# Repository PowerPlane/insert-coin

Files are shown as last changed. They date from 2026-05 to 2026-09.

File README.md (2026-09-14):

# Insert Coin

> A series of interactive business cards that come to life when you insert a CR2032 coin cell.
> Inspired by the Target gift cards of the early 2000s.

The "Insert Coin" cards are PCB-as-business-card builds where the coin cell is the *user interaction*: slide it into the holder and the card boots, blinks, listens, taps NFC, then sleeps. Different variants explore different form factors, sensor sets, and animations under the same playful idea.

## Variants

| Slug | Form factor | MCU | Status | Notes |
|---|---|---|---|---|
| [`business-card-v1`](variants/business-card-v1/) | Business card (85 × 54 mm) | ATtiny1616 | Hardware done, firmware pending | 24-LED matrix, MEMS mic, ST25DV04K NFC tag |

## Repo layout

```
insert-coin/
├── docs/                       # cross-variant notes, photos, renders
├── shared/                     # things reused across variants
│   ├── kicad/                  # symbols, footprints, 3D models
│   ├── firmware/               # shared HAL/drivers (LED matrix, NFC, mic)
│   └── tools/                  # build-hex.sh, gerber gen helpers
└── variants/<slug>/
    ├── hardware/               # KiCad project + fab outputs
    ├── firmware/               # PlatformIO project (bringup + production envs)
    └── enclosure/              # 3D-printed sleeves / holders (CAD)
```

## Adding a new variant

Use the slug pattern `<form-factor>-v<n>`:
- `business-card-v2` — next rev of the business-card form factor
- `keychain-v1`, `coaster-v1`, `badge-v1` — new form factors

Copy the structure of `variants/business-card-v1/` (without the KiCad files) as a starting point.

## Firmware toolchain

[PlatformIO](https://platformio.org/) + [megaTinyCore](https://github.com/SpenceKonde/megaTinyCore) targeting the ATtiny1616 over **UPDI**. Default programmer: SerialUPDI through an FTDI USB-serial adapter (one 4.7 kΩ resistor between TX and RX). Per-variant `firmware/README.md` has the wiring diagram and build commands.

No PlatformIO on the machine? [`docs/flasher/`](docs/flasher/README.md) is a browser page at `ducky.davidyang.work/flash` that flashes a card through an Adafruit UPDI Friend. David builds the `.hex` with `shared/tools/build-hex.sh` and sends it; the page does the rest.

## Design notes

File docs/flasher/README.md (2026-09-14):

# The web flasher

Put firmware on an Insert Coin card from a browser. Nothing to install.

**https://ducky.davidyang.work/flash** · Chrome or Edge, on a laptop.

Made so a friend with an [Adafruit UPDI Friend](https://www.adafruit.com/product/5879)
can flash cards without PlatformIO. The page talks UPDI to the ATtiny1616
through the browser's Web Serial API, the same way `pio run -t upload`
does through avrdude. The firmware file never touches a server.

---

## 1 · Flashing a card (for whoever holds the UPDI Friend)

You need: a UPDI Friend, its cable, a card with a **fresh** CR2032 in it,
the `.hex` file David sent, and a laptop running Chrome or Edge.

1. **Set the UPDI Friend's switch to 3V.** The card runs at coin-cell
   voltage. 5V on the UPDI pin is out of spec for the chip.
2. **Wire two pins.** UPDI Friend `UPDI` to the card's `UPDI` pad, `GND`
   to `GND`. **Leave `VCC` unconnected.** The card is powered by its own
   coin cell while flashing.
3. **Open the page** and drop the `.hex` on it. It shows the file's size
   and the first eight characters of its SHA-256. Read those to David if
   you want to be sure it is the right file.
4. **Press Flash.** The first time, the browser asks which USB port; pick
   the UPDI Friend (it shows as a CH340 or "USB Serial"). Five rows tick
   off in about ten seconds: Connect, Check the chip, Write, Verify, Fuses.
5. **Done says the card's serial.** Pull the coin cell out, put it back,
   and the card should light up. The file stays loaded: swap the card and
   press Flash again.

If a row turns red, the page says what happened, whether the card is fine,
and what to check. **Show details** has the log if David asks for it.

| It says | It means | Do |
| --- | --- | --- |
| Open this in Chrome or Edge | This browser has no Web Serial. | Copy the link into Chrome or Edge on a laptop. Phones cannot do this. |
| The USB port is busy | Something else has the port open. | Close the Arduino IDE or any serial monitor, unplug and replug, press Flash. |
| The card did not answer | No reply on the UPDI wire. Nothing was written. | Coin cell in and fresh? UPDI on UPDI, GND on GND? Switch at 3V? Replug. |
| That is not an Insert Coin card | The chip is not an ATtiny1616. Nothing was written. | Check what the cable is clipped to. |
| Writing stopped part way | The card is half-written. | Fresh coin cell, then Flash again. Nothing is lost. |
| Read back differently | One byte did not stick. | Almost always the battery. Fresh cell, Flash again. Slow mode in Details if it repeats. |
| A setting did not take | Code is on; a fuse read back wrong. | Flash again. Twice in a row, send the card back with the details. |
| This chip is locked | Lock bits are set. This page does not erase locked chips. | Send the card back to David. |

---

## 2 · Making the file (for David)

```bash
shared/tools/build-hex.sh                 # production-pond → ~/Desktop
shared/tools/build-hex.sh bringup ~/tmp   # any env, any folder
```

It runs `pio run -e <env>`, copies the result out of `.pio/build/` with
the commit hash in the name, and prints the SHA-256. Send that file
however you like: AirDrop, email, a chat. Then read the first eight
characters of the hash to each other.

**The file is not hosted anywhere, and must not be.** The pond firmware
carries `FIRMWARE_SECRET`, the key every card signs its claims with. The
repository is public, so a committed or served `.hex` would publish the
key. The script refuses to build `production-pond` with the all-zero
placeholder key, because a card built with it never registers in the
pond and the only symptom is silence.

---

## 3 · How it works

```
 browser tab ── Web Serial ── USB ── UPDI Friend (CH340E + 1 kΩ) ── UPDI pin ── ATtiny1616
   flash.js                                                           ↑ card powers itself
```

The page bundles a TypeScript port of Microchip's SerialUPDI stack
([WebUPDI](https://github.com/manuelkasper/webupdi), MIT), so the
protocol on the wire is the one pymcuprog and avrdude speak. On top of it
sits a short, tested sequence:

1. **Connect** at 230400 baud; if the chip is silent, close the port and
   try 115200.
2. **Check the chip.** Read the device id. Anything but `0x1E9421` stops
   here, before a single write. Read the factory serial number and derive
   the card serial the same way the firmware and the server do.
3. **Write** all 256 flash pages: erase-and-write for pages with content,
   plain erase for blank ones.
4. **Verify** by reading the whole 16 kB back and comparing.
5. **Fuses.** Write the eight fuse bytes `platformio.ini` describes, read
   them back, compare.
6. **Leave programming mode.** The chip resets and boots the new code.

One order, no branches: the flasher does exactly this or stops with a
named reason.

---

## 4 · What it writes, and what it never touches

**Flash**: every page, from the `.hex`. Pages the file does not mention
are erased (0xFF), so nothing from an older firmware survives.

**Fuses**, byte for byte what `pio run -t fuses` would write from
`platformio.ini`. A test recomputes this table from the ini file with
PlatformIO's own rules, so the two cannot drift.

| Fuse | Value | Why |
| --- | --- | --- |
| WDTCFG | 0x00 | watchdog off |
| BODCFG | 0x00 | brown-out detector off, so the coin cell fades instead of reset-looping |
| OSCCFG | 0x02 | 20 MHz oscillator, divided to 10 MHz in code |
| TCD0CFG | 0x00 | defaults; the LED PWM sets TCD0 up itself |
| SYSCFG0 | 0xC5 | EEPROM kept across reflash, UPDI pin stays UPDI |
| SYSCFG1 | 0x06 | 32 ms start-up |
| APPEND | 0x00 | no application data section |
| BOOTEND | 0x00 | no bootloader |

Note that PlatformIO only writes fuses on `pio run -t fuses`, not on
`upload`. The web flasher writes them every time, so a card flashed here
has the fuses the ini asks for whether or not the bench ever ran that
target.

**Never touched:**

- **EEPROM.** The claim counter lives there (`provision.h`). The flasher
  uses page operations only and never issues a chip erase, so EEPROM is
  preserved even on a card whose EESAVE fuse was never set.
- **Lock bits.** Not written; a locked chip is refused rather than erased.
- **The user row.** Nothing on the card uses it.
- **The firmware sources.** This feature adds a page, a script and docs.
  No file under `variants/*/firmware/` changed.

---

## 5 · Where things live

```
pond/
  api/flash.ts                 the route (a function, like every HTML route)
  src/worker/flash-shell.ts    the page's HTML
  src/flasher/
    main.ts                    the page's behaviour: states, copy, port picking
    flasher.ts                 the sequence in § 3, over an interface a test can fake
    hex.ts                     Intel HEX → flash image, strict about what it accepts
    plan.ts                    image → page operations
    target.ts                  ATtiny1616 addresses and the fuse table
    explain.ts                 what the page says when it fails
    digest.ts                  SHA-256 of the dropped file
    serialupdi/                vendored WebUPDI, MIT; VENDORED.md lists every edit
  public/flash.js, flash.css   the committed bundle and stylesheet
  test/flasher-*.test.ts       hex, plan, fuse table vs platformio.ini, the flow
                               against a fake chip, the page against its script
shared/tools/build-hex.sh      David's side: build, name, hash, hand over
```

Design canvas (the screens, in the pond's language):
https://claude.ai/code/artifact/b278c922-17a4-4562-9c67-462ab4460528

---

## 6 · Decision log

| Decision | Chosen | Instead of | Why |
| --- | --- | --- | --- |
| Where the page lives | `/flash` on the pond, a Vercel function | GitHub Pages, a separate site | Deploys with the pond, inherits its security headers, and the pond already has the rule that every HTML route is a function. |
| Where the firmware comes from | Dropped on the page by the friend | Served from the page, fetched from a release | The pond `.hex` contains the signing key and the repo is public. Hosting it anywhere publishes the key. |
| Protocol stack | Vendored WebUPDI `serialupdi/` | Writing UPDI from scratch, `@types` + npm | It is a straight port of pymcuprog, MIT, and not on npm. Vendoring with a change list keeps updates a diff. |
| Only one chip | Refuse anything but `0x1E9421` | A device picker | A friend should not be choosing chips. A v2 board adds a second target, not a dropdown. |
| No chip erase | Page erase and erase-and-write on all 256 pages | Chip erase then write used pages | Chip erase wipes EEPROM unless EESAVE is already set, and PlatformIO's `upload` never sets fuses. Page ops leave EEPROM alone whatever the fuses say. |
| Fuses written every time | The eight bytes from `platformio.ini`, verified | Leave fuses as found | The ini is the spec; a card should not depend on whether the bench remembered `-t fuses`. Lock bits and reserved bytes are excluded. |
| Fuses after flash | Verify flash, then fuses | Fuses first | A failure part way leaves old fuses and new code, which still runs. |
| Baud | 230400 then 115200 | One baud, or a picker | megaTinyCore's tuned default first; the fallback covers a slow adapter. "Slow mode" in Details pins 115200 for the stubborn case. |
| Port picker filter | WCH and FTDI vendor ids | Every serial port | On a Mac the list otherwise includes every paired Bluetooth device; `platformio.ini` tells the story of the Bose speaker. Details has "show every port". |
| Verification | Whole flash read back, and fuses read back masked for reserved bits | Trust the write | A weak coin cell is the realistic failure and a silent one. |
| File identity | SHA-256 shown on both ends | Version strings in the file | Two humans reading eight characters to each other needs no format and survives renaming. |
| Errors | Named codes, plain copy, `touched` flag | The stack's messages | The person reading has a card in their hand. The copy says whether it is fine before it says what to try. |
| Copy language | English only | The pond's bilingual strings | Two readers, both known. |
| Reviews | `/code-review` after each phase | `codex:rescue` | That skill is not available in this session; noted, not substituted silently. |

---

## 7 · Change log

| Date | Change | Why |
| --- | --- | --- |
| 2026-09-14 | Web flasher added at `/flash` | Flash cards from a browser with a UPDI Friend, no PlatformIO. |
| 2026-09-14 | `shared/tools/build-hex.sh` | One command to build, name and hash the file to send. Refuses the placeholder key. |
| 2026-09-14 | Vendored WebUPDI with fixes | Double break was not awaited (one break, not two); read timeouts were never cleared; `device` typed instead of `any`. |
| 2026-09-14 | Baud fallback releases the port between attempts | A leaked port made the second attempt report "port busy" for a loose wire. Found in review. |
| 2026-09-14 | Extended addresses multiplied, not shifted | `0x8000 << 16` is negative in JavaScript, and the data silently vanished. Found in review. |
| 2026-09-14 | `[hidden]` rule in flash.css | Flex containers outranked the browser's `hidden`; every state showed at once. Found in review. |
| 2026-09-14 | Deploy-shape test checks every bundle | It compared `main.js` only, so a stale `flash.js` would have shipped. |
| 2026-09-14 | Link errors named by the phase they interrupt | A wire slipping during verify was reported as a half-written card. Found in review. |
| 2026-09-14 | A newer AVR family is "wrong chip", not "no answer" | An AVR Dx answers the SIB and was retried at every baud, then blamed on wiring. Found in review. |
| 2026-09-14 | `vercel.json` no-cache rule covers the bundles that exist | The rule named `app.js`, which is not a file; `main.js` and `admin.js` were never covered. The flash rule had copied the mistake. |

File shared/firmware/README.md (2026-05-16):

# shared/firmware

Reusable firmware modules that span multiple variants.

Empty for now — populate as patterns emerge while writing `business-card-v1`'s bring-up and production firmware. Likely first extractions:

- **LED matrix driver** — charlieplexing / row-column scanning helpers, ISR-driven from TCD0.
- **ST25DV04K NFC tag driver** — I²C wrapper for reading/writing the user EEPROM (NDEF URL records).
- **Mic envelope tracker** — ADC sampling + low-pass envelope, threshold-based wake.
- **Coin-cell power management** — sleep helpers tuned for the CR2032 budget (deep sleep with RTC wake, peripheral power-gating).

When extracted, each module should be drop-in includable from a variant's `firmware/<env>/src/` via PlatformIO's `lib_extra_dirs` or a `lib_deps` `file://` reference.

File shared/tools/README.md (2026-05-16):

# shared/tools

Helper scripts that aren't variant-specific.

Empty for now. Expected occupants:

- `flash.sh` — convenience wrapper around `pio run -e <env> -t upload` that picks up the FTDI port automatically.
- `gen-gerbers.sh` — KiCad CLI command for regenerating fab outputs without opening the GUI.
- `bom-merge.py` — merge a variant's `bom.csv` with shared part-numbers from a master spreadsheet, if we ever centralize sourcing.

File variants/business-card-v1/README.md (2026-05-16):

# business-card-v1

The first Insert Coin variant: a 2-layer PCB cut to standard business-card size with a CR2032 holder on the front, a 24-LED matrix, a MEMS microphone, and an NFC tag.

## Highlights

| | |
|---|---|
| **Form factor** | Business card — roughly 85 × 54 mm |
| **MCU** | ATtiny1616-M (Microchip, AVR tinyAVR 1-series, 16 kB flash, 2 kB SRAM, VQFN-20) |
| **Power** | CR2032 coin cell (the "coin" you insert to activate the card) |
| **Display** | 24 × red LEDs driven through 9 MOSFETs (multiplexed matrix) |
| **Audio in** | 1 × MEMS microphone (ZTS6156) — sound-reactive interaction |
| **NFC** | ST25DV04K-IER8C3 (I²C dynamic NFC tag, 4 Kb EEPROM, tap-to-launch URL) |
| **Programming** | UPDI (single-wire) via SerialUPDI |

## Status

- ✅ **Hardware**: Schematic + layout complete (KiCad), fab package generated.
- ⏳ **Firmware**: Bring-up and production firmware planned — see [`firmware/`](firmware/).
- ⏳ **Enclosure**: 3D-printed sleeve / mailer holder — see [`enclosure/`](enclosure/).

## Known caveats

- The fab zip inside [`hardware/production/`](hardware/production/) is named `Ducky-Business-Card_0-1.zip` — a leftover from a forked fabrication-toolkit config. The board *itself* is the Insert Coin design; only the zip filename is wrong. Will be corrected on the next fab run.

## Hardware files

- `hardware/Insert-Coin-Business-Card.kicad_pro` — open this in KiCad to view the schematic and PCB.
- `hardware/production/` — BOM (`bom.csv`), pick-and-place positions (`positions.csv`), designator map, IPC netlist, and the (mis-named) fab zip.

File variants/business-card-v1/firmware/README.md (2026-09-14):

# business-card-v1 firmware

Two PlatformIO environments in one project share the same `platformio.ini`:

| Env | Purpose |
|---|---|
| **`bringup`** | Smoke tests for each subsystem — exercise every LED, read the mic, scan I²C for the NFC tag, verify sleep/wake. The first thing you flash on a freshly-soldered card. |
| **`production`** | The real interactive firmware: boot animation, idle low-power, mic-reactive pattern, NFC-tap drops a URL. The firmware that ships on cards you hand out. |

The actual source code is **not yet written** — that's the next session. The `src/` folders are empty placeholders.

## Toolchain

- **[PlatformIO Core](https://platformio.org/install/cli)** (`pip install platformio` or via Homebrew).
- **[megaTinyCore](https://github.com/SpenceKonde/megaTinyCore)** — pulled in automatically by `platformio.ini`. This is the Arduino-style core for the tinyAVR 0/1/2-series and exposes the ATtiny1616's modern peripherals (Event System, Configurable Custom Logic, TCD high-res timer) as easy-to-use APIs.

## Programmer wiring

> **No PlatformIO handy?** `docs/flasher/README.md` describes a browser page that flashes a built `.hex` through an Adafruit UPDI Friend. Same fuses, same result. Build the file here with `shared/tools/build-hex.sh`.

The ATtiny1616 uses **UPDI**, Microchip's 1-wire programming protocol. No bootloader is required (and no bootloader is on the board) — UPDI talks directly to the chip's NVM controller.

### Primary path: SerialUPDI via FTDI (recommended)

```
   FTDI TX ──[ 4.7 kΩ ]──┬── UPDI pin on card
                          │
   FTDI RX ───────────────┘
   FTDI GND ─────────────────── GND on card
```

- The single resistor between TX and RX merges them into the half-duplex UPDI line.
- Power the card from the CR2032 during flashing — **do not back-feed Vcc from the FTDI**, the LDO and chip share a node sized for the coin cell.
- Upload speed: 230400 baud (megaTinyCore's tuned default).

`platformio.ini` is preconfigured for this path. Set `upload_port` to your FTDI:

```bash
ls /dev/cu.usbserial-* /dev/cu.usbmodem*    # find your adapter on macOS
pio run -e bringup -t upload --upload-port /dev/cu.usbserial-XXXX
```

### Fallback path: jtag2updi on an Arduino Nano

If the FTDI is unavailable, flash the [`jtag2updi`](https://github.com/ElTangas/jtag2updi) sketch onto an Arduino Nano once (it becomes a permanent UPDI programmer), then:

```
   Nano D6 ──[ 4.7 kΩ ]── UPDI pin on card
   Nano GND ────────────── GND on card
```

Switch the env's `upload_protocol` to `jtag2updi`:

```ini
upload_protocol = jtag2updi
upload_speed    = 19200
```

Slower than SerialUPDI but works fine for low-iteration use.

## Fuse / clock settings

Configured in `platformio.ini` so they're consistent across builds:

- `F_CPU = 10000000` — 10 MHz internal oscillator. The 20 MHz option is more headroom but eats more current; 10 MHz is the megaTinyCore default and friendlier to the CR2032 budget.
- **BOD off** — Brown-Out Detector disabled. BOD continuously sips ~20 µA which dominates the sleep current; the card is supposed to *gracefully* die when the coin cell sags, not reset-loop.
- Millis timer: **TCB0** (so TCD0 stays free for high-resolution LED PWM later).

## Build & flash

```bash
cd insert-coin/variants/business-card-v1/firmware

pio run -e bringup              # compile bring-up
pio run -e bringup -t upload    # flash bring-up
pio device monitor -b 115200    # open serial (if UART debug is wired)

pio run -e production -t upload # flash production firmware
```

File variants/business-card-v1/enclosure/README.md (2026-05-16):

# business-card-v1 enclosure

Placeholder for the 3D-printable sleeve / display holder. Drop CAD files here as they're designed:

- `*.f3d` — Fusion 360 source files
- `*.step` — neutral CAD interchange (preferred for sharing)
- `*.stl` — slicer-ready meshes
- `*.3mf` — preferred print-job format (slicer settings travel with the geometry)

Likely first artifact: a thin cardboard-sleeve-style mailer holder that exposes the LED window and the coin-cell slot, so the card can be handed out without the cell pre-inserted.

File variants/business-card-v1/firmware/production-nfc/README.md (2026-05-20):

# production-nfc firmware

(Same overall behavior as `production/`, plus a post-reveal I2C patch
of the ST25DV04K NDEF EEPROM so a phone tap surfaces the fortune
result. See `docs/nfc-ducky/` for the on-tag URL contract and the
Cargo.site snippet.)

Interactive firmware for business-card-v1. One coin insertion = one fortune.

## What it does

Coin makes contact → MCU boots → runs a single forward pass:

1. **Boot capture** — bank 0 (ducky frame 1) eases up to full, dips, recovers, holds.
2. **Ducky walk** — banks 0→1→2→3 hard-cut stop-motion with eased dwell pacing.
3. **Lottery** — slot-machine spin across banks 4 / 5 / 6 / 7+8, then a hardware-seeded random pick from { great, little, uncertain, bad }.
4. **Reveal** — per-fortune scene (see below).
5. **Sleep forever** — `SLEEP_MODE_PWR_DOWN` with no wake source. Pull the coin to reset.

## Reveal scenes

| Fortune | Bank(s) | Animation |
|---|---|---|
| Great luck | 4 | 3× blink, 15 s static hold (sleeps through the hold) |
| Little luck  | 5 | 2× blink, 15 s static hold (sleeps through the hold) |
| Uncertain | 6 | Eased ramp, then eased breathing for ~15 s, soft fade-off |
| Bad luck | 7+8 | Two-stream candle flicker until mic detects a sustained blow (≥100 ms above threshold), then a flare-up + fast fade. 60 s timeout. |

The NFC tag (ST25DV04K) is RF-powered and ignored by the MCU — tap-to-URL works independently of the coin.

## Power

- BOD off, `millis()` on TCB0, ADC0 disabled at boot, ADC1 disabled after the lottery on non-fire reveals.
- 15 s holds use the RTC PIT at 1 Hz to drop into deep sleep with the GPIO output latched high — chip current goes from ~5 mA active to <10 µA while the bank stays lit.
- After the show: `sleep_forever()` disables both ADCs, kills every input buffer except UPDI, and parks in `PWR_DOWN` until cold boot.
- Target: < 1 µA quiescent after shutdown, comfortable headroom on a CR2032 for hundreds of activations.

## Source layout

```
src/
  main.cpp            entry point; runs the show then sleeps
  anim.{h,cpp}        scripted scenes (boot capture, walk, lottery, reveals)
  flame.{h,cpp}       two-stream candle flicker for banks 7+8
  pwm.{h,cpp}         9-bank software PWM with eased fade/hold helpers
  mic.{h,cpp}         ADC1 envelope + raw-threshold blow detector
  rng.{h,cpp}         xorshift32 seeded from ADC LSB noise on the mic pin
  sleepy.{h,cpp}      RTC-PIT timed sleep + terminal deep sleep
  leds.{h,cpp}        bank MOSFET driver (verbatim from bringup)
  pins.h              pin map + bank/fortune semantic indices
  unused_pins.h       input-buffer-disable for everything PCB-unused
  config.h            all timings, thresholds, RNG sample counts
```

## Build & flash

```
cd insert-coin/variants/business-card-v1/firmware
pio run -e production-nfc
pio run -e production-nfc -t upload --upload-port /dev/cu.usbserial-XXXX
```

`FORCE_FORTUNE` (set in `config.h` or via `-DFORCE_FORTUNE=3` build flag) skips the lottery for blow-out tuning. Defaults to `-1` (real RNG).

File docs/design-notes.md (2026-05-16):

# Insert Coin — design notes

Concept and constraints that apply across variants. Variant-specific notes belong in `variants/<slug>/README.md`.

## The concept

The card does nothing until you slide a CR2032 into the holder. That gesture *is* the interaction — the "insert coin" of an arcade cabinet, the "scratch here" of a Target gift card from 2002. The card lights up briefly, listens, responds, then quiets down.

Each variant should preserve that core feel: **no buttons, no switches, no USB.** Inserting the coin is the only thing you do.

## Shared constraints

| | |
|---|---|
| **Power budget** | 1 × CR2032 = 220 mAh nominal at ~3.0 V. Drops to ~2.5 V when loaded; firmware must work down to ~2.2 V before the chip's POR catches it. Aim for a card to last *weeks* of casual use. |
| **Average current target** | < 300 µA averaged over a use session (~30 s active, then sleep). Active LED bursts can briefly exceed 10 mA — but only briefly. |
| **Sleep-current target** | < 1 µA when idle. BOD off; peripherals power-gated. |
| **Dimensions** | Roughly business-card: 85 × 54 mm. Some variants may push past this (keychain, badge), but stay pocketable. |
| **Toolchain** | KiCad 8+ for hardware, PlatformIO + megaTinyCore for firmware. UPDI for flashing. |
| **Cost target** | Sub-$5 BOM at low-quantity JLCPCB pricing — the card has to feel "spendable" when handed out. |

## Aesthetic direction

- **Target gift-card-of-2002 nostalgia** — soft red LEDs, mild glow, suggestion of arcade neon without going full RGB.
- **Silkscreen as decoration** — treat the silk layer like print design, not just labels. White-on-black or black-on-white, generous negative space.
- **No exposed ICs on the show side** — the MCU, NFC tag, mic, MOSFETs all live on the back. The front is "the artwork".

## Open ideas (not committed)

- A variant where the "coin" is actually a small magnet that triggers a Hall-effect sensor instead of being a literal CR2032 (then the *real* battery is a sewn-in lithium primary). Preserves the gesture, removes the power constraint.
- A variant where the LED matrix is replaced with a small e-paper segment showing a portfolio QR — better battery life, less "alive" feeling.
- A variant designed to be mailed: the cardboard holder *is* the enclosure, and the recipient inserts the coin from the holder.

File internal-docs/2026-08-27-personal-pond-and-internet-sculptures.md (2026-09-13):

# Personal Pond and Internet Sculptures

Date: 2026-08-27

## Decision

Insert Coin is a personal fortune journal expressed as a pond. A physical card creates a fortune. The phone that taps it owns a private pond, and every completed tap adds another decorated fortune to that pond.

An entry represents a moment, not a person. Its durable content is:

- the fortune selected by the card
- an optional intention for the day
- the tint, stickers, and paint used to decorate it
- its creation date and physical-card provenance

The visitor flow does not expose names, contact sharing, bumping, reporting, speech, keeper offers, or public entry links. Historical public entries and their administration remain in the database until a separate removal decision is made.

## Identity and persistence

The first implementation uses the existing opaque `pond_v` browser cookie as the pond identity. The server hashes its high-entropy random value before storing it on an entry. It deliberately does not derive this identity from `SESSION_SECRET`, because rotating an operational signing secret must not orphan durable ponds. The cookie is not the fortune store: Turso stores the entries, while the cookie only tells the server which rows to return.

This gives one stable pond per browser profile:

- A repeat tap during an unfinished fortune resumes the pending session.
- A repeat tap after a completed fortune creates another session and entry.
- A different browser or phone gets a different pond.
- A guessed personal slug returns 404.

This is a useful first boundary, but it is not account recovery. Clearing site data or changing phones loses the pointer to the pond even though the database rows remain. Local storage is used only for an unfinished decoration draft and the most recent edit credential.

## Recovery design

The next persistence slice should add one recovery credential per pond, not one link per fortune. Generate a high-entropy recovery token, store only its hash, and expose a route such as `/p/<token>` that restores the signed pond cookie after an explicit confirmation.

The recovery credential can be presented as a link and QR code. It should support:

- restoring a pond after browser data is cleared
- moving the pond to a new phone
- optionally adding a second device without merging anonymous browser identities

Do not use email as the primary identity unless the product deliberately becomes an account system. Do not put the raw recovery token into analytics, logs, or the entry table. A pond-level credential avoids making people save a separate secret for every fortune.

The physical device should eventually provide a unique play identifier in each signed NFC URL. Without it, the server can distinguish an unfinished session from a completed session, but it cannot distinguish a legitimate later insertion from a replay of the same still-live five-minute URL. A signed monotonic play counter or random nonce written for each insertion closes that gap and gives the entry a natural idempotency key.

## Keeper claim

The firmware listens for four distinct rises in the blow sensor while the result animation is active. One continuous breath counts once. On four blows, it skips the ordinary fortune URL, increments the card's persistent claim counter, signs the card serial and counter, and writes the claim URL to NFC.

The server verifies the signature and requires the counter to exceed the stored high-water mark before it opens, resumes, or transfers a keeper epoch. The gesture is therefore physical proof that someone is holding the card, while the counter prevents replay.

The personal pond does not need keeper identity in its visitor experience. Keeper claim remains useful only if physical card custody, owner configuration, or handoff becomes part of the sculpture. It should not be used as a user account or a way to join ponds.

## URL-to-session exchange

The NFC URL's fortune digit is valid for five minutes, but decorating may take longer. The first page request verifies the signed card data and exchanges the digit for a thirty-minute server session. The session id is stored in a signed, HTTP-only cookie. Release endpoints read the session, not the original URL.

An unspent session wins over a repeat tap so work is not orphaned. A spent session may be replaced, allowing the same phone to accrue another fortune.

## Reports

The historical report endpoint writes a row to the Turso `reports` table with the entry id, hashed visitor, reason, optional note, and creation time. Unresolved counts appear in the password-protected `/pondkeeper` admin interface, where they can be marked resolved. Reports do not currently send email, webhooks, or external notifications.

Personal entries do not expose a report action because the pond contains only that visitor's entries. The endpoint remains for historical public entries.

## Internet Sculptures integration

The Webstones repositories currently separate three responsibilities:

- `webstones` is the shop and object catalog.
- `shrine.computer` hosts the web experiences, including the current Fortune Webstone.
- Touchstone and QiQi register known objects and static NFC destinations for companion-device use.

Insert Coin should join this suite as a first-class Internet Sculpture, not as a configuration mode of the existing Fortune Webstone. The existing Fortune Webstone is a passive tag whose per-tag configuration lives in Cloudflare KV. Insert Coin has an active microcontroller, generates a fresh fortune event, and needs private append-only history. Treating them as the same object would erase the most important difference in how they behave.

Recommended integration:

1. Add Insert Coin to the Webstones object catalog with a product story and non-interactive preview.
2. Give the experience a stable suite URL such as `https://shrine.computer/pond`, while keeping firmware and Pond implementation ownership in this repository.
3. Back the personal pond with a relational store such as Cloudflare D1 or the existing Turso database. Do not put fortune history or recovery tokens in the current `fortuneConfigurations` KV namespace.
4. Add Touchstone support only when there is meaningful owner configuration, such as intention prompts, language, privacy, or recovery. A launcher tile alone does not justify companion registration.
5. Require signed play ids and a pond-level recovery credential before calling cross-device persistence complete.

The suite story is: Webstones catalogs the sculpture, `shrine.computer` gives it a stable public home, the physical Insert Coin object creates each event, and the private pond lets the event accumulate into a personal ritual over time.

## Hosting and database decision

Keep Vercel and Turso for the personal-pond release. The expected load is far below the free allowances of either platform, so a migration would not solve a capacity problem. The current choice also preserves `ducky.davidyang.work` as a single CNAME while the `davidyang.work` zone remains outside Cloudflare.

Turso is the authoritative fortune store, not a backup for browser storage. The browser contains only the anonymous pond cookie, an unfinished one-hour draft, a cooldown display deadline, and the latest per-entry edit credential. Removing Turso without replacing it with another server database would remove the durable pond.

Cloudflare D1 is a reasonable later destination because the application already speaks through a D1-shaped database interface and the Internet Sculptures server already runs on Cloudflare Workers. Move when the experience moves under a Cloudflare-controlled suite hostname and one operational owner is worth more than preserving the existing deployment. Do not move for anticipated load alone.

Before any database migration:

1. Add pond-level recovery so a user can prove that the rows survived the move from a second browser.
2. Export and checksum a SQLite-compatible backup.
3. Rehearse every migration and the database verification script against D1.
4. Run Turso and D1 in a short, explicit cutover window; do not introduce indefinite dual writes.
5. Verify the NFC URL, session exchange, release, recovery, and personal pond through the production hostname before retiring Turso.

Keep an independent periodic export even though Turso provides point-in-time restore. Provider restore protects against recent mistakes; an export protects against account, retention-window, or provider-level loss.

## Companion PWA boundary

The companion PWA should recognize Insert Coin only after it has an owner operation worth exposing. A catalog tile or launcher is not enough. The first useful surface is pond recovery and transfer:

- show a recovery QR or link
- attach this browser to an existing pond after confirmation
- rotate the recovery credential
- export or delete the pond
- show the card identity and last successful connection as diagnostics

Language or a small set of curated intention prompts can follow if testing shows that owners need them. Do not expose arbitrary fortune editing by default; surprise is part of this sculpture's ritual, and the existing Fortune Webstone configuration model describes a different object.

The current companion architecture needs two changes before it can safely own this configuration:

- Registration currently prevents more than one instance of an object type, but people may own or administer multiple Insert Coin cards. Registration must be unique by physical card, not only by catalog object id.
- The existing Fortune Webstone endpoint accepts configuration writes keyed by a tag id without authenticating ownership. Insert Coin recovery, deletion, and owner settings must require proof of physical custody, such as the signed four-blow keeper claim, followed by a revocable owner session. A scanned or typed tag id is not authority.

Do not use Web NFC to rewrite the Insert Coin tag from the PWA. The microcontroller owns its changing signed URL, Web NFC is not available on iOS, and a browser-written static URL would bypass the physical fortune event. The PWA may consume a signed claim URL to establish ownership, but firmware remains responsible for NFC contents.

## Explicit non-goals for this slice

- No accounts or email login.
- No cross-device recovery yet.
- No merging ponds created by different browser identities.
- No social graph, public feed, messaging, bumping, or contact exchange.
- No deletion of historical social tables or keeper firmware.
- No migration of an old public duck into a visitor's private pond.

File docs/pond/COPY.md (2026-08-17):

# The pond — copy deck

Every word the product says, in both languages.

**Generated, not hand-written.** Change a string in
`pond/src/client/strings.ts`, run `python3 pond/tools/extract-copy.py`,
and it shows up here. Editing this file by hand only makes it wrong.

172 strings.

---

## 01 · Arrival — the fortune you were dealt

| Key | English | 繁體中文 | Kind |
| --- | --- | --- | --- |
| `arrival.01` | Your fortune | 你的運勢 | Body |
| `arrival.02` | 大吉 · Great luck | 大吉 | Heading |
| `arrival.03` | No one else got this duck today. Decorate it or release it as is. | 今天沒有人抽到這隻鴨子。裝飾一下，或直接放進池塘。 | Body |
| `arrival.04` | Decorate it | 裝飾它 | Button |
| `arrival.05` | Just look around | 先看看就好 | Button |

## 02 · Studio — decorating the duck

| Key | English | 繁體中文 | Kind |
| --- | --- | --- | --- |
| `studio.01` | Back | 返回 | Button |
| `studio.02` | Make it yours | 做成你的鴨子 | Body |
| `studio.03` | Skip | 略過 | Button |
| `studio.04` | Your duck. Tap to place or drag a sticker. | 你的鴨子。點一下放置，或拖曳貼紙。 | Screen reader |
| `studio.05` | Undo | 復原 | Screen reader |
| `studio.06` | Clear everything | 全部清除 | Screen reader |
| `studio.07` | Surprise me | 隨機來一個 | Screen reader |
| `studio.08` | Colour | 顏色 | Button |
| `studio.09` | Stickers | 貼紙 | Button |
| `studio.10` | Draw | 塗鴉 | Button |
| `studio.11` | Body | 身體 | Body |
| `studio.12` | Brush | 筆刷 | Body |
| `studio.13` | 1× | 1× | Button |
| `studio.14` | 2× | 2× | Button |
| `studio.15` | Erase | 擦掉 | Button |
| `studio.16` | Colour | 顏色 | Body |
| `studio.17` | Next | 下一步 | Button |
| `studio.18` | Drag stickers to move them. Nothing is required. | 拖曳貼紙可以移動。不加也可以。 | Body |
| `studio.19` | Nothing here is required. | 這裡什麼都不用改也可以。 | Body, on the other tabs |

## 03 · Sign — a name and a message

| Key | English | 繁體中文 | Kind |
| --- | --- | --- | --- |
| `sign.01` | Sign it | 簽名 | Body |
| `sign.02` | Name your duck | 幫鴨子取個名字 | Heading |
| `sign.03` | Name | 名字 | Field label |
| `sign.04` | Sam | Sam | Placeholder |
| `sign.05` | 0 | 0 | Body |
| `sign.06` | Message | 留言 | Field label |
| `sign.07` | Say something | 說點什麼 | Placeholder |
| `sign.08` | Everyone who taps a card can see your name and message. | 每個感應卡片的人都看得到你的名字和留言。 | Privacy note |
| `sign.09` | Next | 下一步 | Button |

## 04 · Contact — leaving a way to be reached

| Key | English | 繁體中文 | Kind |
| --- | --- | --- | --- |
| `contact.01` | Optional | 可以不填 | Body |
| `contact.02` | Leave a way to reach you | 留下聯絡方式 | Heading |
| `contact.03` | Your duck goes in either way. | 不留也沒關係，鴨子一樣會下水。 | Body |
| `contact.04` | Email, phone, handle or address | Email、電話、帳號或地址 | Field label |
| `contact.05` | you@example.com | you@example.com | Placeholder |
| `contact.06` | Only David sees this. It never appears in the pond, and it goes when your duck does. | 只有 David 看得到。不會出現在池塘裡，鴨子帶走時也會一起刪掉。 | Privacy note |
| `contact.07` | Release my duck | 放我的鴨子下水 | Button |
| `contact.08` | Skip contact | 略過聯絡方式 | Button — no longer rendered |
| `contact.09` | Leave a postal address and David might send a postcard. | 留下地址的話，David 可能會寄張明信片給你。 | Body |

## 04 · Contact — who may see it

| Key | English | 繁體中文 | Kind |
| --- | --- | --- | --- |
| `scope.01` | Who can see this | 誰可以看到 | — |
| `scope.02` | Only David | 只有 David | — |
| `scope.03` | Only {keeper} | 只有 {keeper} | — |
| `scope.04` | {keeper} and David | {keeper} 和 David | — |
| `scope.05` | David runs the pond and answers the post. | David 經營這個池塘，也會回信。 | — |

## 06 · The pond

| Key | English | 繁體中文 | Kind |
| --- | --- | --- | --- |
| `pond.01` | 14 ducks | 14 隻鴨子 | Button |
| `pond.02` | David's Pond — who made this. Opens davidyang.work in a new tab. | David's Pond — 這是誰做的。會在新分頁打開 davidyang.work。 | Screen reader |
| `pond.03` | Show everyone again | 重新顯示全部 | Screen reader |
| `pond.04` | Whistle for | 吹哨找 | Body |
| `pond.05` | Back to the whole pond | 回到整個池塘 | Screen reader |
| `pond.06` | Zoom in | 放大 | Screen reader |
| `pond.07` | + | + | Button |
| `pond.08` | Zoom out | 縮小 | Screen reader |
| `pond.09` | − | − | Button |
| `pond.10` | Say something | 說點什麼 | Screen reader |
| `pond.11` | Find my duck | 找我的鴨子 | Button |
| `pond.12` | Your duck settings | 你的鴨子設定 | Screen reader |
| `pond.13` | Ducks in the pond | 池塘裡的鴨子 | Screen reader |
| `pond.14` | Your duck is in | 你的鴨子下水了 | Body |
| `pond.15` | Keep this link | 留著這個連結 | Heading |
| `pond.16` | No accounts. Use this to edit, redecorate, or take your duck out. | 沒有帳號。用這個連結修改、重新裝飾，或把鴨子帶走。 | Body |
| `pond.17` | Your private link | 你的私人連結 | Field label |
| `pond.18` | ducky.davidyang.work/e/9fQ2xK7pLm | ducky.davidyang.work/e/9fQ2xK7pLm | Example value |
| `pond.19` | Copy | 複製 | Button |
| `pond.20` | Text | 簡訊 | Button |
| `pond.21` | Email | 電子郵件 | Button |
| `pond.22` | Done | 完成 | Button |
| `pond.23` | Close | 關閉 | Screen reader |
| `pond.24` | 小吉·Little luck | 小吉 | Body |
| `pond.25` | Mika | Mika | Body |
| `pond.26` | via Sam · 4 Aug | 來自 Sam · 8 月 4 日 | Body |
| `pond.27` | found this card at the bar | 在酒吧撿到這張卡片 | Body |
| `pond.28` | Most bumps from | 碰最多次的是 | Body |
| `pond.29` | What's wrong with it? | 哪裡有問題？ | Body |
| `pond.30` | Rude or abusive | 不友善或辱罵 | Button |
| `pond.31` | Private details | 個人資料 | Button |
| `pond.32` | Spam | 垃圾訊息 | Button |
| `pond.33` | Something else | 其他 | Button |
| `pond.34` | Anything to add | 想補充什麼 | Field label |
| `pond.35` | Anything to add — optional | 想補充什麼 — 可以不填 | Placeholder |
| `pond.36` | Send report | 送出檢舉 | Button |
| `pond.37` | Cancel | 取消 | Button |
| `pond.38` | Bump · 6 | 碰一下 · 6 | Button |
| `pond.39` | Report | 檢舉 | Button |
| `pond.40` | Copied | 已複製 | Button, once the link is on the clipboard |
| `pond.41` | David's Pond | David's Pond | The mark on the water |
| `pond.42` | Your duck at David's Pond.\n\n{url}\n\nThere are no accounts, so this link is the only way back to it. Keep it. | 你在 David's Pond 的鴨子。\n\n{url}\n\n這裡沒有帳號，這個連結是唯一找回牠的方法，記得留著。 | SMS body |
| `pond.43` | Your duck at David's Pond | 你在 David's Pond 的鴨子 | Email subject |
| `pond.44` | This is the link to your duck in the pond:\n\n{url}\n\nThere are no accounts here, so this link is the only way back to it. Use it to change your duck, redecorate it, or take it out of the pond.\n\nKeep it somewhere you will find it again. | 這是你在池塘裡那隻鴨子的連結：\n\n{url}\n\n這裡沒有帳號，所以這個連結是唯一找回牠的方法。你可以用它修改鴨子、重新裝飾，或把牠帶走。\n\n記得存在之後找得到的地方。 | Email body |

## 07 · Your duck's own screen

| Key | English | 繁體中文 | Kind |
| --- | --- | --- | --- |
| `manage.01` | Your duck | 你的鴨子 | Body |
| `manage.02` | Message & settings | 留言與設定 | Heading |
| `manage.03` | Your message | 你的留言 | Field label |
| `manage.04` | Email, phone, @handle, or address | Email、電話、@帳號或地址 | Field label |
| `manage.05` | Your private link | 你的私人連結 | Field label |
| `manage.06` | ducky.davidyang.work/e/9fQ2xK7pLm | ducky.davidyang.work/e/9fQ2xK7pLm | Example value |
| `manage.07` | Taking your duck out deletes its message and contact at the same time. Nothing is kept. | 把鴨子帶走時，留言和聯絡方式會一起刪掉。什麼都不會留下。 | Privacy note |
| `manage.08` | Save changes | 儲存變更 | Button |
| `manage.09` | Take my duck out | 把我的鴨子帶走 | Button |
| `manage.10` | Its address in the pond | 池塘裡的地址 | Field label |
| `manage.11` | Letters, numbers and dashes | 英文字母、數字或 - | Placeholder |
| `manage.12` | Free | 可以用 | Hint, the address is available |
| `manage.13` | Taken | 有人用了 | Hint, somebody has it |
| `manage.14` | Three letters or more | 至少 3 個字元 | Hint, not a usable address |
| `manage.15` | Take back my contact | 刪掉聯絡方式 | Button |
| `manage.16` | If you left a way to reply, this deletes it. Your duck stays in the pond. | 如果你留了聯絡方式，這會把它刪掉。鴨子會留在池塘裡。 | Privacy note |
| `manage.17` | Done. Nobody can reply to you now. | 已完成。現在沒有人能回覆你了。 | Result |
| `manage.19` | Type here to set or replace how David can reply. Blank changes nothing. | 在這裡填，就能設定或更換 David 回覆你的方式；留白不會改動原本資料。 | Hint |
| `manage.20` | Save | 儲存 | Button, in the header row where there is no room for a sentence |
| `manage.21` | Copy | 複製 | Button, the private link |
| `manage.22` | Copied | 已複製 | Button, after copying |
| `manage.23` | Take it back | 刪掉 | Button, beside the hint that names what "it" is |

## 08 · Keeping a card

| Key | English | 繁體中文 | Kind |
| --- | --- | --- | --- |
| `keeper.01` | Card setup | 卡片設定 | Body |
| `keeper.02` | Set up this card | 設定這張卡片 | Heading |
| `keeper.03` | To change it, hold the card and blow again. | 想改的話，拿著卡片再吹一次。 | Body |
| `keeper.04` | Card name | 卡片名稱 | Field label |
| `keeper.05` | Sam | Sam | Example value |
| `keeper.06` | Ducks from this card say via Sam. | 這張卡片放出的鴨子會顯示「來自 Sam」。 | Hint |
| `keeper.07` | Link your duck | 連結你的鴨子 | Field label |
| `keeper.08` | Remove link | 移除連結 | Button |
| `keeper.09` | Make a duck | 做一隻鴨子 | Button |
| `keeper.10` | Paste duck link | 貼上鴨子連結 | Button |
| `keeper.11` | People can bump you back. | 別人就可以碰回來。 | Hint |
| `keeper.12` | Default language | 預設語言 | Field label |
| `keeper.13` | English | English | Button |
| `keeper.14` | 繁體中文 | 繁體中文 | Button |
| `keeper.15` | A visitor's phone can still choose another language. | 訪客還是可以在手機上選別的語言。 | Hint |
| `keeper.16` | Add the 12 earlier ducks to this card | 把先前的 12 隻鴨子加進這張卡片 | Field label |
| `keeper.17` | Save setup | 儲存設定 | Button |
| `keeper.18` | Not now | 現在不要 | Button |
| `keeper.19` | Keep this card yours | 把這張卡片留給自己 | Button — the offer in the pond bar |
| `keeper.20` | No thanks | 不用了，謝謝 | Button — declines the offer for this card |
| `keeper.21` | Keep it | 留下來 | Button — the sheet's primary |
| `keeper.22` | This card is yours | 這張卡片是你的 | Field label on your duck's settings |
| `keeper.23` | Card settings | 卡片設定 | Button |
| `keeper.24` | Take my name off | 把我的名字拿掉 | Button |
| `keeper.25` | Someone else keeps it now | 換別人保管 | Button |
| `keeper.26` | Your ducks stay in the pond and keep saying via you. The card goes back to being anybody's. | 你的鴨子會留在池塘裡，也還是會顯示來自你。卡片則會變回誰都可以拿。 | Body |
| `keeper.27` | Hand it on | 交出去 | Button — confirms |
| `keeper.28` | Keep it | 還是我保管 | Button — cancels handing on |
| `keeper.29` | Your name | 你的名字 | Field label |
| `keeper.31` | This card is already set up | 這張卡片已經設定過了 | Heading, keeper unnamed |
| `keeper.32` | Taking it over makes it yours: new ducks say your name instead, and nothing of theirs comes with it. Their ducks stay in the pond. | 接手之後就是你的了：之後放出的鴨子會顯示你的名字，也不會拿到對方的任何東西。他們的鴨子會留在池塘裡。 | Body |
| `keeper.33` | Take it over | 我要接手 | Button |
| `keeper.34` | Leave it as it is | 維持原樣 | Button |

## Set from code — button states and empty screens

| Key | English | 繁體中文 | Kind |
| --- | --- | --- | --- |
| `code.01` | Drag a sticker to move it · nothing is required | 拖曳貼紙可以移動 · 不加也可以 | Set from code |
| `code.02` | Finish my duck | 完成我的鴨子 | Set from code |
| `code.03` | Make a duck to bump | 先做一隻鴨子才能碰別人 | Set from code |
| `code.04` | Reported | 已檢舉 | Set from code |
| `code.05` | Reported ✓ | 已檢舉 ✓ | Set from code |
| `code.06` | Slide a coin in to get one | 投幣就能拿到一隻 | Set from code |
| `code.07` | This one is yours | 這隻是你的 | Set from code |

## Review scaffolding — not part of the product

| Key | English | 繁體中文 | Kind |
| --- | --- | --- | --- |
| `shared.01` | Tap ducks in the pond. Drag stickers in the studio. | 點池塘裡的鴨子。在工作室裡拖曳貼紙。 | Body |
| `shared.02` | Add 100 ducks | 加入 100 隻鴨子 | Button |
| `shared.03` | Reset | 重設 | Button |

## Everything else

| Key | English | 繁體中文 | Kind |
| --- | --- | --- | --- |
| `mine.01` | Welcome back | 歡迎回來 | Body |
| `mine.02` | Your duck | 你的鴨子 | Heading |
| `mine.03` | In the pond for six days. Four people bumped your duck. | 在池塘裡六天了。有四個人碰過你的鴨子。 | Body |
| `mine.04` | {names} bumped your duck. | {names} 碰過你的鴨子。 | Body, under the orbit |
| `mine.05` | Back to the pond | 回到池塘 | Button |
| `mine.06` | Redecorate | 重新裝飾 | Button |
| `mine.07` | Settings | 設定 | Button |
| `say.01` | Say something | 說點什麼 | Button, screen reader |
| `say.02` | Say something | 說點什麼 | Heading |
| `say.03` | Your duck says this for 45 seconds. | 你的鴨子會說 45 秒。 | Body |
| `say.04` | What's on your mind? | 想說什麼？ | Placeholder |
| `say.05` | Say it | 說出來 | Button |
| `say.06` | Not now | 先不要 | Button |
| `say.07` | One at a time — try again in {minutes} min. | 一次一句 — {minutes} 分鐘後再試。 | Error, cooldown |
| `say.08` | The pond isn't answering. Try again. | 池塘沒有回應，請再試一次。 | Error |
| `say.09` | Your duck settings | 你的鴨子設定 | Button, screen reader |

---

## Translation

Every string has both languages.

A handful are identical in both on purpose — names, an email example,
the language buttons. `test/strings.test.ts` keeps that list explicit, so
"identical" and "nobody has translated this yet" stay distinguishable.

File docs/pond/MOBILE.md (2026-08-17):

# The pond — mobile constraints

Everyone arrives by tapping a card with a phone. Almost all of them will be
in **iOS Safari** or **Android Chrome**, often inside an in-app browser
(Instagram, WhatsApp) that behaves like neither.

This is the checklist the client has to meet. Each item is something that
looks fine on a desktop and breaks on a phone.

---

## 1 · The viewport is a lie

`100vh` on iOS Safari is the height **with the address bar hidden**, which
is not the height you get on load. Use `100vh` as a fallback and let `100dvh`
win where supported:

```css
.app { height: 100vh; height: 100dvh; }
```

Otherwise the bottom of every screen — which is where every button lives —
sits under the address bar until the user scrolls.

## 2 · Safe areas

The home indicator and the notch overlap content unless you ask them not to:

```html
<meta name="viewport" content="width=device-width, initial-scale=1, viewport-fit=cover">
```

```css
padding-bottom: calc(16px + env(safe-area-inset-bottom, 0px));
padding-top:    calc(16px + env(safe-area-inset-top, 0px));
```

`viewport-fit=cover` is required or `env()` returns zero. Applied to the
arrival sheet, the duck card, and the pond's bottom bar.

## 3 · Inputs must be ≥16px

**iOS Safari zooms the entire page when you focus an input smaller than
16px, and does not zoom back out.** The user is then stuck at 1.4× on a
canvas app.

This is the single most common mobile-web bug and it is completely invisible
on a desktop. The name and message fields are `font-size: 16px` for exactly
this reason — not because 16px is the right visual size, but because
anything less is a trap.

## 4 · Tap targets

44 × 44 px minimum (Apple HIG, and WCAG 2.5.8 asks for 24 with spacing).
Everything interactive has `min-height: 44px`.

The one real tension is the **studio's paint grid at 24×24**, which puts
cells at about 12 px. Mitigated three ways rather than by growing the grid:
drag-painting instead of tapping, a 2× brush, and stickers that need no
precision at all. David tested this on his own phone and confirmed it works.

## 5 · Don't let the page move under a tap

- `touch-action: manipulation` on everything interactive kills the 300 ms
  double-tap-zoom delay.
- `touch-action: none` on the pond canvas so dragging a sticker doesn't
  scroll the page.
- `overscroll-behavior: contain` so pulling at the top of the pond doesn't
  bounce the whole document.
- **`focus({ preventScroll: true })`** when opening the duck card. A plain
  `.focus()` scrolls the focused element into view, which drags the page
  and makes the pond appear to jump. This was a real reported bug.

## 6 · Performance: the pond is the whole app

The pond is a full-screen canvas repainting continuously, on a phone, on
battery.

- **Water is drawn into a 1px-per-cell `ImageData` buffer** and scaled up
  with smoothing off. The obvious per-cell `fillRect` loop is 63,640 calls
  per frame — 17.8 ms measured on a *desktop*, most of the frame budget gone
  before a duck is drawn. The buffer is **0.7 ms**. Same pixels, 25× cheaper.
- **The stop-motion tick is a performance feature as well as a design one.**
  Eight to twelve repaints a second instead of sixty is most of the battery
  cost of this page gone, which matters for something people leave open on a
  table.
- Pause the render loop on `visibilitychange`. A backgrounded tab painting a
  canvas is pure waste.

## 7 · The tab will be killed

iOS reclaims backgrounded Safari tabs under memory pressure, silently. If
someone is picking a hat and switches apps to answer a message, they can
come back to a fresh page load.

- Every studio change writes a draft to `localStorage` (`api.ts`).
- The draft is restored for an hour.
- Nothing is cleared until the server confirms the release.

## 8 · Storage can throw

Private mode, quota limits, and locked-down in-app browsers all make
`localStorage` throw on write. Every access is wrapped — losing a draft is
bad, taking the whole flow down for it is worse.

## 9 · In-app browsers

Instagram and WhatsApp open links in a webview with quirks: sometimes no
`localStorage`, sometimes a broken back gesture, sometimes a different UA.

Detect and offer "open in browser" **before** the studio, not after — losing
work at the submit button is unforgivable.

## 10 · Accessibility, which is not separate from this

- **You cannot tab to a duck on a canvas.** The pond keeps a visually-hidden
  list of real `<button>`s in sync, so keyboard and screen-reader users can
  move duck to duck, hear "Mika's duck, little luck, 4 August", and press
  Enter for the same card.
- The duck card is a real `dialog`; Escape closes it; focus returns to where
  it came from.
- **Contrast is measured, not eyeballed:** panel name 11.1:1, message 6.6:1,
  both well past AA. This matters most outdoors, which is exactly where
  someone taps a card.
- **Dither is texture. Text always sits on a solid fill.** No exceptions.
- `prefers-reduced-motion` holds a single frame rather than removing
  feedback — the arrival still happens, it just doesn't animate.
- Flames flicker by **shape, never brightness**, over a tiny area. 70 ms is
  ~14 Hz, inside the band WCAG 2.3.1 restricts, and it is only safe because
  the luminance never swings.

## 11 · Colour is never the only carrier

Fortunes read by silhouette; the fortune is also written on the duck card.
This matters twice over: for colour-blind visitors, and because people
recolour their ducks, which would destroy the meaning if colour carried it.

---

## Checklist before shipping

- [ ] Real iPhone, Safari, outdoors, one-handed
- [ ] Real Android, Chrome
- [ ] Opened from inside Instagram's browser
- [ ] Rotate to landscape mid-decoration
- [ ] Background the tab for 10 minutes, come back
- [ ] Airplane mode at the release button
- [ ] VoiceOver: reach a duck, open its card, close it
- [ ] Reduced motion on
- [ ] Direct sunlight — is the water still readable behind the ducks?

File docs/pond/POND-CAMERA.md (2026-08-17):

# The pond — the camera

How the pond grows past the edge of the screen: zoom, pan, and the whistle
that finds your own duck.

What was built and why each part is the way it is. The shipped
implementation is `pond/src/client/pond-view.ts` and `camera.ts`; the
prototype is where it was worked out. Where this page and the code
disagree, the code wins.

---

## Zoom is `CELL`, and only integers

`CELL` is "device pixels per sprite pixel" — every draw is
`fillRect(x * CELL, y * CELL, CELL, CELL)`. Zoom is that constant:

```
2 · 3 · 4 · 6 · 8          4 is home
```

**Integers only, and this is the rule that protects the look.** At 4.7 px per
sprite pixel some pixels land on 4 and their neighbours on 5, so outlines
crawl. Every level is an exact multiple, so a duck is the same drawing,
larger.

Smooth motion between two integers is done by rendering at the **nearest**
integer and applying the leftover fraction as a CSS scale about the centre.
The remainder is at most ±25%, the canvas overscan covers it, and the render
is always on an integer grid. Crisp render, continuous motion.

## One motion, not two

Position and zoom interpolate **together**, every frame, in world space —
`easeInOutCubic`, one easing. An earlier version split them into "travel,
then zoom" to work around a bug, and it felt worse; the bug was the real
problem and splitting them was not the fix.

Two speeds:

| | | |
| --- | --- | --- |
| `CAM_UI` | 480 ms | anything answering a control — zoom buttons, home, whistle, opening a duck card |
| `CAM_MOMENT` | 1100 ms | the one thing watched rather than operated: a duck being released |

## The world wraps

**There are no edges.** Pan far enough in any direction and you come back
round to the same water.

This is not only a nicer feel. Clamping caused most of the camera trouble in
this project — a tween jumping when it hit a boundary, ducks jammed into a
corner by the whistle, "why can't I drag" at zoom levels where the world
happened to equal the frame. A boundary that does not exist cannot be hit
wrong.

Two things follow, and both must hold or the seam shows:

- **Distance** measures the short way round — separation, personal space, the
  whistle, the bump dart. Two ducks either side of the seam are neighbours.
- **Drawing** happens once per tile the viewport touches. The world floor is
  2.4× the frame, so it can straddle at most one seam per axis: four draws
  worst case, one almost always, with off-screen ducks culled in each.

Wrapping is a property of the **space**, not the engine. The pond wraps; the
arrival screen does not — it is a single-duck stage that has edges, and
wrapping sent its camera to the far side of the world.

## The world grows with the population

```
side = max(frame × 2.4, ceil(sqrt(ducks) × 34))
```

More cards means a bigger pond, never a more crowded one. The 2.4× floor
exists so there is somewhere to drag to even when the pond is nearly empty —
without it the world equalled the frame at default zoom and panning did
nothing, which reads as broken rather than as "you have seen it all".

## The canvas is overscanned

Drawn at 150% of its frame and clipped. A camera transform can translate as
well as scale, and a translate slides an edge into view no matter how large
the scale is; the margin means there is always real, rendered water outside
the visible edge to move into.

**Consequence worth remembering:** the camera addresses the *canvas*, but only
the middle two-thirds is ever seen. Centring is unaffected — the overscan is
symmetric — but any *fractional* framing must be measured against the visible
frame. `frameX/frameY/fw/fh/atFrame` exist for exactly this. Measuring "a
third of the way down" against the canvas put a duck 5% down the screen,
behind the notch.

## Two clocks, one render

The world ticks at ~12 fps because stop-motion is the look. The camera is
direct manipulation and must track a finger at display rate. So the camera
redraws on `requestAnimationFrame` while it is moving and not otherwise — an
idle pond still costs one draw per stop-motion frame.

And the world **holds still** for the length of a camera move. Otherwise the
ducks lurch two or three times underneath a smoothly gliding view, which
reads as the zoom stuttering even though the zoom is fine.

## Sprites quantise to canvas pixels

One rule, always. Snapping them to the world grid (`round(x) * CELL`) looks
marginally tidier at rest, because it locks ducks to the water's dither — but
it means a duck can only sit on multiples of `CELL`, so it jumps in
`CELL`-sized steps whenever the view moves. Worse, having *two* rules meant
every camera move ended with every duck snapping up to half a cell as the
rule changed. A rule that changes is worse than either rule.

## The whistle

In the Wii Mii Plaza you blow a whistle and every Mii runs over. The card is
already a thing you blow into, so the pond borrows the gesture. **The duck
count is the whistle** — tap "113 ducks", pick a keeper, and it reads "30 of
113" while active. No extra chrome over the water.

Called ducks each aim at their own spot on a loose ring and arc in, because a
crowd converging on one point packs into a hexagonal lattice and reads as a
crystal rather than a flock. Everyone else is **pushed clear of the frame**,
not dimmed — a faded duck still reads as being in the way — and fans around
the rim rather than jamming into a corner. Clearing the whistle pulls the
shoved ducks back, so the pond refills.

## Ducks keep their distance

Two zones, because not-overlapping and not-clumping are different problems:

- **contact** at `N × 0.86` — a hard push, so two ducks are never in the same
  place
- **elbow room** at `N × 1.75` — much weaker, and it is what actually keeps
  the water evenly occupied

Both run on a uniform grid bucketed to the larger radius, so it stays O(n).
New ducks are placed by best-candidate sampling: even coverage without a
grid's regularity, because plain random clumps.

Headings **wander** rather than holding a fixed drift. A fixed heading is a
straight line and a straight line ends at a wall, which is why ducks used to
collect along the edges before the pond wrapped.

## What is deliberately not built

- **Momentum after a flick.** It needs velocity tracking, friction and its own
  interaction with wrapping, and it is where this kind of code starts to rot.
- **Double-tap to zoom.** It would force every water tap to wait ~300 ms to
  find out whether a second one was coming, and the ripple's snappiness is the
  first thing anyone notices. The zoom buttons cover it, and they also work
  one-handed, which pinch does not.
- **Scenery.** No beach, no reeds, no houses. Later, maybe.

## The one thing this does not fix

Rendering scales; **the payload does not**. Every duck carries a 384-character
paint layer, so a thousand ducks is ~400 KB of JSON before anything is drawn.

The fix is the same idea applied to the API — fetch by region and recency, not
all of them. Not needed at 100 cards, real work at 1,000, so it is written
down rather than built.

---

## Inertia and pinch

**The first camera behaviour with no prototype behind it**, so this section
is the only place the reasoning lives. Added on request: dragging should
follow the force of the finger rather than stopping dead.

### A flick coasts, and slows down

Exponential decay, which is what every platform converged on:

```
v *= exp(-dt / 325ms)
```

UIScrollView expresses the same curve as a per-millisecond
`decelerationRate`; 0.998 is a time constant of ~325 ms, which reads as
normal rather than icy or sticky. The travel is integrated in CLOSED FORM
(`tau * (1 - decay)`) rather than accumulated per frame, so a phone dropping
frames does not also lose distance.

| | |
| --- | --- |
| `FLING_TAU` | 325 ms |
| `FLING_REST` | 0.004 sprite px/ms — below this it has stopped |
| `FLING_MAX` | 4 screen px/ms, so a wild flick cannot teleport across a small world |

**Velocity is measured across a ~120 ms buffer, not from the last event.**
A single delta is mostly sensor noise — and, more importantly, a finger
that slides across and then *pauses* before lifting would otherwise fling
with the velocity of the slide. Over a buffer a deliberate stop yields
almost nothing, so it does not fling, with no special case for it.
Confirmed on the deployed site: a pause-then-lift coasts 0 pixels.

**There is no rubber-banding, and there never will be.** The world wraps,
so there are no edges to bounce off — which deletes the hardest part of
scroll physics. Do not add it back.

**Reduced motion turns inertia off.** UI.md § 5 says reduced motion never
removes *information*; a coast carries none.

### Two fingers pan and zoom at once

The centroid's movement pans, the distance between the fingers zooms, and
the zoom is anchored on the centroid so the water between them stays
between them. Treating those as separate modes makes a pinch feel like
operating two controls badly rather than holding one thing.

**The anchor is in DEVICE pixels.** `CELL` is defined as *device* pixels per
sprite pixel, so passing CSS pixels under-corrects by exactly the
device-pixel ratio. On a 2× screen that is half, and it presents as the
water sliding under the fingers rather than as an obvious bug — measured at
24.75 world pixels of drift for a 200-pixel anchor zooming 4→6, which is
`200 × (2−1) × (1/8)` to the decimal. Now 0.04. There is a test pinned to
that arithmetic.

A pinch is CONTINUOUS while the fingers are down — which is a legal render
state, because the remainder is a CSS scale — and eases onto the nearest
rung when they lift (`SETTLE_TAU` 90 ms). At rest the zoom is always
integral, which is what stops outlines crawling.

### A finger on the glass counts as camera movement

`moving` includes dragging, flinging and settling, not just gliding. It
drives both the display-rate redraw and the world freeze.

Before it did, a drag fell through to the 83 ms stop-motion path and
tracked a thumb at twelve frames a second — the exact thing the two-clocks
rule exists to prevent, and invisible in a screenshot.

### Screen to world uses the continuous cell

Every screen→world conversion — taps, drags, anchors — uses `cam.cell`, not
`renderCell`. They are equal at rest and differ by up to 25% mid-pinch, so
using the render cell would put taps on the wrong duck and make drags
outrun the finger for the length of every zoom.

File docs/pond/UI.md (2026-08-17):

# The pond — UI reference

The rules every screen in `ducky.davidyang.work` follows, and a log of what
changed. If a new screen disagrees with something here, one of the two is
wrong — fix it before shipping, don't add a special case.

Canonical implementation: `pond/src/client/` and `pond/public/app.css`. `pond/tools/prototype-flow.html` is the signed-off reference the rules came from, kept for comparison
and `pond/src/client/` (the real thing). Both must agree.

---

## 1. The standing constraint

**Mobile first, always.** Every decision optimises for a phone held one-handed
by someone who just tapped a card in a bar. Desktop is the courtesy case.

Practical consequences that are not negotiable:

- **44px minimum tap target.** Anything pressable. No exceptions for "small"
  controls — a 20px-tall text button is the single most common bug here and
  it has already been fixed twice.
- **16px minimum font-size on inputs.** iOS Safari zooms the page when you
  focus an input smaller than 16px and never zooms back out.
- **Nothing load-bearing in the bottom 90px.** Safari's URL bar sits there.
  Use `env(safe-area-inset-bottom)`.
- **No hover-only affordances.** There is no hover.

---

## 2. Colour

Pond surface tokens (light UI on water):

| Token | Value | Use |
| --- | --- | --- |
| `--p-ink` | `#0b3d52` | All small text, labels, button text. 11.1:1 on surface. |
| `--p-soft` | `#2d6076` | Body text only. 6.6:1. |
| `--p-faint` | `#5b8699` | Decoration and disabled only. **Never** small text — 3.5:1 fails. |
| `--p-surface` | `#f2fbfe` | Sheets, cards, panels. |
| `--field-500` | `#3fb5d8` | The pond blue. Focus rings, accents. |
| `--field-900` | `#16718f` | Deep water. |
| `--duck` | `#ffca00` | The primary action, and the duck. |
| `--duck-shadow` | `#c08508` | The 3D shadow under `--duck`. |

Sprite colours are fixed and are **not** theme tokens — a duck is the same
duck everywhere:

- beak `#EF9F4E` · eye `#2B2B24` · burning body `#FF8953`
- flame `#FF4B4B` (core) and `#FF8953` (tips)

**Rule:** labels and small text take `--p-ink`. Reaching for `--p-soft` or
`--p-faint` on a label is how the studio nav ended up unreadable.

---

## 3. Corners — one language

Every pressable rectangle is cut with the same **two-step 3px staircase**,
exposed as `--px-corner` and applied with `clip-path`.

```css
clip-path: var(--px-corner);
```

**Why:** a 99px pill next to a 24×24 sprite is the only shape in the product
that could not have been drawn on the grid. Pixel-cutting some elements and
rounding others reads as a mistake, so it is all or nothing.

Applies to: `.btn`, `.p-btn`, `.icon-btn`, `.say-btn`, `.s-nav button`,
`.s-tabs button`, `.swatches button`, `.field input`, `.field textarea`,
`.hud span`, `.p-bumper`, `.priv`, `.s-strip`.

Two consequences of `clip-path` that bite every time:

1. **It clips `box-shadow`.** The 3D buttons draw their face on `::before`
   and their shadow on `::after`, offset 4px, both clipped. Never put a
   `box-shadow` on a clipped element expecting it to show outside.
2. **It clips the focus ring.** Clipped controls use
   `box-shadow: inset 0 0 0 3px var(--field-500)` instead of `outline`.
   An `outline` on a clipped element is invisible.

---

## 4. Type

| Role | Face | Notes |
| --- | --- | --- |
| Display | Young Serif → Georgia | Headings only. |
| Body | InterVar → system-ui | Running text. |
| Utility | IBM Plex Mono | Labels, chrome, data, counters. |
| Japanese display | Dela Gothic One | 大吉 etc. at heading size **only**. |
| Japanese small | Zen Kaku Gothic New | Dela fills in and becomes a blob below ~14px. |

Both Japanese faces are subset to nine glyphs (`大吉小末凶おみくじ`). They
cannot render Chinese — see §8.

**Label style:** mono, uppercase, `letter-spacing:.1em`, `--p-ink`.
Minimum `.64rem`. The screen title in a nav row must outrank its buttons —
title bold at `.8rem`, buttons `.68rem`.

---

## 5. Motion

Everything is stop-motion. Nothing eases smoothly except position lerps.

| Thing | Duration | Curve |
| --- | --- | --- |
| Stop-motion tick | `DWELL = [180, 380, 280, 180]` ms | the card's own uneven walk |
| Ripple | 480 ms | ease-out, discrete rings — **not** a wave sim |
| Bump dart | 420 ms | ease-out cubic, fixed regardless of distance |
| Sheet / panel | 220–280 ms | `steps(4)` / `steps(5)` |
| Sparkle | `on = d·36ms`, hold 170 ms, `off = d·42ms` | `steps(1)` |
| Fire flicker | ~14 Hz | drops **pixels**, never brightness |

**Rules:**

- A wave *simulation* always lingers, because dissipating energy takes time.
  Ripples are discrete events with a hard end. This was reverted once already.
- The fire flicker is inside the 3–60 Hz band WCAG 2.3.1 restricts. It is only
  acceptable because the area is one duck and **the luminance never swings**.
  Never flicker brightness, never flicker the background.
- `prefers-reduced-motion` never removes information. A reduced-motion bump
  still bumps, it just doesn't travel; a reduced-motion fire is steady, not
  absent.

---

## 6. Dither

**Texture for surfaces and edges. Text always on a solid fill.** Measured:
11.1:1 on solid, and dithered text falls below AA immediately.

Water is Bayer-dithered brand blues, never a gradient.

---

## 7. Components

| Component | Rules |
| --- | --- |
| `.btn` | Primary. Full width, `--duck`, 44px min, 4px pixel shadow, `translateY(3px)` on press. `.btn.g` is the quiet variant. |
| `.icon-btn` | 44×44, icon only, sits beside what it acts on — never in a row of equal-weight buttons competing with the primary action. |
| `.s-nav` | Back / **title** / forward. Title is the largest, darkest thing in the row. Buttons are chips, 44px tall. |
| `.hud span` | Floating labels over water. Pixel-cut, solid white fill, `--p-ink`. |
| `.p-bumper` | 40×40 tile, duck sprite at 32px, count in the corner. Ranked, max 5. |
| Glyphs | `iconCanvas(name, sizeInCssPx)`. The size argument is the **displayed** size, never a pixel scale, so changing a glyph's grid cannot change how big it lands. Canvas is `margin:0 auto` — `text-align:center` does not centre a block. |

---

## 8. Language

- Default comes from the **card keeper's** setting; the **visitor's browser
  wins** if it asks for a language we have. A keeper sets a default, not a lock.
- `lang` must be set correctly on the document. Several characters are drawn
  differently in Japanese and Traditional Chinese; with a Japanese face in the
  stack and no `lang`, a Chinese reader gets Japanese letterforms.
- CJK uses **system faces** (PingFang TC, Noto Sans CJK TC, Microsoft JhengHei).
  A full Traditional Chinese webfont is megabytes and this is a phone that just
  tapped a card.
- The label style does not survive translation: Chinese has no uppercase, and
  `letter-spacing` on CJK pulls characters apart. Chinese labels get the same
  size and colour with **no tracking and no transform**.
- 大吉 · 小吉 · 末吉 · 凶 read correctly in Traditional Chinese unchanged. In
  English they sit next to a gloss; in Chinese the gloss is redundant and drops.
- User-written content is **never** translated.

---

## 9. Privacy surfaces

- A duck's card never shows the card serial. It shows `via <keeper>`, or
  nothing. Publishing the serial hands out half of what a card claim is keyed on.
- Contact scope is stated in **names**, on every row, everywhere it appears —
  "shared with Sam and you", not "scope: 2".
- "Take my duck out" deletes the duck and its contact in one transaction.
  Nothing is retained, and no other person's duck is ever cascaded away.

---

## 10. Changelog

| Date | Change | Why |
| --- | --- | --- |
| 2026-08-12 | Canvas fits its frame | Backing was 688x1480 (0.465) in a 326x740 box (0.441), so it rendered 39px short — that white band was always there. Fitted on view entry, since a hidden view measures 0. |
| 2026-08-12 | Water canvas is overscanned | Drawn 136% of the frame and clipped, so a camera transform always has real rendered water to move into. |
| 2026-08-12 | Travel and zoom are separate motions | A CSS transform can only borrow rendered water, so a journey across the pond slid an edge into view. Long moves glide (re-rendered, safe at any distance); the zoom then happens about the centre where its translate is ~0. |
| 2026-08-12 | Pans ease in and out | `cam += (target-cam)*k` only eases out — it starts at full speed. Now a timed easeInOutCubic. |
| 2026-08-12 | Tapping a duck travels to it | Both the canvas tap and the screen-reader list, so the two routes agree. |
| 2026-08-12 | Smooth zoom without fractional cells | Render stays on the OLD integer framing and the canvas scales UP to the new one, committing at the end. Scaling *down* to fake the old framing exposed the surface behind the pond. |
| 2026-08-12 | Zoom home button | Returns to CELL 4 anchored on what you are looking at — home is the zoom, not the place. Hidden when already there. |
| 2026-08-12 | Zoom level 8 added | For the arrival and release moments, where the duck should be close enough to look at rather than locate. |
| 2026-08-12 | Ducks keep personal space | Two zones: contact (never overlap) and elbow room at ~2x, which is what stops loose huddles forming. Measured: min gap 36→53px, edge-hugging 21→6. |
| 2026-08-12 | Wander, not fixed drift | A constant heading is a straight line and a straight line ends at a wall, which is why ducks accumulated on edges. Headings meander; walls repel before contact. |
| 2026-08-12 | Gather point is the world centre | It was the viewport centre, so it moved when you panned and shoved ducks into whatever corner you faced. |
| 2026-08-12 | Arrival zooms to your duck | In a pond bigger than the screen, landing at arm's length is the difference between "there it is" and "somewhere out there". |
| 2026-08-12 | BY-002 is a link | The only outbound link in the pond, hardcoded and mine — so it carries none of the risk that removed the keeper's custom link. New tab. |
| 2026-08-12 | The count is the whistle | Tapping "113 ducks" opens the gather list; it reads "30 of 113" while filtered. Gathering costs no chrome over the water. |
| 2026-08-12 | "Find my duck" removed | It asked the same question as the whistle's "your circle". Once your duck is in the pond there is no action you still owe it, so the CTA hides entirely. |
| 2026-08-12 | Pond camera | Zoom is `CELL` restricted to {2,3,4,6}; world grows as `sqrt(ducks)`; camera is a translate. Verified: 13 ducks = world 172×370 (the screen), 113 = 362×779. |
| 2026-08-12 | Camera renders off-tick | The world ticks at ~12fps for stop-motion, but a drag must track a finger at display rate, so the camera redraws on rAF while it is moving. Two clocks, one render. |
| 2026-08-12 | Ducks never overlap | Separation on a uniform grid, O(n). Placement uses best-candidate sampling so the scatter is even without being a grid. |
| 2026-08-12 | Keeper's custom link removed | A keeper who wants their card to point elsewhere can rewrite the tag. Deletes an open-redirect risk, an interstitial and a moderation surface. |
| 2026-08-12 | Codex copy review applied | ~30% shorter across every screen; glossary reworked (keeper → card keeper, dropped the "only key that exists" metaphor, banned first person). |
| 2026-08-12 | Copy extractor rewritten | It read only `.view`, so it missed the duck card, the sheets, every aria-label and every string the JS writes. 141 strings now, not 96. |
| 2026-08-12 | Copy deck added ([COPY.md](COPY.md)) | Every string in one reviewable place. Its first run caught "waved" surviving the bump rename, and the keep sheet handing out /d/<slug> as the private link. |
| 2026-08-12 | Card setup trimmed 169 → 124 words | It was nearly double the next longest screen. |
| 2026-08-12 | Keeper links their own duck | Claiming a card and having a duck are different things; either can come first, so neither is a precondition. Optional, and the link is how two cards say they belong to one person. |
| 2026-08-12 | 44px audit across all nine screens | Writing this file down found six violations, three pre-existing: text inputs and studio tabs at 40px, the duck card's close at 28px, Bump/Report at 34px. |
| 2026-08-12 | Card setup + Admin screens added | The keeper flow and moderation now exist as screens, not just a proposal. |
| 2026-08-12 | Bump replaces wave | A wave was a number; a bump is an event you watch. Reuses the splash impulse. |
| 2026-08-12 | Bump capped at 10 unreturned | The poke dynamic — it forces reciprocity instead of one-way spam. |
| 2026-08-12 | One corner language | Pixel-cut two chips and rounding the rest read as a mistake. |
| 2026-08-12 | `iconCanvas` takes a display size | Growing the art from 9 to 27 grew the glyph past its button and clipped it. |
| 2026-08-12 | Glyphs centred with `margin:0 auto` | `display:block` in a `text-align:center` button pinned every glyph left. |
| 2026-08-12 | Gear + chat use the reference art | The redraws read as a mandala and a sun. |
| 2026-08-12 | Studio nav rebuilt | 10px labels, 20px hit area, no surface — unreadable and unhittable. |
| 2026-08-12 | Flames actually render | The `burning` flag existed with no renderer; ducks caught fire invisibly. |
| 2026-08-12 | Duck card drops the card serial | It published half of a card-claim credential. |
| 2026-08-12 | Slug ≠ name ≠ edit key | A readable URL must not be the edit credential. |
| 2026-08-12 | Fortune gloss drops in Chinese | The kanji already say it. |

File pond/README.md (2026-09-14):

# The Pond

`ducky.davidyang.work` — the web half of the BY-002 Insert Coin card.

Tap the card after a coin insert and you land here holding the duck the
machine dealt you. Decorate it, sign it, leave it in the water with everyone
else's. Ducks live forever.

**Mobile-first is not a preference.** Every visitor arrives by tapping a card
with a phone. Desktop is a courtesy.

---

## Layout

```
pond/
  schema/0001_init.sql     THE FROZEN CONTRACT. Read the comments first.
  api/                     Vercel entry points. Three lines each, on purpose.
    router.ts              everything under /api, via a rewrite
    sweep.ts               the daily cron, behind CRON_SECRET
    shell.ts               /            duck-page.ts  /d/<slug>
    duck-edit.ts           /e/<key>
  src/db/                  the D1-shaped adapter. The whole port lives here.
  src/worker/              the API, knowing nothing about Vercel
    index.ts               handle(req, env) — routes and security headers
    session.ts             tap → ticket. The single most important file.
    ducks.ts               public reads. Must never name `contacts`.
    release.ts             the one write that may. Duck + contact, one batch.
    social.ts              bumps, fires, speech, reports. Atomic SQL only.
    limits.ts              rate limits, because SECURITY.md promised them
    shell.ts / pages.ts    the server-rendered HTML
    flash-shell.ts         /flash, the one page that needs no database
    util.ts                text cleaning, ids, constant-time compare
  src/client/              the pond itself (canvas)
  src/flasher/             /flash — flashes a card over Web Serial. docs/flasher/
  test/                    contact isolation is enforced here, not promised
  tools/                   db-apply, db-verify, sprites, the prototypes
  public/                  served verbatim by the CDN. NOT generated, not ignored.
```

## Running it

```bash
npm install
export TURSO_URL=file:local.db    # a real Turso URL works the same way
export SESSION_SECRET=dev-secret
export ADMIN_PASSWORD=dev-admin
npm run db:apply                  # apply the schema
npm run dev                       # vercel dev
```

Then open `http://localhost:3000/?d=1&c=TESTCARD`.

`npm run db:verify` proves, against whatever `TURSO_URL` points at, that
deleting a duck really does take its contact with it. Run it once after the
first deploy: it is the one thing about a hosted database that cannot be
checked from here.

## Tests

```bash
npm test
```

`test/contacts-isolation.test.ts` is the one that matters. It fails the build
if the public read path ever learns the `contacts` table exists. If it starts
failing, the fix is almost never to loosen the test.

## The three decisions worth knowing

**Freshness is checked once.** The card's `?d=` digit is only live for 300
seconds, but decorating takes minutes. `session.ts` exchanges the digit for a
30-minute session on the *first* request and never looks at it again. Check
late and every duck dies on the submit button.

**`?d=` is forgeable.** Anyone can type `/?d=1`. It proves a fortune was
requested, not that a coin was inserted. What actually holds the line is in
`docs/pond/SECURITY.md`, which is written to be honest rather than
reassuring.

**The deletion promise is a trigger, not a cascade.** The contact screen
promises, in writing, that taking your duck out deletes the contact.
`ON DELETE CASCADE` would do that — if foreign keys were being enforced, and
the pragma is per-connection and off by default. So `ducks_before_delete` in
the schema does the deleting instead, and the tests run every deletion twice:
once with foreign keys on, once with them off.

## Related

- `docs/pond/README.md` — **start here.** What the words mean, and which
  document answers which question.
- `docs/pond/CARD-STATES.md` — how a card decides who owns it
- `docs/pond/PROVISIONING.md` — making the cards
- `docs/pond/HOSTING.md` — Vercel, Turso, and the CNAME at Cargo
- `docs/pond/SECURITY.md` — threat model
- `variants/business-card-v1/firmware/production-pond/` — the firmware that
  points a card here

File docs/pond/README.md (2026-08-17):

# The pond

The web half of BY-002 "Insert Coin", a business card with an NFC chip in it.

Tap the card with a phone. It deals you a fortune, you decorate the duck you
were dealt, sign it, and leave it floating in a pond with everyone else's.

**Live at [ducky.davidyang.work](https://ducky.davidyang.work).**

---

## The words

These come up everywhere. Worth reading once.

| Word | What it means |
|---|---|
| **card** | The physical business card. It has a tiny computer, a coin battery, LEDs, a microphone and an NFC tag. |
| **serial** | Eight characters that identify one card, like `5BKZH69H`. The chip derives it from its own factory ID, so no two cards share one and it can never be changed. |
| **tag** | The NFC part. It holds a web address that the phone opens. The card rewrites parts of that address as things happen. |
| **fortune** | One of four luck levels: 大吉 great, 小吉 little, 末吉 uncertain, 凶 bad. A 凶 duck arrives on fire and anyone can put it out. |
| **duck** | What a visitor makes and leaves behind. |
| **keeper** | Whoever owns a card. Their name shows on every duck from it, as "via Sam". |
| **claim** | Becoming a card's keeper. You blow on the card four times while it is booting. |
| **claim counter** | A number the card stores and raises each time you blow four times. The server accepts a claim only if the number is *higher* than the last one it saw, so an old address cannot be reused. |
| **epoch** | One keeper's turn with a card. Cards can change hands; each turn is separate, so contacts given to one keeper are never inherited by the next. |
| **private link** | The secret address for one duck, like `/e/abc123…`. Whoever has it can rename, redraw or remove that duck. There are no accounts, so this link is the only key. |

---

## Which document answers what

**Start here if you want to know…**

| …what a visitor actually sees | [SCREENS.md](SCREENS.md) — every screen from the tap onward, and the edge cases each has to survive. |
|---|---|
| **…how a card decides who owns it** | [CARD-STATES.md](CARD-STATES.md) — the card and keeper state machine, written because it was wrong five times in one week. |
| **…how to make the cards** | [PROVISIONING.md](PROVISIONING.md) — flash, battery, tap. Every card is identical; it gives itself an identity. |
| **…where it runs** | [HOSTING.md](HOSTING.md) — Vercel, the DNS at Cargo, and the secrets. |
| **…what is and is not safe** | [SECURITY.md](SECURITY.md) — honest rather than reassuring, including what is deliberately undefended. |

**Design records — why something works the way it does:**

| [UI.md](UI.md) | The rules every screen follows: spacing, colour, motion, corners. If a screen disagrees with this, one of the two is wrong. |
|---|---|
| [COPY.md](COPY.md) | Every word the product says. Generated — run `python3 pond/tools/extract-copy.py`, never edit by hand. |
| [KEEPER.md](KEEPER.md) | Claiming a card, handing it on, and the private link as a credential. |
| [ADMIN.md](ADMIN.md) | The `/pondkeeper` screen David runs the pond from. |
| [POND-CAMERA.md](POND-CAMERA.md) | How the pond grows past the edge of the screen: zoom, pan, the whistle. |
| [MOBILE.md](MOBILE.md) | iOS Safari and Android Chrome specifics, including in-app browsers. |
| [SOUND.md](SOUND.md) | A proposal. **Not built.** |

[history/](history/) holds the original build plans and the progress tracker.
They record how the pond got made, not how it works, and are kept because the
reasoning in them is sometimes still the answer to "why is it like this".

---

## Running it

```bash
cd pond
npm install
npm run verify      # types, then the bundle, then the whole test suite
```

There is no dev server. Two ways to see the interface:

- **The pond itself** — `https://ducky.davidyang.work/?d=1` deals a fortune
  without a card. `d=1` to `d=4` picks which one.
- **The admin bench** — serve the folder and open the harness. It fills the
  screen with generated cards and ducks, so layouts can be judged at real
  batch size without a password or a database:
  ```bash
  cd pond && python3 -m http.server 8899
  # http://localhost:8899/tools/admin-harness.html
  ```

Deploy with `npm run ship` (verify, then Vercel).

---

## Where the code is

```
pond/
  schema/       The database, as SQL. The comments are the design reasoning,
                not decoration — read them before changing a table.
  src/worker/   The server. Every page is a function; there is deliberately
                no public/index.html (HOSTING.md explains why).
  src/client/   The pond, the studio, the admin. Canvas sprites and rendering.
  public/       Served straight to the world by the CDN. Anything dropped in
                here is published, so bench pages live in tools/ instead.
  test/         The suite. The contact-isolation ones are load-bearing.
  tools/        The prototype, the admin bench, the copy extractor and the
                sprite generators.
```

The firmware is a separate PlatformIO environment at
`variants/business-card-v1/firmware/production-pond/`. The older `production`
and `production-nfc` environments are never touched.

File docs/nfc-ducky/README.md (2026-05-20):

# NFC ducky -- post-reveal URL personalization

The `production-nfc` firmware variant writes the fortune result to the
ST25DV04K NFC tag over I2C so that a phone scan after the show lands
on a fortune-coded URL. `davidyang.work` runs a small inline script
(`cargo-snippet.html`) that reads `?d=N` and prepends the matching
duck illustration to the `DAVID YANG` header.

After 60 seconds the MCU wakes once more, resets the URL digit to `0`
(no ducky), and goes back to terminal deep sleep.

## Architecture at a glance

```
+-----------------------------+        I2C            +-----------------------+
|  ATtiny1616 (post-reveal)   |  -- 4 byte write -->  |  ST25DV04K NDEF EEPROM |
|  ndef_patch_fortune(N)      |                       |  ?d=N is now live      |
+-----------------------------+                       +-----------+-----------+
                                                                  |
                                                            NFC (RF-powered)
                                                                  |
                                                                  v
                                                       +-----------------------+
                                                       |  Visitor's phone      |
                                                       |  opens davidyang.work |
                                                       |  /?d=N                |
                                                       +-----------+-----------+
                                                                  |
                                                                  v
                                                       +-----------------------+
                                                       |  Cargo.site custom JS |
                                                       |  prepends ducky[N] to |
                                                       |  the DAVID YANG row   |
                                                       +-----------------------+
```

## One-time setup

These steps only need to be done once per physical card and once per
Cargo.site instance.

### 1. Pre-program the tag from a phone

The MCU only patches a single byte; the full NDEF framing must be in
place first. Easiest path:

1. Install **NFC TagWriter by NXP** (Android) or **NFC Tools** (iOS/Android).
2. Choose "Write URL".
3. Enter `https://davidyang.work/?d=0` exactly (with the trailing `0`).
4. Hold the phone to the unpowered card, around the etched antenna on
   the back.
5. Confirm with the app's "Read tag" function that you see the same
   URL back.

The placeholder `0` is what the firmware will overwrite at runtime. If
you write a *different* URL (say, with `?d=1` or no query string at all)
the byte offset assumption in `config.h` (`NDEF_DIGIT_OFFSET = 0x001D`)
will be wrong and you'll either patch the wrong byte or corrupt the
NDEF framing. Stick to `https://davidyang.work/?d=0`.

### 2. Upload the four ducks to Cargo Media Manager

The SVGs live next to this README in `assets/`:

| File | Maps to | Fortune |
| --- | --- | --- |
| `ducky-great.svg` | `d=1` | great luck (banks 4) |
| `ducky-little.svg` | `d=2` | little luck (bank 5) |
| `ducky-uncertain.svg` | `d=3` | uncertain (bank 6) |
| `ducky-bad.svg` | `d=4` | bad luck / fire (7+8) |

Upload all four to Cargo's Media Manager. For each, copy the public
URL Cargo gives you (something like
`https://freight.cargo.site/.../ducky-great.svg`).

### 3. Paste the snippet into Cargo Site Options

1. Open `cargo-snippet.html` from this directory.
2. Replace the four `ASSET_URL_*` placeholders with the Cargo URLs
   from step 2.
3. In Cargo: **Site Options -> Custom Code -> Body End** (the section
   that injects at the close of `</body>`).
4. Save and reload `davidyang.work`. Visiting plain `davidyang.work`
   should show no ducky; `davidyang.work/?d=1` should show the
   great-luck duck floating before `DAVID YANG`.

### 4. Verify the byte offset (one-time)

After step 1, before flashing `production-nfc`, manually test the
patch offset:

1. Pre-program tag with `https://davidyang.work/?d=0` (step 1).
2. With the card unpowered, scan with the phone. URL ends `...?d=0`.
3. Flash a tiny ad-hoc sketch that calls `ndef_init();
   ndef_patch_fortune(0);` (writes `'1'`) once, then halts.
4. Re-scan. URL should now end `...?d=1`.

If the URL is unchanged or corrupted, the offset is wrong. Sniff the
first 32 bytes of user memory with a Wire-based read loop, identify
where the digit landed, and update `NDEF_DIGIT_OFFSET` in
`production-nfc/src/config.h`.

## Flash and run

```bash
cd variants/business-card-v1/firmware
pio run -e production-nfc -t upload
```

The two variants compile as separate environments:

- `pio run -e production` -- original behavior, no NFC writes
- `pio run -e production-nfc` -- the new behavior described here

## Fortune to duck mapping

| `fortune` index | ASCII byte written | URL on phone | Ducky shown |
| --- | --- | --- | --- |
| `FORTUNE_GREAT` (0) | `'1'` (0x31)  | `.../?d=1` | great-luck duck (gold)  |
| `FORTUNE_LITTLE` (1) | `'2'` (0x32)  | `.../?d=2` | little-luck duck (gold) |
| `FORTUNE_UNCERTAIN` (2) | `'3'` (0x33)  | `.../?d=3` | uncertain duck (small)  |
| `FORTUNE_BAD` (3) | `'4'` (0x34)  | `.../?d=4` | bad-luck duck (flame) |
| (expired, 60 s post-reveal) | `'0'` (0x30) | `.../?d=0` | no ducky |

## Edge cases worth knowing

| Scenario | Behavior |
| --- | --- |
| Visitor scans card *before* coin insert | Sees `?d=0` -> default page, no ducky |
| Visitor scans within 60 s of reveal | Sees current fortune's ducky |
| Visitor scans 60+ s after reveal | Sees `?d=0` -> default page (URL was reset) |
| MCU's I2C write fails (NACK, RF busy) | Previous byte stays -> shows previous fortune or default |
| Battery dies mid-show before reset | URL stays at the just-set fortune (next visitor sees that ducky) |
| User manually visits `davidyang.work/?d=99` | Falls through `DUCKIES[d]` lookup -> no ducky |
| Visitor scans with battery dead | Tag is RF-powered; whatever URL was last written serves |
| Re-insert coin during 60 s window | Cold reset -> new fortune overrides the digit; 60 s timer restarts |

## Hardware note: no external I2C pull-ups

The card has no 4.7 kOhm pull-ups on SDA/SCL. `ndef_init()` enables
the ATtiny1616's internal pull-ups (`PORT_PULLUPEN_bm`) on PB0/PB1 and
clocks SCL at 25 kHz to keep the rise-time margin generous on the
~25 pF bus. This is intentionally out of formal I2C spec but works
reliably for 1-2 cm of trace. If you ever see persistent NACKs, the
escape hatch is a dead-bug 4.7 kOhm from each line to VCC.

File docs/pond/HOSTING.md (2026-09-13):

# The pond — hosting

`ducky.davidyang.work` runs on Vercel. `davidyang.work` stays exactly where it
is, on Cargo — nothing about the apex changes, and no nameservers move.

That last point is why this is Vercel and not Cloudflare Workers: a Workers
custom domain needs the whole zone on Cloudflare, which would have meant
moving the apex off Cargo. Vercel takes a plain CNAME from a DNS host it does
not control, so the subdomain is the only thing that moves.

---

## 1. DNS at Cargo

One record. The same shape as `invoice.davidyang.work`.

| Type | Host | Value |
| --- | --- | --- |
| CNAME | `ducky` | `cname.vercel-dns.com` |

Add the domain in Vercel first (Project → Settings → Domains →
`ducky.davidyang.work`), then add the record at Cargo. Vercel issues the
certificate automatically once it resolves; propagation is usually minutes.

**Do not** add an A record, and do not touch the apex or `www`.

---

## 2. Plan: Hobby, and why it is legitimate

The card is David's personal project, not something sold, so Vercel's
[fair-use rule](https://vercel.com/docs/limits/fair-use-guidelines#commercial-usage)
restricting Hobby to non-commercial use is satisfied. **If BY-002 ever
becomes a product people buy, this needs to move to Pro ($20/mo)** — the
companion site for a sold product is commercial use.

Included on Hobby, against what this actually needs:

| | Hobby gives | The pond needs |
| --- | --- | --- |
| Edge requests | 1,000,000 / mo | hundreds |
| Function invocations | 1,000,000 / mo | hundreds |
| Domains per project | 50 | 1 |
| Function duration | 300 s | milliseconds |

### The one real constraint: crons

Hobby cron jobs **run once per day**, and a more frequent expression
**fails at deploy time** — it is not a silent degradation. So the pond has no
minute-scale scheduled work:

- **Fire ignition happens on read.** `GET /api/pond` runs the ignition as one
  atomic `INSERT … SELECT` in the same request. Nobody sees a fire that starts
  while nobody is looking, so a timer was never doing real work.
- **Fires go out by arithmetic.** `burning` is `now - lit_at < 90s`, computed,
  not stored — so nothing has to run to extinguish one.
- **The daily cron** (`0 4 * * *`) only sweeps expired sessions, nonces and
  spent rate-limit windows, which genuinely does not care about latency. It
  sits behind a `CRON_SECRET` bearer check: without one it is a public
  endpoint that deletes rows, and its path is in `vercel.json` for anyone to
  read.

---

## 3. Database

Vercel Hobby includes Blob storage only, so the database is external.

**Turso** (libSQL), because it is SQLite: the schema in `pond/schema/` and
every query in `pond/src/worker/` port across unchanged, including the atomic
`INSERT … SELECT` patterns that depend on SQLite's single writer. A Postgres
host would mean rewriting those, and they are the load-bearing part of the
concurrency design.

Confirm Turso's current free-tier limits when wiring it up rather than
trusting a number written here.

**Apply the schema with `npm run db:apply`, not a shell pipeline.** The
schema contains a trigger, and a trigger body is `BEGIN … ; … ; END` — a
`split on semicolon` cuts the deletion promise into fragments that fail to
parse, and the failure mode is a database that looks fine until someone asks
to be removed. `src/db/schema.ts` splits it properly and has a test.

**Then run `npm run db:verify` once.** It writes a duck with a contact and a
live session, deletes the duck, and checks the contact is gone — against the
real database, which is the only place that question can be answered. Phase
1a ended with exactly this unresolved; the script is how it gets resolved.

---

## 4. Secrets

Set in Vercel → Settings → Environment Variables, Production scope:

| Name | What it is |
| --- | --- |
| `SESSION_SECRET` | HMAC key for short-lived session cookies and card claims. 32 random bytes. |
| `ADMIN_PASSWORD` | The actual auth on `/pondkeeper`. The path is obscurity, this is the lock. |
| `TURSO_URL` | libSQL connection URL. |
| `TURSO_TOKEN` | libSQL auth token. |
| `CRON_SECRET` | Vercel sends this as a bearer token on cron invocations; reject anything else. |

None of these belong in the repo, and none are needed to run the prototype.

---

## 5. What the firmware writes

The NDEF record is unchanged by any of this:

```
https://ducky.davidyang.work/?d=0&c=XXXXXX
                              ^
                              0x0023, the one patched byte
```

`&c=` is appended after the digit precisely so the patch offset never moves.
See `docs/pond/PROVISIONING.md`.

---

## 6. Deploy

```bash
cd pond
npx vercel link          # once — this creates the project on the account
npx vercel --prod
```

Cron jobs only become active on a production deployment.

**There is no build step and no `public/index.html`.** `public/` is served
verbatim by the CDN, and the HTML for `/`, `/d/<slug>` and `/e/<key>` is
rendered by functions. That is not a stylistic choice: the CDN answers a
static file before any function runs, so an index.html would mean `/` could
never exchange a tap for a session — and that exchange gets exactly one
chance. `public/` is therefore committed, not generated, and not gitignored.

### app.js and app.css are `no-cache`, and that is deliberate

They are the application. They change on every deploy and their names never
do, so a long `max-age` means a deploy is invisible for that long — to a
returning visitor, and to whoever is trying to check the deploy worked.

This was found the hard way: `max-age=3600` was set on `.js`, a fix was
deployed and verified with `curl`, and the browser kept running the old
bundle for another fifty minutes. Two subsequent "fixes" were written for
symptoms that had already been fixed.

`no-cache` does not mean "do not cache" — it means revalidate first. An
unchanged file costs a 304, not a download.

**Note for the next time this bites:** a response already stored under the
OLD policy stays fresh until it expires, whatever the new header says. To
check a deploy immediately, use a private window or a fresh browser profile.

### Checking it worked

```bash
curl https://ducky.davidyang.work/api/pond     # → {"ducks":[],"now":…}
npm run db:verify                              # → the promise holds
```

Then open **`/?d=1`** in a browser. It must say *"you have a fortune
waiting"*. That sentence is the only proof that the rewrite `/` →
`/api/shell` preserved the query string and let the `Set-Cookie` through —
which no test can check from outside a deployment, and which is the one
failure that would kill every duck at the submit button.

A plain `/` showing a duck count proves the rest: the database is reachable
and the API is answering.

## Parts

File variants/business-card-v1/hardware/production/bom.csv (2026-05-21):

Designator | Footprint | Quantity | Value | LCSC Part #
BT1 | BAT-SMD_MY-2032-08 | 1 | Battery-Holder_Coin-Cell_CR2032_Linx_BAT-HLD-001 | C964832
C1, C2 | C_0805 | 2 | 100nF | C28233
LED1, LED10, LED11, LED12, LED13, LED14, LED15, LED16, LED17, LED18, LED19, LED2, LED20, LED3, LED4, LED5, LED6, LED7, LED8, LED9 | LED-SMD_L1.7-W1.1-RD_RED-SIDE | 20 | XL-1606UYC | C965862
LED21, LED22 | LED-SMD_L1.7-W1.1-RD_RED-SIDE | 2 | XL-1606UOC | C965861
LED23, LED24 | LED-SMD_L1.7-W1.1-RD_RED-SIDE | 2 | XL-1606SURC | C965860
Q1, Q10, Q2, Q3, Q4, Q5, Q7, Q8, Q9 | SOT23-3 | 9 | CJ3400 | C19019
U1 | VQFN-20-1EP_3x3mm_P0.4mm_EP1.7x1.7mm | 1 | ATtiny1616-M | C507118
U2 | DFN-8-1EP_3x2mm_P0.5mm_EP1.36x1.46mm | 1 | ST25DV04K-IER8C3 | C5221756
U3 | MIC-SMD_4P-L2.8-W1.9_LMA2718B381-OA7 | 1 | LMA2718B381-OA7 | C5373222

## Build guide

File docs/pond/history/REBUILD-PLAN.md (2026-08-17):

# Rebuild — bringing the pond back to the prototype

Agreed 2026-08-13. Reference: `pond/tools/prototype-flow.html` (rev F), which
is byte-identical to the signed-off artifact apart from 15 trailing bytes.

## Context

The live client drifted from the prototype in four ways, one of them a real
bug that only appears on a phone. Reviewing both side by side at 390×844:

1. **The pond is visually broken on iOS Safari.** Ducks and water dither are
   stretched vertically into smears.
2. The camera sits far too close, and the water's 8-shade depth ramp is
   spread across a world so large it reads as horizontal banding.
3. The pond's chrome lost the pixel-staircase treatment, and three elements
   are missing outright.
4. Six screens that are full views in the prototype became sheets over the
   pond.

Decisions taken: full screens per the prototype; keep inertia but rebuild it
mobile-first with tunable constants; land everything in one pass and ship
once.

---

## A. The stretch — why it only happens on a phone

`PondView.resize()` (`src/client/pond-view.ts:371`) sizes the backing store
from `getBoundingClientRect() × dpr`. That is correct when it runs. It is
wired to exactly one trigger, `src/client/main.ts:151`:

```ts
window.addEventListener("resize", fit);
```

`.p-canvas` is `height: 150%` of a viewport-sized stage (`app.css:106`). When
Safari's URL bar collapses or expands the stage changes height — but Safari
does not reliably fire `resize` for it, it moves `visualViewport`. The CSS box
grows, the bitmap does not, and the browser stretches it. X is unaffected, Y
smears. Desktop Chrome at a fixed viewport never reproduces it, which is
exactly why the test pass missed it and a real phone found it in one tap.

**Fix.** Observe the element, not the window:

- `ResizeObserver` on the canvas — fires on any box change whatever caused it.
- `visualViewport` `resize`/`scroll` as a second signal for iOS toolbar moves.
- Re-fit when `devicePixelRatio` changes (moving between displays).
- Keep the existing early-return so a no-op change stays free.

**Guard.** A test asserting the backing-store aspect ratio equals the CSS box
aspect ratio after a simulated height change. That is the invariant that broke,
so that is the thing to assert — not the listener list.

## B. Camera, zoom, and the infinite canvas

Rebuilt around one tunable block at the top of `camera.ts`, so feel can be
changed without reading the logic:

- Velocity from a short trailing sample window, not the last two events.
- Rubber-band resistance at the world edge, with a spring release.
- Pinch anchored in **device** pixels (the earlier 24.75px drift was CSS
  pixels handed to a device-pixel API).
- Double-tap to zoom about the tap point.
- Integer zoom ladder `{2,3,4,6,8}` kept — it is what keeps pixels square.

The world and the default zoom get fixed together: the water ramp must read
across roughly one screen, not one world, or the bands show. Prototype
values to match: `CELL`, `OVERSCAN = 1.5`, `ZOOMS = [2,3,4,6,8]`,
`CAM_UI = 480`, `CAM_MOMENT = 1100`, `DUCK_ABOVE_SHEET = 0.32`.

## C. The pond's chrome

`--px-corner` is defined (`app.css:51`) and applied to sheets, buttons, inputs
and cards — but not to `.p-count` or `.p-zoom button`, which is why they are
plain rectangles. Apply it, add the missing pieces, and fix the voice:

| | prototype | live now |
| --- | --- | --- |
| count chip | `13 DUCKS`, uppercase mono, letterspaced, pixel corner | `6 ducks`, lowercase, square |
| zoom | 44×44, pixel corner, `#ffffffee` | square, flat |
| top-right | `BY-002` chip | missing |
| bottom | full-width CTA | missing |
| footer | `ducky.davidyang.work` | missing |

## D. Screens

The prototype switches nine `.view` elements through one `go(name)`. Rebuild
as real views with a header bar and a water strip above, replacing the sheet:
**studio, sign, contact, mine, manage, keeper**. The duck card and the report
box stay as overlays — they are glances, not tasks.

`app.css:715` documents the sheet model as deliberate. It was, and it drifted
from the prototype; this reverses it on purpose rather than by accident.

## Verification

Chrome at 390×844 dpr 3, `isMobile` — and specifically **with the viewport
height changed mid-session**, which is the case that reproduces A. Each screen
compared against the same screen in the prototype at 326×740. Then `npm run
verify` (currently 224 tests) and a real-device pass before the single deploy.

## Order

A → C → B → D, then ship once. A is small and unblocks honest visual
comparison; C makes the diff legible; B and D are the large pieces.

---

## E. Messages, duck variants, animation — added 2026-08-13

Second reference: artifact `fafccdf9` — **The Pond — rev E**, an earlier and
smaller revision than rev F. Where they disagree, rev F wins on layout; rev E
is the reference for the three systems below.

### Messages ("say")

The server side already matches rev E exactly and needs nothing:
`SAY_VISIBLE_SEC = 45` (`src/worker/ducks.ts:174`) and
`SAY_COOLDOWN_SEC = 10 * 60` (`src/worker/social.ts:17`). Older says are not
sent to the client at all.

Missing is the client: the compose row (`say-open` / `say-in` in rev E) and
the speech bubble drawn over a duck for its 45 seconds. Bubbles are part of
the canvas, not DOM — they have to pan and zoom with the duck they belong to.

### Duck variants

Four fortunes — 大吉 / 小吉 / 末吉 / 凶 — each with its own sprite, times the
tint palette, times stickers, times the paint layer. `FORTUNES` and the
sprite rows already exist in `src/client/sprites.ts`; what needs checking is
that every variant is reachable and that the burning state still composites
over each of the four rather than only over `little`.

### Animation — the gap the CSS shows plainly

rev E animates DOM with **stepped** easing, never smooth:

```
transition: transform .22s steps(4, end);
transition: opacity  .18s steps(3, end);
.btn:active { transform: translateY(3px) }   /* face onto its shadow */
```

`public/app.css` currently contains **no `transition` declarations at all**
and one use of `steps()`. So every DOM movement in the live client is either
instant or browser-default smooth — both wrong. Stop-motion is not only the
canvas's discipline; rev E applies it to sheets, scrims and buttons too, and
that is a large part of why the prototype feels made and the live client
feels generic.

Canvas timings already correct and to be left alone: `HOLD = 170`,
`RIPPLE = 480`, `CELL = 4`, `PETAL_LIFE = 3 min`, 12fps with the `DWELL`
table.

**Work:** a stepped-transition scale in the stylesheet, applied to sheet
entry, scrim fade, button press, chip changes and tab switches — with
`prefers-reduced-motion` honoured, as rev E does via its `reduce` flag.

### Sticker slots must fit all four ducks

Both artifacts place stickers at fixed sprite coordinates:

```
SLOTS = { hat:[15,2], face:[15,5], neck:[13,10], body:[10,15], float:[5,7], held:[7,…] }
```

One table, four different duck outlines. A hat anchored for 小吉 sits in the
air on 凶 if their heads are at different heights, and "Surprise me" places
into the same slots, so it produces a wrong-looking duck rather than a
random one. The four sprites have to be checked slot by slot — and where a
slot genuinely differs, the offset belongs **per fortune** rather than one
table stretched over all of them.

This applies equally to the random decoration path and to hand placement.

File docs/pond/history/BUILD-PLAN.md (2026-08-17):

# Build plan

Every decision, and the order to build in. This is the document to work from;
where it disagrees with an older doc, this wins.

Status: **Phases 1a and 1b done and DEPLOYED** — <https://ducky.davidyang.work>. Reviewed twice — once
for internal contradictions, once adversarially by Codex. What follows
incorporates both, plus what building it actually taught us.

Where a decision changed during the build, it is marked **REVISED** and says
why. `PROGRESS.md` is the tracker; this is the reasoning behind it.

---

## 1. Decisions, settled

### Platform

| | | Why |
| --- | --- | --- |
| **Vercel, Hobby** | `ducky.davidyang.work` | Personal card, not sold. **The day BY-002 is something people buy, this needs Pro.** |
| **One CNAME at Cargo** | `ducky` → `cname.vercel-dns.com` | The apex never moves. That is the whole reason this is not Cloudflare Workers. |
| **Turso (libSQL)** | the database | It is SQLite, so the schema and SQL dialect carry over. **The client API does not** — see §3. |
| **Remote primary only. No embedded replicas.** | | Embedded replicas read locally and write remotely, so a fire ignited during one request can be invisible to the next. Read-your-writes is load-bearing here, not a nicety. |
| **No minute-scale cron** | Hobby crons are daily, and a finer expression fails at deploy | Fire ignites **on read**; `burning` is `now - lit_at < 90s`, computed, so nothing runs to put one out. The daily cron only sweeps sessions, nonces and spent rate-limit windows. |

### Routes

```
/                 the pond            → api/shell.ts
/d/<slug>         public duck page    → api/duck-page.ts   SERVER-RENDERED
/e/<key>          private edit page   → api/duck-edit.ts   noindex
/pondkeeper       admin               → Phase 4; not routed yet
/api/*            everything else     → api/router.ts       (rewritten)
```

**There is no `public/index.html`, deliberately.** Vercel's CDN serves a
static file before any function runs, so an index.html would mean `/` could
never exchange a tap for a session — and that exchange has exactly one
chance to happen. The shell is rendered by `src/worker/shell.ts`, which is
also what gives `/d/<slug>` real link previews and `<html lang>` a correct
value before Phase 6 needs one.

### Card identity

**The MCU's serial.** `SIGROW.SERNUM[9:0]` on the ATtiny1616 — ten bytes,
factory-programmed, read-only. Not the ST25DV's UID, because the programmer
already reads `SIGROW` while flashing, so the host can record every serial
with no extra step. The NFC chip's UID lives where the programmer cannot see
it.

Eight Crockford base32 characters from the low 40 bits (no I, L, O or U).
**This is not collision-proof, it is collision-*unlikely*** — about 4 in a
billion across a hundred cards. `cards.id` is a primary key, so a collision
would make two physical cards indistinguishable. The import step rejects a
duplicate loudly rather than overwriting.

**An unknown serial degrades, it does not fail.** The serial is derived twice
— in C on the MCU, in Python on the host — so a byte-order or bit-range
disagreement would make *every* card unknown at once. The visitor still gets
their fortune and a working pond; the duck is simply unattributed and the card
is flagged in admin. **Shared test vectors** (§ Phase 2) are what stop this
from happening at all.

### The claim credential

The earlier design — a counter `&g=NN`, accepted if unseen — was not a
credential. Everything in the URL is typed text, so an unseen counter proves
only that nobody has used *that number* yet. Anyone who learned a serial could
walk the counter space by hand.

**The card signs its claim.**

```
token = SipHash-2-4( FIRMWARE_SECRET, serial ‖ counter )   truncated to 40 bits
URL   = /?d=<digit>&c=<serial>&g=<counter>&t=<token>
```

- `FIRMWARE_SECRET` is a 128-bit constant compiled into the binary. Every card
  has the same one, so the firmware is still **identical on every board** and
  there is still no per-card data.
- SipHash-2-4 because it is built for exactly this: short messages, keyed,
  ~200 bytes of code, fast on an 8-bit AVR. HMAC-SHA256 would work and is
  overkill on 2 KB of RAM.
- The counter is **16-bit** in EEPROM. Four hex characters, 65,536 gestures —
  it never wraps in practice, so there is no wrap semantics to define.
- The server accepts a claim when the token verifies **and** the counter is
  greater than the highest it has seen for that card. Both, not either.
- **Increment EEPROM first, then write the NDEF.** If the write fails, the
  counter has advanced and the card shows a stale token — the next gesture
  advances again and writes correctly. The other order lets a consumed
  counter reappear, which is the one outcome that breaks the scheme.
- Claim attempts are rate-limited per card and per visitor. Ten a day is
  generous for a gesture that requires opening a battery holder.

**What this stops:** forging a claim without the secret, and replaying a
claim URL you saw over someone's shoulder.

**What it does not stop, stated plainly:**

- **Extracting `FIRMWARE_SECRET` from a card.** Set the ATtiny lock bits, and
  accept that a determined attacker with physical possession and a programmer
  wins. For a hundred cards given to friends that is proportionate; if these
  are ever sold, this needs a per-card key written at flash time instead.
- **Someone who physically holds the card claiming it.** That is the design,
  not a flaw — possession *is* the credential.
- **Racing the legitimate keeper.** Anyone who can see the armed URL was
  standing next to the card, which is the same bar. First writer wins.
- **Rewriting the tag.** RF write protection is not configured; see
  `SECURITY.md`.

### The pond

- **It wraps.** No edges. Deleting clamping deleted most of the camera bugs in
  this project. Every distance measures the short way round.
- **No scenery for now.** Later, maybe.
- Zoom is `CELL` ∈ `{2,3,4,6,8}`, **4 is home**. Integers only.
- Position and zoom interpolate together, one motion; the sub-integer
  remainder is a CSS scale on an overscanned canvas.
- **Bump**, not wave. Ten unreturned bumps and it is their turn.
- The **whistle** is the duck count.

Full detail in `POND-CAMERA.md`.

### Card keepers — in the first build

Four blows during the battery-insert boot window arms config; the next tap
opens Card setup, carrying the signed claim above.

- `card_epochs` — a card has a *succession of keepers*, not an owner. Ducks
  and contacts carry `epoch_id`, **`ON DELETE SET NULL`, never CASCADE.**
- A keeper can name the card, link their own duck, set the language, and adopt
  the ducks that predate their claim.
- **No custom link.** Anyone who wants their card to point elsewhere can
  rewrite the tag. Removing it deletes an open-redirect risk on this domain.
- Contact scope is **nobody / the keeper / the keeper and David**, named as
  people, scoped to the epoch — consent was given to Sam, so Mika never
  inherits it. **In the schema "nobody" is the absence of a row**, not a
  third value: choosing it means nothing is stored, which is a stronger
  promise than storing a flag that says not to look.

### Language — in the first build

English and 繁體中文. Keeper sets the default; **the visitor's phone wins**.
`lang` must be correct or Chinese readers get Japanese letterforms. CJK uses
system faces. The uppercase-and-tracked label style needs a parallel rule.
大吉 · 小吉 · 末吉 · 凶 need no translation. **User content is never
translated.**

### Privacy, non-negotiable

- The duck card **never** shows the card serial. It shows `via <keeper>`,
  resolved through the epoch, or nothing.
- Contacts live in their own table the public read module never names,
  enforced by test. The one module that may write to it is `release.ts`, and
  nothing reads a contact back out until Phase 4.
- "Take my duck out" deletes the duck and its contact **in one statement**.
  **REVISED:** this used to rest on `ON DELETE CASCADE`, and therefore on a
  per-connection pragma that cannot be verified without a deployed database.
  It is now a trigger, `ducks_before_delete`, which fires either way — see
  §3, Phase 1b.

---

## 2. The contract — FROZEN as of Phase 1b ✅

Phase 3 builds nine screens against this. Changing it afterwards means
changing them twice. Nothing was deployed, so `0001_init.sql` was edited
directly — writing a migration against a database that has never existed is
cargo cult.

**From the first deploy onward this file is closed and `0002_*.sql` opens.**

| Area | Was missing | Landed as |
| --- | --- | --- |
| **Bumps** | `waves` was wave-shaped — a number on a duck. | `bumps(from_duck, to_duck, total)`. The cap is one upsert: `WHERE sent − received < 10`. "Bump back" is the reverse row; "Most bumps from" is a query. **Authenticated by the bumper's edit key** — an unauthenticated cap lets anyone spend a stranger's allowance, which makes it a weapon rather than a courtesy. |
| **Keepers** | `card_epochs` did not exist. | It does. Ducks and contacts carry a nullable `epoch_id`, `ON DELETE SET NULL`, never CASCADE — ending a tenure must never delete a stranger's duck. A partial unique index enforces one current keeper per card. |
| **`via <keeper>`** | `PublicDuck` had no keeper field. | `keeper: string \| null`, resolved through the epoch. |
| **Contact scope** | `contacts` had only `duck_id`, `value`, `created`. | `scope` ∈ `david` / `keeper` / `keeper_and_david`, plus `epoch_id` so consent expires with the keeper it was given to. **"Nobody" is spelled *no row at all*** — nothing stored is nothing to leak. **REVISED:** the plan listed three options and the default was `keeper_and_david`; the contact screen says "Want David to reply?" and "Only David sees this", so that default stored consent WIDER than the sentence the person read. `david` was added and made the default. On David's own card all three collapse to the same reader — it only matters on the ninety-nine somebody else keeps. |
| **Reports** | Stored neither reason nor note. | Both, `CHECK`ed against the four buttons in COPY.md, one per visitor per duck so the button is idempotent. |
| **Language** | No column on `card_epochs`. | `lang`, and `pickLanguage()` already negotiates it against the visitor's phone. |
| **Card serial** | Had to come **out** of the duck payload. | It was never in it — the real work was making sure it never gets in. `card_id` is admin-only, the public read resolves the epoch, and a test greps for both. |

---

## 3. Build order

### Phase 1a — the Turso adapter *(half a day, on its own)*

Before any route is ported. This is where the port's real risk lives.

- A two-method interface the worker modules talk to, so the 42 tests keep
  running locally and `src/worker/*.ts` need not change.
- Map D1 shapes: `.prepare().bind().run()/first()/all()` and **`meta.changes`**,
  which the extinguish and rename paths depend on for correctness, onto
  libSQL's `execute` / `batch` / `transaction`.
- **`PRAGMA foreign_keys = ON` per connection.** SQLite defaults it *off* and
  it is per-connection, so a pooled Turso HTTP connection can arrive without
  it. **REVISED — this is no longer what the promise rests on.** See Phase 1b.
- Multi-statement writes become `batch`, not two awaits. The known offenders:
  bump insert + counter, extinguish + rescue credit, release + session claim +
  contact. Each currently has a window where a crash leaves a half-state.
  **Two of the three were deleted rather than batched** — see Phase 1b.

**Done when** the existing tests pass against real libSQL — including a test
that deletes a duck and asserts the contact row is gone. ✅

### Phase 1b — the port and the freeze ✅ *(built; deploy outstanding)*

- `src/worker/index.ts` becomes `handle(req, env, path)`, which knows nothing
  about Vercel; `api/router.ts` hands it a `Request` and the path.
  **REVISED:** this was a filename catch-all, `api/[...path].ts`, chosen to
  avoid a rewrite handing the function its destination path instead of the
  real one. It deployed fine and matched exactly one segment — `/api/pond`
  worked, `/api/duck/by-slug/<slug>` never reached our code. Zero-config
  `/api` does not expand a catch-all across segments. It is a rewrite now,
  like every other route here, and the matched segments come back as
  `__path` for `api/router.ts` to reassemble.
- `api/sweep.ts` for the daily cron, behind the `CRON_SECRET` bearer check.
- Fire ignition moves into `GET /api/pond`.
- Apply the §2 contract changes.
- Replace the Wrangler/D1 scripts in `package.json`.
- Deploy. Add the CNAME. Confirm the certificate. ✅

**Done when** `curl https://ducky.davidyang.work/api/pond` returns JSON *and*
`npm run db:verify` reports the contact gone. ✅ Both, plus the full
tap → release → bump → report → delete flow, against the live domain.

> The old "half a day for the whole port" was wrong, and I had been told so
> once before publishing it. A day and a half was closer, and the shape of the
> time was not what the estimate assumed: the routing was mechanical, and the
> schema freeze was where the thinking went.

#### REVISED: the deletion promise is a trigger, not a cascade

The plan said `connect()` should assert the pragma and refuse to serve if it
was off. Building it made the flaw obvious: **that gate cannot be verified
without deploying, and if the answer were "off" the site would not boot.**
Downtime, in exchange for no safety — because the promise was resting on the
pragma either way.

So the promise moved into the schema. `ducks_before_delete` deletes the
contact, the bumps in both directions, the fires, the says and the reports,
and releases the references that would otherwise pin the row. **A trigger
fires whether or not foreign keys are on.** Every deletion test now runs
twice, once with the pragma deliberately off, and `npm run db:verify` proves
it against the real database in ten seconds.

**Postscript: the pragma does survive.** Run against the real Turso primary,
`db:verify` reports `foreign_keys: ON` — the client holds a stateful
connection, so the setting persists between `execute()` calls. The work was
not wasted: it turned a question the whole port was blocked behind into a
second layer of defence, and the trigger still covers delete paths that do
not exist yet.

It also covers every delete path that will ever exist — including the admin
screens in Phase 4 — without anyone having to remember this file.

#### The bug the freeze was for

`sessions.spent_duck` referenced `ducks(id)` with **no ON DELETE action**, so
it pinned the duck it pointed at. "Take my duck out", inside the 30-minute
session window, raised a foreign key violation and left the contact behind.
With foreign keys off it silently succeeded. Two environments, two behaviours,
and the failing one was the ordinary case: release a duck, change your mind.

Phase 1a's tests missed it because the fixture built ducks by hand rather than
through a session. **A fixture that skips the real write path is a test that
agrees with you.**

#### REVISED: two things deleted rather than built

- **The denormalised counters.** `ducks.wave_count` and `rescue_count` are
  gone; bumps and rescues are derived at read time. A stored total beside the
  per-pair table it is supposed to equal is a drift waiting to happen, and
  keeping them in step needed a second write with a window in the middle.
- **The `rescues` table.** Credit belongs to whoever won the `out_at IS NULL`
  race — one person — and `fires.out_by` already recorded exactly that. The
  table could only ever hold one row per fire saying the same thing.
  Deleting it collapsed `extinguish()` to a **single atomic statement** whose
  `meta.changes` is both "you won" and "you are credited".

Two of the three half-state windows §1a set out to close were closed by
removing the second write, not by wrapping it.

### Phase 2 — one real card ⬅ NEXT *(a day, plus bench time)*

Firmware first: it is the part that can surprise us.

Provisioning is a **state machine**, not a script:

```
  UNPROVISIONED ──write record──► WRITTEN ──readback ok──► PROVISIONED
        ▲                            │
        └────────── mismatch ────────┘
```

- The flag is a **versioned magic plus CRC**, not one byte. A single byte can
  be corrupted mid-write into something that looks provisioned, stranding a
  card with a broken record and no way to notice.
- Write the whole NDEF record, read it back, compare, and only then set the
  flag. A card that fails verification retries next power-up.
- **68 bytes**, not the ~45 this plan first guessed — the record grew by the
  serial, the counter and the token. At `NDEF_EEPROM_WRITE_MS` per byte that
  is **~408 ms** of first-boot write. Confirm it completes inside the boot
  window and survives a brownout mid-record. (Page writes would cut this to
  a handful of cycles; single-byte reuses the already-proven retry path, so
  that is an optimisation for after the first two cards work.)
- **Shared test vectors.** ✅ `shared/firmware/card-identity/card-identity.json`
  — generated from the C, consumed by both sides, so neither implementation
  is the reference for the other. **REVISED: the serial is hashed, not
  sliced.** "The low 40 bits" of SERNUM is lot number, wafer number and die
  coordinates; a hundred cards from one reel share a lot, so any fixed
  window is partly constant across the batch and the 4-in-a-billion estimate
  would not have been true of it. Hashing all ten bytes with a public
  domain-separation key makes it honest, and costs nothing because SipHash
  is already in the binary for the token.
- Write `tools/record-card.sh` — referenced by `PROVISIONING.md`, does not
  exist — and **import `cards.csv` into the `cards` table**, rejecting
  duplicates loudly.
- ✅ `config.h` updated: an eight-character `&c=`, plus `&g=` and `&t=`. The
  digit offset is now DERIVED from the strings in `ndef_record.h` and the
  literal in config.h is checked against it from two directions — a native C
  test and a pond test that greps the line.

**Done when** the `&c=` in the tapped URL matches, character for character,
the row the flashing script wrote — on two cards flashed from one binary.
"Two cards open two pages" would pass with the derivations disagreeing.

### Phase 3 — the client *(the biggest piece)*

Nine screens against the real API. `src/client/` already holds the sprites,
the flame generator and the codec.

pond → arrival → studio → sign → contact → release → duck card → come back →
settings.

Build the contact screen's **scope picker** now, not in Phase 5 — keepers ship
in this build, so doing it later means building that screen twice. Build
against the **deployed** API from the first screen; the prototype proved the
UI, the seam is what is unproven.

### Phase 4 — admin *(a day)*

`/pondkeeper`. Ducks, Contacts, Cards. Hide/unhide, reply, postcard state, CSV
download. No spreadsheet sync — a CSV cannot drift out of step with a deleted
contact.

### Phase 5 — keepers *(a day, plus firmware)*

The blow gesture, the signed claim, `card_epochs`, Card setup. The schema and
API for this landed in Phase 1; this is the behaviour.

### Phase 6 — 繁體中文 *(half a day)*

~80 strings from `COPY.md`, the font stack, the `lang` attribute, the
untracked label variant.

---

## 4. Secrets

| | |
| --- | --- |
| `SESSION_SECRET` | HMAC key for session cookies and visitor hashes. |
| `ADMIN_PASSWORD` | The real lock on `/pondkeeper`. |
| `TURSO_URL` / `TURSO_TOKEN` | libSQL connection. |
| `CRON_SECRET` | Vercel sends this as a bearer token; reject anything else. |
| `CARD_SECRET` | The server's copy of `FIRMWARE_SECRET`, for verifying claim tokens. |

---

## 5. Known gaps, carried deliberately

- ~~**Rate limits are documented but not implemented.**~~ **Done in 1b.**
  `src/worker/limits.ts`, a fixed window in a single upsert. 60/day per card
  (a card gets passed round a table — that is the point) and 10/day per
  visitor. Both numbers are guesses and should be revisited after the first
  evening a card is actually used.
- **Payload at scale.** Every duck carries a 384-character paint layer, so a
  thousand ducks is ~400 KB. Fine at a hundred cards; the fix is fetch by
  region and recency. Written down, not built.
- **RF write protection on the ST25DV is not configured.** Anyone with an NFC
  writer can overwrite a tag. Out of scope, and the reason the keeper's custom
  link was dropped rather than secured.

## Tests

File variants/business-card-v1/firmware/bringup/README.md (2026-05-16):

# bringup firmware

Smoke-test firmware for a freshly-soldered business-card-v1. The goal is to **prove each subsystem works in isolation** before chasing bugs in the production firmware (where everything runs at once and root-causing is harder).

## Test modes

Selected at compile time via `BRINGUP_MODE` in [`src/config.h`](src/config.h). No button on the PCB, so there is no run-time selector; reflash via SerialUPDI to switch modes.

| Mode | Test | What it proves |
|---|---|---|
| **0** *(default)* | Auto-cycle through tests 1, 2, 3 with 3 s dwell each. | First-light smoke test — flash once, see all three indicator subsystems in turn. |
| 1 | **LED walking-bank** — light each of the 9 cathode banks in sequence (200 ms each). | Every MOSFET, every cathode-bank trace, every LED solder joint. A dead LED shows up as a missing dot in its bank. *(Individual-LED walking is not possible on this PCB — all 24 anodes go to VCC through individual current-limit resistors, so an LED is lit exactly when its bank's MOSFET is on.)* |
| 2 | **Full at low PWM duty** — software-PWM all banks together at ~8 % duty. | Forward-voltage variance across the LED batch (dim/bright outliers), and the global rail under sustained load. |
| 3 | **Mic envelope** — free-run ADC0 on PC0, peak-and-decay envelope, VU-meter bank fill. | Mic biasing, ADC reference, and the analog routing. |
| 4 | **I²C scan** — scan 0x08..0x77 with internal pull-ups enabled, look for ST25DV04K at 0x53. | SDA/SCL routing and the NFC tag itself. Result is reported by LED pattern: **bank 0 blinks @ 2 Hz on success, bank 8 blinks @ 5 Hz on failure.** *(0x53 is the 7-bit form of the `0xA6` address from the datasheet — `0xA6` is the address shifted left for the 8-bit R/W form.)* |
| 5 | **Sleep / wake** — sleep in `SLEEP_MODE_PWR_DOWN`, wake every 4 s via the RTC PIT (running off the 32.768 kHz ULP osc), pulse bank 0 for 50 ms. | Sleep current target < 1 µA. Measure with a multimeter in series with the CR2032. *(The PCB has no button or NFC GPO wired to the MCU, so we wake from the internal PIT rather than an external pin interrupt.)* |

## Power-budget guidance

| Mode | Avg current | Peak | Power source |
|---|---|---|---|
| 1 walking-bank | ~5–10 mA (one bank lit at a time) | same | CR2032 OK indefinitely. |
| 2 full @ 8 % duty | ~38 mA avg | ~480 mA for ~80 µs per PWM period | Bench supply recommended; CR2032 will sag visibly but BOD-off keeps the MCU running. |
| 3 mic envelope | 5–80 mA, depends on loudness | up to full-on mask | Bench supply recommended; coin-cell ESR can swamp the mic noise floor. |
| 4 I²C scan | < 5 mA scanning, ~10 mA blinking | same | CR2032 fine. |
| 5 sleep / wake | **target < 1 µA** between blinks; ~10 mA for the 50 ms blink every 4 s | same | CR2032 — and this is the test where coin-cell ESR vs. bench supply changes the *measurement*. |

> Tunable via `src/config.h`: PWM duty for test 2, frame rate / bank-step threshold for test 3, PIT period and blink width for test 5.

## Source layout

```
src/
  main.cpp                       BRINGUP_MODE dispatcher
  config.h                       BRINGUP_MODE + per-test tunables
  pins.h                         pin map (verified against netlist.ipc)
  leds.{h,cpp}                   bank driver (active-high MOSFET gates)
  unused_pins.h                  disable input buffer on idle pins
  tests/
    test_walking_banks.{h,cpp}
    test_full_low_pwm.{h,cpp}
    test_mic_envelope.{h,cpp}
    test_i2c_scan.{h,cpp}
    test_sleep_wake.{h,cpp}
```

## Build & flash

```
cd insert-coin/variants/business-card-v1/firmware
pio run -e bringup -t upload --upload-port /dev/cu.usbserial-XXXX
```

To change mode, edit `BRINGUP_MODE` in `src/config.h` and reflash.

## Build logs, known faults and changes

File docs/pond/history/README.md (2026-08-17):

# How the pond got built

**These are a record, not instructions.** They describe what was planned and
in what order — not how the pond works now. Where one of them disagrees with
a document in the folder above, the one above is right.

They are kept because the reasoning in them is sometimes still the answer to
"why is it like this", and that reasoning is not written down anywhere else.

| | |
|---|---|
| [BUILD-PLAN.md](BUILD-PLAN.md) | The original plan: every decision and the order to build in. |
| [REBUILD-PLAN.md](REBUILD-PLAN.md) | Agreed 13 Aug 2026, after the first build drifted from the signed-off prototype. The plan for bringing it back. |
| [PROGRESS.md](PROGRESS.md) | The tracker that ran alongside both. |

For what exists today, start at [../README.md](../README.md).

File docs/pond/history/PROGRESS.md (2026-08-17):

# Progress

The tracker. Tick things off here as they land; `BUILD-PLAN.md` is the
detail behind each line.

**Branch** `pond` · **PR** [#11](https://github.com/PowerPlane/insert-coin/pull/11)
· **Tests** 180 + 100 native C · **Live** <https://ducky.davidyang.work>

---

## The shape of it, in one paragraph

Tap an NFC business card, get one of four fortunes, decorate the duck you were
dealt, sign it, optionally leave a private contact, and release it into a
shared pond that everyone else's ducks are already floating in. Ducks live
forever. You can bump other people's, put out the ones that catch fire, and
whistle to gather everyone from one friend's card. About a hundred cards, all
flashed identically, each giving itself an identity on first boot.

---

## Phases

| | Phase | State | Notes |
| --- | --- | --- | --- |
| **1a** | Turso adapter | ✅ **done** | D1-shaped interface, batch, `meta.changes`. |
| **1b** | Port to Vercel | ✅ **done, deployed** | Contract frozen, routes ported. Live and verified end to end. |
| **2** | One real card | ✅ **done** | Two cards flashed, recorded, tapped, imported. Attribution proved on production. |
| **3** | The client | ✅ **done** | All ten screens, the camera with inertia and pinch, the whistle, and the four arrivals. Matched to the prototype. |
| **4** | Admin | ✅ **done** | `/pondkeeper` — ducks, contacts, cards, CSV, behind the password. |
| **5** | Keepers | ✅ **done, deployed** | Signed claim, succession of epochs, Card setup. Replay, rollback and forgery all refused on production. |
| **6** | 繁體中文 | ✅ **done, deployed** | Full table, coverage enforced by the type system. Verified live at `zh-TW`. |

---

## Deployed, and verified end to end

Live at <https://ducky.davidyang.work> — Vercel Hobby, Turso remote primary,
one CNAME at Cargo. Verified against the real domain, not a preview URL:

| | |
| --- | --- |
| `GET /api/pond` | 200, `{"ducks":[],"now":…}` |
| `npm run db:verify` | the contact is gone, the session released its reference |
| `/?d=1` | sets `pond_s` — the tap really does become a session |
| release → bump → report → delete | every step, through the live API |
| `/d/<slug>` | server-rendered `og:title`, indexable |
| `/e/<key>` | `x-robots-tag: noindex`, nothing about the duck in the document |
| `/api/sweep` without a bearer token | 404 |
| `accept-language: zh-TW` | `<html lang="zh-Hant">` |

The pond is empty on purpose: every duck made while testing was deleted
through the API, which is itself the proof that deleting works.

### Two things only the deploy could find

Both were invisible locally, and both now have a test that fails without
having to deploy again.

**1 · Extensionless imports 500'd every route.** Vercel transpiles each file
separately rather than bundling, and with `"type": "module"` Node's ESM
loader treats `from "./env"` as a literal path. Every relative import now
carries `.js`. The 90 tests passing at the time could not have caught it —
Vitest loads through Vite, which resolves the way a bundler does, so **the
test environment was more forgiving than production**, which is the one
direction it must never differ in.

**2 · Half the API was unreachable.** `api/[...path].ts` was chosen over a
rewrite so the router would see the real path. It deployed cleanly and then
matched exactly ONE path segment: `/api/pond` worked, `/api/duck/by-slug/…`
returned Vercel's own `NOT_FOUND` without invoking our code. Zero-config
`/api` does not expand a catch-all across segments. `/api/*` is a rewrite
now, like every other route here, and `api/router.ts` reassembles the path
from `__path`.

`test/deploy-shape.test.ts` exists because of these: it asserts the things
that are invisible locally and fatal in production — extensions on every
relative import, the absence of `public/index.html`, that referenced assets
exist, and that the `/api/*` rewrite is still there.

---

## Phase 3 — where it stands

**Working on the live site, walked end to end in a browser:**

| | |
| --- | --- |
| The pond | Water, ducks, camera. Also the visitor state — someone who taps with no coin gets exactly this. |
| Camera | Integer zoom ladder, wrapping world, **inertia** and **pinch**, +/− controls. |
| Arrival → studio → sign → contact → release → keep | The whole making flow. 12 tints, 32 stickers, 15 paint colours, brush/erase/undo/clear. |
| Duck card | Bump (authenticated by your own edit key) and report (reason + note, idempotent). |
| `/e/<key>` | Your duck later, message & settings, redecorate, and **take my duck out**. |
| The whistle | Tap the count, pick a card. Called ducks arc to a loose ring; everyone else is pushed clear of the frame. "3 of 5" while active. |

**The deletion promise, kept through the UI rather than through SQL:** made
a duck with a contact, opened its private link, tapped through to the
confirmation, removed it — 2 contacts became 1, the duck's rows went to 0,
and no orphans. That is what Phase 1a's adapter was built for, now closed
by a person tapping buttons.

### Inertia and pinch — added, with no prototype behind them

The first camera behaviour with nothing to port from, so the reasoning
lives in POND-CAMERA.md: exponential decay at `tau = 325ms`, velocity from
a ~120 ms buffer so a deliberate pause does not fling, closed-form travel
so a dropped frame does not lose distance, and a pinch anchored on the
centroid. No rubber-banding, ever — the world wraps, so there are no edges.

### The arrivals, and the visual match

All four are in: 大吉 fireworks (seven shapes, two waves, the loudest by a
tested margin), 小吉 flowers leaving petals for three minutes, 末吉 a sun a
cloud drifts over, 凶 already alight until the water puts it out. The
sparkle engine's 170 ms hold is tested by the property it exists for —
there is a moment when every pixel of a shape is on at once.

**The screens were rebuilt against the prototype**, which had never actually
been opened: the palette, the gold buttons with their 4px shadow, the
two-step pixel corner, the uppercase mono voice, the serif headings, the
typefaces, and — most of all — sheets that rise over water that stays
visible rather than a flat panel that replaces it.

### Phase 4 — done

`/pondkeeper`, behind the password, with the path treated as convenience
rather than a secret. Ducks (hide, unhide, clear reports), Contacts (the one
place a contact is ever read, with its consent stated in names), Cards, and
a CSV generated on demand rather than synced.

**The first migration.** `0001` closed when the database went live, so admin
state is `0002` and `db:apply` is a migration runner with a ledger — plus a
baseline step for the production database, which predates the ledger.

---

## Phase 2 — where it stands

**Done, and testable without hardware:**

- `shared/firmware/card-identity/` — the serial, the claim token, CRC-8 and
  the provisioning flag, as Arduino-free C that compiles for the AVR and the
  host. 100 native checks, including all 64 SipHash reference vectors
  fetched from veorq/SipHash rather than recalled.
- **`card-identity.json` — the pinned spec.** Generated from the C, consumed
  by both sides. Neither implementation is the reference for the other,
  because the failure this guards against (the two derivations disagreeing)
  makes every card unknown at once and does it silently.
- `ndef_record.h` — the whole 68-byte record, every offset derived from the
  strings at compile time. The digit offset comes out at `0x0023`, which is
  what config.h had as a magic number; it is now checked from both sides.
- `pond/src/card/` — the host half, plus the cards.csv parser and importer.
  The importer re-derives every serial from its own recorded SERNUM and
  refuses the whole file on any disagreement.
- `record-card.sh`, `secrets.h.example`, and the gitignore entries for the
  two things that must never be committed.

> **REVISED: the serial is hashed, not sliced.** "The low 40 bits" of
> SIGROW.SERNUM is lot number, wafer number and die coordinates — a hundred
> cards from one reel share a lot, so any fixed window is partly constant
> across the batch and the 4-in-a-billion collision estimate would not have
> been true of it. Hashing all ten bytes makes it honest and costs nothing.

- **The firmware**, written, compiled and now FLASHED. `provision.cpp` is the
  state machine PROVISIONING.md specified; the whole-record write reuses the
  retry wrapper the digit patch already proved. Flash sits at 59.2%.

**It works on real silicon.** 2026-08-12, first card:

```
SERNUM   3054304c493268721626
recorded 0YBSVSVN
tapped   /?d=1&c=0YBSVSVN&g=0000&t=5d29221795
```

Character for character. The whole first-boot chain ran — read SIGROW, hash,
sign, build 68 bytes, write, read back, compare, seal EEPROM — and `?d=1`
means the show ran and patched the digit afterwards, so the ~408 ms write
fits inside the boot window. Those values are pinned in
`card-identity.test.ts` as the one vector not generated by our own code.

### Both cards, and the loop closed on production

```
card 1   SERNUM 3054304c493268721626  ->  0YBSVSVN
card 2   SERNUM 3054304c493247482406  ->  G5JNY9HG
```

Both `&c=` values match what the host derives, character for character.
Both imported into the production `cards` table. Then, tapping card 1's real
URL against the live site and releasing a duck:

```
duck     JDBQdbNBxy
card_id  0YBSVSVN          <- attributed
epoch_id null              <- expected; keepers are Phase 5
public   id,slug,fortune,tint,stickers,paint,name,message,
         created,bumps,rescues,burning,say,keeper
         serial appears nowhere
```

An unknown serial (`ZZZZZZZZ`) still mints a session and still gives a
fortune — the deliberate degrade, not an error.

**The second card immediately earned itself.** `record-card.sh` failed on it:
avrdude does not zero-pad, so a byte below 0x10 prints as `0x6` rather than
`0x06`, and the parser produced nineteen characters instead of twenty. Card
1 happened to have all ten bytes ≥ 0x10. `1 - (15/16)^10` = **48% of cards
would have failed to record**, and one card could never have shown it. The
firmware was never wrong — it reads SIGROW directly and had already written
the right serial into its tag.

The two real SERNUMs also settled the derivation argument: their first SIX
bytes are identical, because both chips came off one reel. Sixty per cent of
the entropy is gone before you start, which is exactly why the serial hashes
all ten bytes rather than slicing "the low 40 bits".

**Left, and neither is about correctness:** brownout mid-write, and whether
a FAILED provision is distinguishable from a success at a glance. Both in
PROVISIONING.md.

### The bench runbook

Everything above is arithmetic and can be proved on a desk. These three
cannot, and PROVISIONING.md has said so from the start:

- **68 bytes on first boot**, ~408 ms at `NDEF_EEPROM_WRITE_MS`. Confirm it
  finishes inside the boot window and survives a brownout mid-record. (Page
  writes would cut this to a handful of cycles — an optimisation for after
  two cards work, not before.)
- **`SIGROW.SERNUM` is distinct across real chips from one reel.** Less
  load-bearing than it was, now the serial is a hash of all ten bytes, but
  two chips with an identical SERNUM would still collide.
- **The LED confirmation is unmistakable**, since it is the only signal a
  card is finished.

**Done when** the `&c=` in the tapped URL matches, character for character,
the row `record-card.sh` wrote — on TWO cards flashed from one binary. Two,
because "two cards open two pages" would pass with the derivations
disagreeing.

---

## Phase 1a — done

`pond/src/db/`. A D1-shaped interface (`prepare().bind().first()/run()/all()`,
`meta.changes`) so `src/worker/*.ts` never learned what platform it was on.
`batch()` for multi-statement writes, proved to roll back. `meta.changes`
proved to report rows *changed*, not matched — `extinguish()` still credits a
rescue on exactly that.

---

## Phase 1b — done

### The foreign-key question, answered by not needing an answer

1a ended with one honest gap: whether `PRAGMA foreign_keys` survives Turso's
HTTP mode on a remote primary could not be checked without a real database.
**So the answer was made not to matter** — and then, once a database existed,
it was checked anyway.

> **ANSWERED, 2026-08-12, against the real Turso primary: it is ON.**
> `connect()` sets the pragma in one `execute()` and reads it back in a
> separate one, so the libSQL client is holding a stateful connection rather
> than firing independent stateless requests. `npm run db:verify` reports
> `foreign_keys on this connection: ON` and all four checks pass.
>
> The trigger stays regardless. It is what makes the promise true on every
> delete path that will ever exist — including the Phase 4 admin screens —
> and it costs nothing. The pragma being on is now a second layer rather
> than the only one.

`ducks_before_delete` in `0001_init.sql` deletes the contact, the bumps in
both directions, the fires, the says and the reports, and releases the
references that would otherwise pin the row. A trigger fires whether or not
foreign keys are on, so **every deletion test runs twice** — once with the
pragma on, once with it deliberately off — and passes both ways.

> **Changed from the plan.** BUILD-PLAN said `connect()` should refuse to
> serve if it could not read the pragma back as ON. It no longer does, for
> remote databases. That gate could not be verified without deploying, and
> if the answer had been "off" the site simply would not have booted —
> downtime bought no safety, because the promise rested on the pragma
> either way. It warns; `npm run db:verify` is the real check, against the
> real database, in ten seconds.

### The bug that fell out of it

`sessions.spent_duck` referenced `ducks(id)` with **no ON DELETE action**, so
it pinned the duck it pointed at. Taking your duck out inside the 30-minute
session window raised a foreign key violation and left the contact behind —
in the most ordinary case there is, releasing a duck and changing your mind.
With foreign keys off it "worked", silently: two environments, two
behaviours, one broken promise.

1a's tests missed it because the fixture built ducks by hand and never went
through a session. The route-level harness in `test/routes.test.ts` exists so
that class of gap closes.

### The contract, frozen

| Area | What landed |
| --- | --- |
| **Bumps** | Replace waves. Per-pair and directional, ten-unreturned cap in one upsert, "bump back" derivable, "Most bumps from" a query. Authenticated by the bumper's edit key — an unauthenticated cap is a weapon. |
| **Keepers** | `card_epochs`. Ducks and contacts carry `epoch_id`, `ON DELETE SET NULL`. Keeper name and language live on the epoch. |
| **`via <keeper>`** | `PublicDuck.keeper`, resolved through the epoch. |
| **Contact scope** | `david` / `keeper` / `keeper_and_david`, defaulting to `david`. "Nobody" is spelled *no row at all*. |
| **Reports** | Reason + note, one per visitor per duck, idempotent. |
| **Card serial** | Out of every public payload, with a test that greps for it. |
| **Deleted** | The denormalised bump/rescue counters (derived now, cannot drift) and the whole `rescues` table — `fires.out_by` already recorded the one person who won. Extinguish is now a single atomic statement. |

### The port

- `handle(req, env)` takes a web `Request` and knows nothing about Vercel.
  `api/router.ts` is a few lines. `/api/*` reaches it by rewrite and hands
  the real path back as `__path` — a filename catch-all (`api/[...path].ts`)
  deployed cleanly and then matched only ONE path segment, so every route
  with a slash in it returned Vercel's own 404 without invoking our code.
- **No `public/index.html`, deliberately.** The CDN serves a static file
  before a function runs, and `/` is where a tap becomes a session. The shell
  is server-rendered, which also buys real link previews on `/d/<slug>` and a
  correct `<html lang>` before Phase 6 needs one.
- Fire ignition moved into `GET /api/pond`.
- **Rate limits implemented**, not just described. `SECURITY.md` had promised
  them for a while; a documented control that does not exist reads exactly
  like one that does.
- `api/sweep.ts` sweeps sessions, nonces and rate-limit windows behind the
  `CRON_SECRET` bearer check — including the nonces `HOSTING.md` always
  claimed were being swept.
- `pond/public/` un-ignored. It was ignored from when Wrangler built the
  client into it; on Vercel it is the output directory, served verbatim and
  generated by nothing, so ignoring it would have deployed a blank page.

---

## Phases 5 and 6 — done, and what they turned up

Both are live. 224 tests, `tsc` clean.

### The bug that had already happened three times

`field()` ran the caller's `onInput` once during construction to seed its
character count. Those handlers reference siblings — a hint, a scope picker —
and siblings are usually declared BELOW the field, so the call landed in the
temporal dead zone and threw. Because every screen begins with
`replaceChildren()`, the throw emptied the page: the contact screen, the
pond's count, and then Card setup, all presenting as a blank or broken
screen with nothing to search for.

Each earlier fix reordered the caller, which is correct locally and leaves
the trap set for the next screen. `field()` now does not call `onInput`
during construction at all — the caller passed the value in and already
knows it.

**The suite stayed green through all three**, because nothing in it rendered
a DOM. jsdom is now a dev dependency and `test/dom.test.ts` covers the
primitives. The two tests that matter were checked by putting the old
behaviour back: they fail with `ReferenceError: Cannot access 'hint' before
initialization`.

One thing removing that call broke, immediately: the contact screen was
getting its initial scope-picker visibility FROM the construction-time
callback. It now calls `syncScope()` explicitly. The dependency is the
same; it is written down rather than being a side effect of building a
text field.

### A consent feature that had silently disabled itself

The contact screen offers "share with Sam" only when there is a Sam to
name, and it was learning that name by inference on the client: collect the
keepers of every duck on screen, and if they all agree, use that. Its own
comment claimed it looked at ducks "from this card" — but the pond payload
deliberately does not say which card a duck came from, so it never filtered.

One keeper in the pond and it worked. Two and the set had two names, the
inference gave up and returned null, and the option stopped appearing — in
exactly the situation the pond exists for. It was already dead on
production, with six ducks from two cards.

The name now comes from the tapped card's current epoch, carried on the
session. Reaching it needs a session and a session needs the card in hand,
so it is not a way to enumerate keeper names from a guessed serial — and
the name is public anyway: every duck already reads "via Sam".

### A string the table could not reach

The arrival heading was built in the screen as `${jp} · ${en}`, so it stayed
half-English however the reader had asked to be spoken to — on the loudest
screen in the product. It is `fortuneTitle()` now, which glosses only for
English. 大吉 is already Chinese; appending "Great luck" glosses into a
language the reader is not reading.

### 繁體中文

`ZH_HANT` is typed `Record<StringKey, string>`, so coverage is a compile
error, not a test — a key added to English and forgotten here will not
typecheck. Entries that legitimately match English (names, URLs, the zoom
glyphs, the two language buttons) are written out rather than omitted, so
"identical on purpose" stays distinguishable from "nobody has done this
yet". Tests cover the two things the compiler cannot see: that no
translation drops or invents a `{placeholder}`, and that the table was not
filled in by copying English.

Negotiation verified on production: `zh-TW` and `zh-HK` get `zh-Hant`;
`zh-CN` falls through to English rather than being served the wrong script.

---

## Open questions

- **0YBSVSVN's claim counter is ahead of the physical card.** Testing the
  signed-claim flow needed armed URLs, and minting them with the real
  firmware key advanced the SERVER's high-water mark to 4 while the CARD's
  EEPROM never moved. The rule is `counter > claim_counter`, strictly, so
  the next real blow-four-times ritual arms at 1 and is refused as "already
  used" — indistinguishable by eye from a genuine replay. Repair staged at
  `~/pond-backups/REPAIR-0YBSVSVN.sql`; a full dump was taken first. **Run
  it before tapping that card.** Minting against a card that anybody is
  going to physically tap was the mistake; a card reserved for it would
  have cost nothing.

- **KS0KEKBX is a bench card, deliberately left broken.** Flashed before
  `secrets.h` was filled in, so its claim token is signed with the all-zero
  placeholder, and it is not in `cards.csv`. Harmless as a test card — it
  still deals fortunes, its ducks are just unattributed — but it must be
  erased and reflashed before it goes to anybody.
  `npm run cards:check` identifies it in three seconds.

None blocking. Everything below has a decision; these are worth revisiting
once something is running.

- `CARD_SECRET` is one secret across all cards. Fine for a hundred among
  friends; needs a per-card key if these are ever sold.
- Payload at scale: ~400 KB at a thousand ducks. Fix is fetch-by-region.
- RF write protection on the ST25DV is not configured.
- **Contact scope wording.** The screens must say it in NAMES ("shared with
  Sam and David"), never as a value. Phase 3 writes those strings.
  The schema stores three, and the default is the narrowest: the contact
  screen asks "Want David to reply?" and answers "Only David sees this", so
  somebody who never opens a picker has agreed to exactly that. A default of
  `keeper_and_david` would have shared it with a person the screen never
  named — caught on review, while the freeze was still open.
- Rate limits are 60/day per card and 10/day per visitor. Guesses, not
  measurements. Revisit after the first evening a card gets passed round.

---

## Log

| Date | |
| --- | --- |
| 2026-08-12 | Design complete. Prototype at nine screens, copy deck, UI rules. |
| 2026-08-12 | Plan reviewed twice — internally, then adversarially by Codex. Claim counter replaced with a signed token; Turso FK trap caught; port estimate corrected. |
| 2026-08-12 | **Phase 1a landed.** 49 tests. |
| 2026-08-12 | **Phase 1b landed.** Contract frozen, routes ported, 90 tests. The deletion promise moved from a cascade to a trigger and is now proved with foreign keys off. `sessions.spent_duck` found pinning the duck it pointed at. Not deployed. |
| 2026-08-13 | **Phase 5 landed.** Signed claim, epochs, Card setup. Replay, counter rollback, forged token and unknown card all refused with 403 on production. |
| 2026-08-13 | **Phase 6 landed.** 繁體中文 complete, coverage enforced by the type system, verified live at `zh-TW`. |
| 2026-08-13 | `field()` stopped calling `onInput` during construction — the cause of three blank screens. jsdom added; the guard was mutation-tested. |
| 2026-08-13 | The keeper's name moved off client-side inference onto the session. It had been returning null, and the consent option missing, whenever the pond held two keepers. |

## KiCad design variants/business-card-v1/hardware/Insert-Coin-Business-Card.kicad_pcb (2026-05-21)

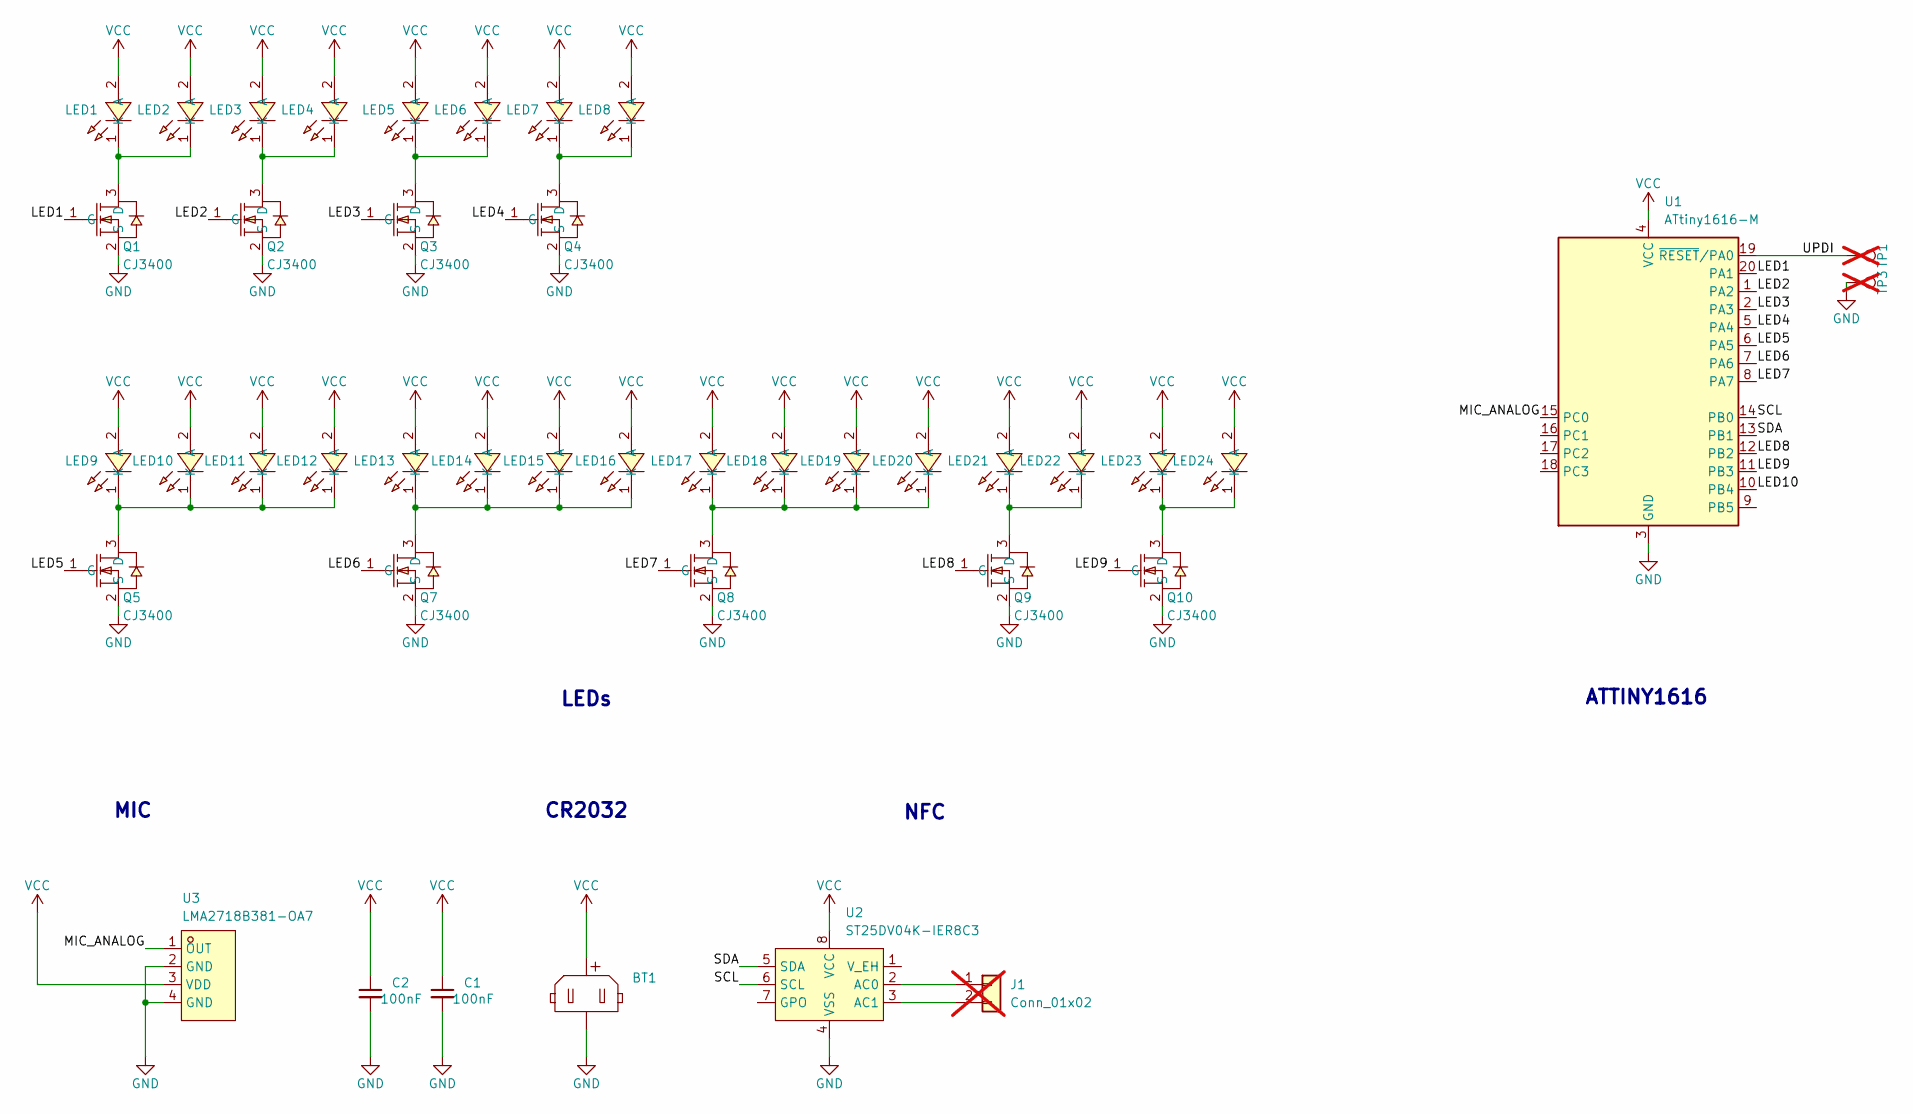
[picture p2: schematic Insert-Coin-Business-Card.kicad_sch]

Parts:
BT1: Battery-Holder_Coin-Cell_CR2032_Linx_BAT-HLD-001; BAT-SMD_MY-2032-08
C1, C2: 100nF; C_0805; Voltage 50V; Tolerance 100%; LCSC C28233
J1: Conn_01x02; NFC_Mini_Antenna_22x22_ST25DV04K; not fitted
LED1, LED2, LED3, LED4, LED5, LED6, LED7, LED8, LED9, LED10, LED11, LED12, LED13, LED14, LED15, LED16, LED17, LED18, LED19, LED20: XL-1606UYC; LED-SMD_L1.7-W1.1-RD_RED-SIDE; MPN XL-1606SURC; LCSC C965862
LED21, LED22: XL-1606UOC; LED-SMD_L1.7-W1.1-RD_RED-SIDE; MPN XL-1606SURC; LCSC C965861
LED23, LED24: XL-1606SURC; LED-SMD_L1.7-W1.1-RD_RED-SIDE; MPN XL-1606SURC; LCSC C965860
Q1, Q2, Q3, Q4, Q5, Q7, Q8, Q9, Q10: CJ3400; SOT23-3; MPN CJ3400; LCSC C19019
TP1, TP3: 1.0mm; DUCKY_ICON_2.54_Spacing; not fitted
U1: ATtiny1616-M; VQFN-20-1EP_3x3mm_P0.4mm_EP1.7x1.7mm; LCSC C507118
U2: ST25DV04K-IER8C3; DFN-8-1EP_3x2mm_P0.5mm_EP1.36x1.46mm; LCSC C5221756
U3: LMA2718B381-OA7; MIC-SMD_4P-L2.8-W1.9_LMA2718B381-OA7; MPN LMA2718B381-OA7; LCSC Part C5373222

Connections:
/LED1: Q1.1 (G), U1.20 (PA1)
/LED2: Q2.1 (G), U1.1 (PA2)
/LED3: Q3.1 (G), U1.2 (PA3)
/LED4: Q4.1 (G), U1.5 (PA4)
/LED5: Q5.1 (G), U1.6 (PA5)
/LED6: Q7.1 (G), U1.7 (PA6)
/LED7: Q8.1 (G), U1.8 (PA7)
/LED8: Q9.1 (G), U1.12 (PB2)
/LED9: Q10.1 (G), U1.11 (PB3)
/LED10: U1.10 (PB4)
/MIC_ANALOG: U1.15 (PC0), U3.1 (OUT)
/SCL: U1.14 (PB0), U2.6 (SCL)
/SDA: U1.13 (PB1), U2.5 (SDA)
/UPDI: TP1.1 (1_1), U1.19 (~RESET/PA0)
GND: BT1.2 (-), C1.2, C2.2, Q1.2 (S), Q2.2 (S), Q3.2 (S), Q4.2 (S), Q5.2 (S), Q7.2 (S), Q8.2 (S), Q9.2 (S), Q10.2 (S), TP3.1 (1_1), U1.3 (GND), U1.21 (GND), U2.4 (VSS), U3.2 (GND), U3.4 (GND)
unnamed: J1.1, U2.2 (AC0)
unnamed: J1.2, U2.3 (AC1)
unnamed: LED1.1 (K), LED2.1 (K), Q1.3 (D)
unnamed: LED3.1 (K), LED4.1 (K), Q2.3 (D)
unnamed: LED5.1 (K), LED6.1 (K), Q3.3 (D)
unnamed: LED7.1 (K), LED8.1 (K), Q4.3 (D)
unnamed: LED9.1 (K), LED10.1 (K), LED11.1 (K), LED12.1 (K), Q5.3 (D)
unnamed: LED13.1 (K), LED14.1 (K), LED15.1 (K), LED16.1 (K), Q7.3 (D)
unnamed: LED17.1 (K), LED18.1 (K), LED19.1 (K), LED20.1 (K), Q8.3 (D)
unnamed: LED21.1 (K), LED22.1 (K), Q9.3 (D)
unnamed: LED23.1 (K), LED24.1 (K), Q10.3 (D)
VCC: BT1.1 (+), C1.1, C2.1, LED1.2 (A), LED2.2 (A), LED3.2 (A), LED4.2 (A), LED5.2 (A), LED6.2 (A), LED7.2 (A), LED8.2 (A), LED9.2 (A), LED10.2 (A), LED11.2 (A), LED12.2 (A), LED13.2 (A), LED14.2 (A), LED15.2 (A), LED16.2 (A), LED17.2 (A), LED18.2 (A), LED19.2 (A), LED20.2 (A), LED21.2 (A), LED22.2 (A), LED23.2 (A), LED24.2 (A), U1.4 (VCC), U2.8 (VCC), U3.3 (VDD)

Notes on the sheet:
NFC
LEDs
CR2032
ATTINY1616
MIC

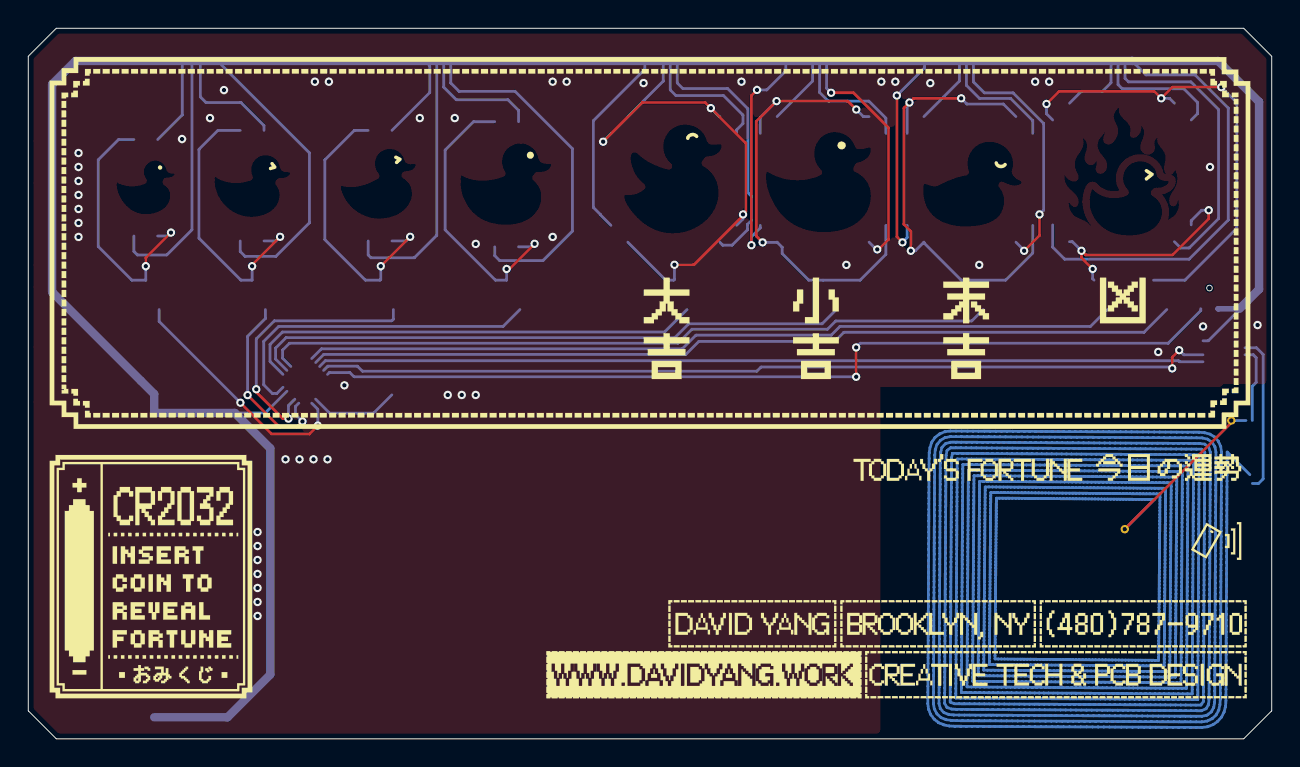
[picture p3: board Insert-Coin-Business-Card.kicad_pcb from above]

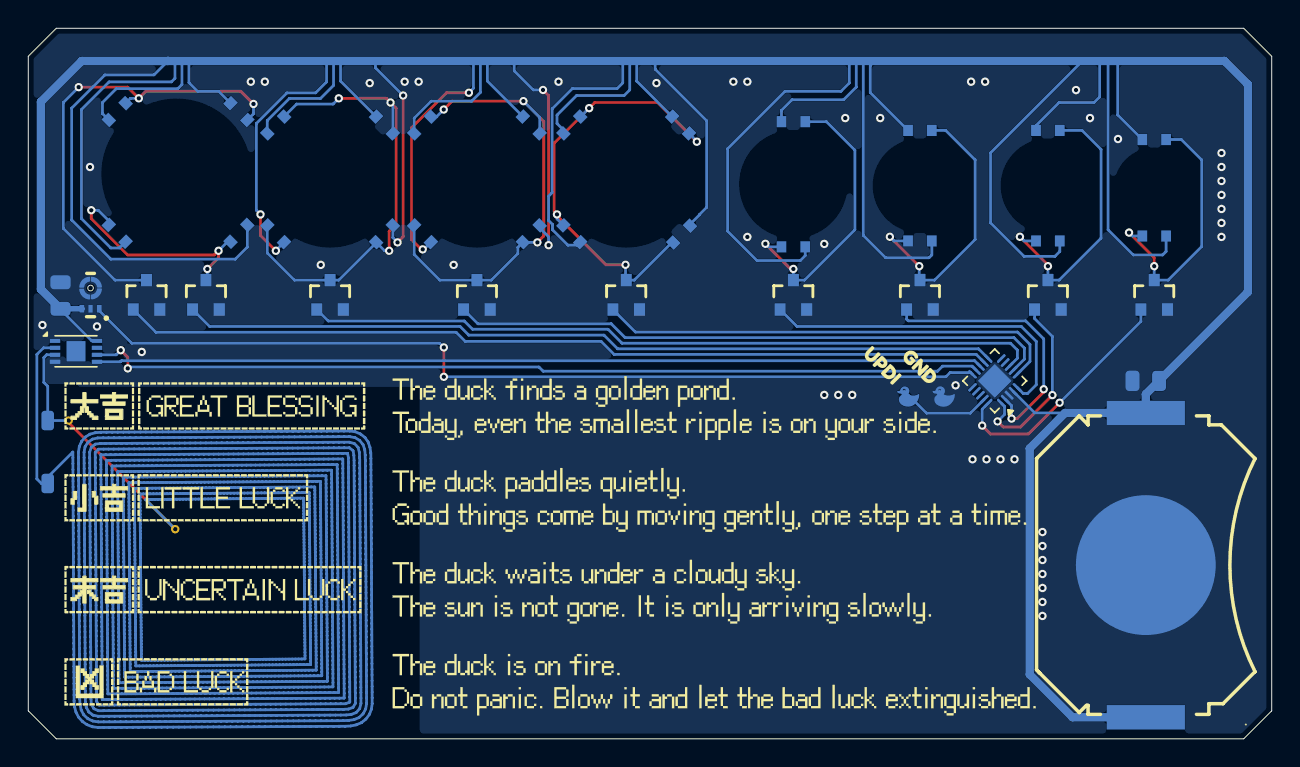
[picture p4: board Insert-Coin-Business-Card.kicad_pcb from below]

Board: 2 copper layers, 88.9 x 50.8 mm, 44 parts (44 on the bottom side), 26 nets.

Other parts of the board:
kibuzzard-6A02DFFE: G***; kibuzzard-6A02DFFE
kibuzzard-6A02E019: G***; kibuzzard-6A02E019

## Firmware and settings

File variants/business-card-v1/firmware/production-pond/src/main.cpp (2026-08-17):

// business-card-v1 production-pond firmware -- entry point.
//
// Same show as production-nfc, pointed at the pond instead of the plain
// site, with three changes that only matter once a web app is treating
// the tag as a ticket rather than as decoration:
//
//   1. boot capture      -- bank 0 ramps in, dips, holds
//   2. ducky walk        -- banks 0->3 stop-motion
//   3. lottery           -- pick fortune from hardware-seeded RNG
//   4. NDEF patch        -- I2C-write fortune digit ('1'..'4') so the next
//                           tap lands on https://ducky.davidyang.work/?d=N&c=...
//                           Retried on NACK (see ndef.cpp). Happens before
//                           the reveal, so taps during the LED show already
//                           see the new URL.
//   5. reveal            -- banks 4..8 per fortune
//   6. 300 s timed sleep -- the URL stays live long enough for someone to
//                           finish watching, talk about it, and then tap
//   7. NDEF reset        -- restore '0' so a later tap gets the read-only
//                           pond rather than a stale fortune
//   8. sleep forever     -- coin pull is the only restart
//
// Differences from production-nfc, and why:
//
//   * NDEF_EXPIRY_SECONDS is 300, not 120. The most common real failure
//     is someone watching the lights, chatting, and tapping too late.
//     This required widening the constant AND sleep_timed_seconds() to
//     16-bit -- at uint8_t, 300 wraps to 44 and the window gets SHORTER.
//
//   * NDEF writes retry. RF wins arbitration against I2C on the ST25DV,
//     so a phone resting on the card during the show can NACK the patch.
//     production-nfc ignores the return value, which silently serves the
//     previous visitor's fortune -- on the pond that means claiming
//     someone else's duck.
//
//   * The digit offset is 0x0023, and it is DERIVED rather than chosen:
//     shared/firmware/card-identity/ndef_record.h computes it from the URL
//     strings at compile time, so the constant in config.h cannot drift
//     from the record it indexes. The per-card "&c=", "&g=" and "&t=" all
//     go AFTER the digit, so every card runs this same binary.

#include <Arduino.h>

#include "anim.h"
#include "claim.h"
#include "config.h"
#include "leds.h"
#include "mic.h"
#include "ndef.h"
#include "provision.h"
#include "pins.h"
#include "pwm.h"
#include "rng.h"
#include "sleepy.h"
#include "unused_pins.h"

/*
 * Retire whatever this boot put on the tag, then sleep for good.
 *
 * Extracted because there are now two ways to reach it — a fortune's live
 * window, and setup mode — and the rules for leaving are identical and
 * fiddly enough that a second copy would drift. Never returns.
 */
[[noreturn]] static void clear_and_sleep(bool patched, bool armed) {
    (void)patched;
    // Restore the default so a later tap lands on the read-only pond
    // instead of an expired fortune.
    //
    // This one genuinely matters, so it is not best-effort: going to
    // terminal sleep with a stale digit still live means the NEXT person to
    // tap this card claims a duck they did not earn, and nothing wakes the
    // MCU to fix it until someone pulls the coin. Each ndef_patch_default()
    // already retries NDEF_WRITE_ATTEMPTS times internally; if RF is still
    // holding the bus, back off a second and try the whole sequence again.
    bool still_armed = armed;
    for (uint8_t round = 0; round < NDEF_CLEAR_ROUNDS; round++) {
        ndef_init();
        const bool cleared = ndef_patch_default();
        // An armed URL left armed is a claim lying on the floor: anyone who
        // picks the card up next taps into somebody else's setup screen.
        // Cleared on the same schedule as the fortune, for the same reason.
        if (still_armed && claim_disarm()) still_armed = false;
        ndef_deinit();
        if (cleared && !still_armed) break;
        // Almost certainly a phone parked on the antenna. Sleeping a second
        // costs nothing here and is the most likely way for it to move.
        sleep_timed_seconds(1);
    }

    /*
     * ══ NEVER SLEEP STILL ARMED ══
     * The loop above gives up after NDEF_CLEAR_ROUNDS. For a stale fortune
     * that is an acceptable loss — the worst case is somebody seeing luck
     * they did not earn. For a live CLAIM it is not: the counter is already
     * spent in EEPROM, so the URL on the tag stays valid until somebody
     * rewrites it, and the next person to tap this card walks into the
     * keeper's setup screen.
     *
     * Bumping the counter again does not help — the server has not seen the
     * exposed one either, so it would still be accepted. The only thing
     * that retires it is getting those bytes rewritten. So the card keeps
     * trying, backing off further each time, and only then sleeps.
     *
     * This costs battery in a case that should never happen (a phone parked
     * on the antenna through the whole sequence), and costs nothing at all
     * in the case that always happens.
     */
    for (uint8_t round = 0; still_armed && round < CLAIM_DISARM_ROUNDS; round++) {
        sleep_timed_seconds((uint16_t)(1u << round));
        ndef_init();
        if (claim_disarm()) still_armed = false;
        ndef_deinit();
    }

    sleep_forever();
}

void setup() {
    bank_init();
    pwm_init();
    configure_unused_pins();
    mic_init();

    // Seed before the show -- ADC noise during quiet boot is plenty. A
    // second harvest happens at the lottery so live ambient sound also
    // colors the outcome.
    rng_seed_from_mic(RNG_SEED_SAMPLES);

    anim_boot_capture();

    /*
     * ══ THE SHOW IS THE CLAIM WINDOW ══
     * The gesture used to have 2.5 s of its own, here, with the LEDs off.
     * It did not work and the bench found it at once: an invisible pause is
     * indistinguishable from the card thinking, and it closed before
     * anybody would react — you had to be blowing already as the coin went
     * in. Blow once the duck was walking and nothing was listening.
     *
     * Now the watcher starts here and the animations pump it between
     * frames, so four blows count whenever they arrive: during the walk,
     * during the lottery, whenever somebody thinks to try.
     */
    /*
     * ══ A POWER CYCLE MUST NOT LEAVE A CLAIM ON THE FLOOR ══
     * `clear_and_sleep` retires the fortune and the claim at the END of a
     * session, and it tries hard — see the note on never sleeping still
     * armed. But it only runs if the card gets to the end. Pull the coin
     * while a fortune is live, or in the five minutes after four blows,
     * and it never runs at all: the tag keeps whatever it was holding,
     * indefinitely, with nothing awake to fix it.
     *
     * Reinserting the coin used not to fix it either. The tag is not
     * touched until after the walk and the lottery, so for the whole boot
     * show a stale digit — or worse, an unspent claim — sat there
     * readable. Anyone tapping in those seconds got a fortune nobody paid
     * for, or walked into somebody else's setup screen.
     *
     * So a boot starts by putting the card back to nothing: no fortune, no
     * claim. Fifteen bytes, about 90 ms, hidden inside a show that runs
     * for seconds — and it happens before the watcher below, so blowing
     * four times on THIS power-up still arms normally.
     *
     * Best effort on purpose. `ndef_write_byte` already retries, the show
     * patches the digit again a moment later, and `clear_and_sleep` is
     * still the belt at the other end. This is the braces.
     */
    ndef_init();
    /*
     * `provision_ensure`, not `provision_ok`. The latter returns a static
     * that only becomes true INSIDE ensure — so gating on it here, before
     * ensure has run for this power-up, meant the whole block was dead
     * code. It compiled, it shipped, and it cleared nothing.
     *
     * Ensure is one EEPROM read on a card that has been provisioned. On a
     * virgin one it writes the whole record, which used to happen after
     * the lottery; doing it here is if anything better, because the tag
     * resolves sooner rather than later in the show.
     */
    if (provision_ensure()) {
        ndef_patch_default();
        claim_disarm();
    }
    ndef_deinit();

    claim_watch_begin();

    delay(POST_BOOT_PAUSE_MS);
    anim_ducky_walk();
    delay(POST_WALK_PAUSE_MS);

    uint8_t fortune = anim_lottery();
    const bool claimed = claim_watch_done();

    /*
     * ══ SETTING A CARD UP IS NOT A TURN AT THE GAME ══
     * A claimed card deals no fortune. It used to deal one anyway, and the
     * result was a tag carrying both a fortune digit and a claim, where the
     * tap opens Card setup and the fortune is simply lost — a coin spent on
     * nothing, and one more thing on the tag to go stale.
     *
     * So the show is over. The tag gets the claim and only the claim.
     */
    if (claimed) {
        ndef_init();
        const bool identified = provision_ensure();
        const bool armed = identified && claim_arm();
        ndef_deinit();

        if (!armed) {
            // Nothing was promised: the tag still holds the counter the
            // server has already retired. Say so unmistakably — an unarmed
            // card opens a duck screen, and finding that out on the phone
            // is finding it out too late.
            mic_deinit();
            anim_claim_failed();
            clear_and_sleep(false, false);
        }

        /*
         * ══ SETUP MODE ══
         * One sweep backwards down the strip, and then the card waits in
         * the dark while the phone does the work. Four more blows retire
         * the claim and end it — the way out for somebody who armed a card
         * they did not mean to, or who has finished and would rather the
         * next tap open a duck.
         *
         * The mic stays up for that, so this is the one path where the CPU
         * is awake through its whole window rather than in a timed sleep.
         * A few milliamps for five minutes is a fraction of a percent of
         * the coin cell, and setting a card up happens once.
         */
        anim_setup_enter();
        const bool left = claim_setup_wait(SETUP_WINDOW_SECONDS);
        mic_deinit();

        // Leaving gets the sweep FORWARDS — the mirror of the way in.
        // Playing the same animation for both would make arriving and
        // leaving a matter of remembering which way the light went.
        if (left) anim_setup_leave();

        // Either way the claim is retired here rather than left on the
        // tag. `clear_and_sleep` keeps trying until it takes — see the
        // note on never sleeping still armed.
        clear_and_sleep(false, true);
    }

    // Only the fire reveal needs the mic. Disabling ADC1 here saves
    // ~25 uA across the great/little/uncertain reveal paths.
    if (fortune != FORTUNE_BAD) {
        mic_deinit();
    }

    // Patch BEFORE the reveal so a tap during the show already picks up
    // the new URL. Worst case (~4 attempts) this is ~75 ms, still not
    // visible against a multi-second LED show, and software PWM hasn't
    // started ramping yet so there's no flicker risk.
    ndef_init();

    // First boot writes the WHOLE record from this chip's own SIGROW
    // serial; every boot after that this is one EEPROM read and returns.
    // It has to happen before the digit is patched, because on a virgin
    // card there is nothing to patch yet.
    //
    // A card that fails to verify stays unprovisioned and retries on the
    // next power-up. It still runs the show — a visitor should not be
    // punished for a bad solder joint — but the tag will not resolve, and
    // the LED confirmation is what tells whoever is flashing it. See
    // docs/pond/PROVISIONING.md.
    const bool identified = provision_ensure();

    /*
     * ══ THE CLAIM, BEFORE THE FORTUNE ══
     * The gesture was listened for above, while the mic was still up. If it
     * landed, the tag gets a fresh counter and a signature over it, and the
     * next tap opens Card setup instead of a duck.
     *
     * Arming is not allowed to cost the fortune: a card whose claim write
     * failed still deals luck, because a visitor should not be punished for
     * a keeper's gesture. The reverse matters more — an arm that only half
     * wrote leaves a signature that does not match its counter, and the
     * server refuses it, which is the right answer for a half-written arm.
     */
    const bool armed = claimed && identified && claim_arm();

    const bool patched = identified && ndef_patch_fortune(fortune);
    ndef_deinit();

    anim_run_reveal(fortune);

    // The bad-luck reveal kept ADC1 alive for its blow detector. Turn it
    // off so the long URL-live sleep isn't dominated by the ~25 uA ADC
    // bias. Safe to call twice.
    mic_deinit();

    // If the patch succeeded, hold the fortune live for the visitor. If it
    // did not, the tag still holds whatever digit was there before --
    // possibly the previous visitor's -- so skip the wait and clear it now
    // rather than spending 300 s advertising someone else's luck.
    if (patched || armed) {
        // RTC-PIT wakes the CPU after NDEF_EXPIRY_SECONDS; the timed sleep
        // draws single-digit uA.
        //
        // An armed card waits too even if the digit did not take: the claim
        // is the thing somebody is standing there waiting to tap, and five
        // minutes is the window they get to find their phone.
        sleep_timed_seconds(NDEF_EXPIRY_SECONDS);
    }

    clear_and_sleep(patched, armed);
}

void loop() {
    // Unreachable: sleep_forever() is [[noreturn]].
}

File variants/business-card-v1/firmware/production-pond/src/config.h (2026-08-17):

// Production firmware tunables.
//
// All timings, brightnesses, and thresholds are constexpr so retuning
// the experience never requires touching logic code. Defaults are the
// values from the approved plan; expect BLOW_THRESHOLD_ADC and
// BLOW_DWELL_MS to need on-hardware adjustment.

#pragma once

#include <stdint.h>

#include "sleepy.h"  // sleep_seconds_t, for the static_assert below

// -- Boot "capture" on bank 0 ---------------------------------------------
constexpr uint16_t BOOT_RAMP_UP_MS = 900;
constexpr uint16_t BOOT_DIP_DOWN_MS = 120;
constexpr uint16_t BOOT_DIP_RECOVER_MS = 120;
constexpr uint8_t BOOT_DIP_DUTY = 35; // % brightness at the dip
constexpr uint8_t BOOT_PEAK_DUTY = 100;
constexpr uint16_t BOOT_HOLD_MS = 400;

// Pause after the boot capture before the walk starts.
constexpr uint16_t POST_BOOT_PAUSE_MS = 250;

// -- Ducky walk across banks 0..3 (stop-motion) ---------------------------
// Dwell times eased: short, long, short, then a brief hold on frame 4.
constexpr uint16_t WALK_DWELL_MS[4] = {180, 380, 280, 180};

// Pause after the walk before the lottery begins.
constexpr uint16_t POST_WALK_PAUSE_MS = 250;

// -- Lottery spin across banks 4, 5, 6, 7+8 -------------------------------
constexpr uint8_t LOTTERY_CYCLES = 10;
constexpr uint16_t LOTTERY_DWELL_MS[LOTTERY_CYCLES] =
    {60, 50, 45, 40, 45, 55, 70, 90, 120, 160};
// Dead beat between the last lottery cycle and the reveal.
constexpr uint16_t LOTTERY_PAUSE_MS = 300;

// -- Reveal: great luck (blinks + symmetric outward ripple + hold) -------
// Total scene ~= 3*(BLINK_ON+OFF) + GREAT_RIPPLE_CYCLES*(MAX_DIST+2)*STEP
//             + GREAT_HOLD_SECONDS*1000 ~= 15 s.
constexpr uint8_t GREAT_BLINK_COUNT = 3;
constexpr uint16_t BLINK_ON_MS = 80;
constexpr uint16_t BLINK_OFF_MS = 80;
constexpr uint16_t GREAT_RIPPLE_STEP_MS = 80;
constexpr uint8_t GREAT_RIPPLE_CYCLES = 5;
constexpr uint8_t GREAT_RIPPLE_PEAK = 100;
constexpr uint8_t GREAT_HOLD_SECONDS = 12;

// -- Reveal: little luck (asymmetric strobing pulse on bank 5 only) ------
// Slow ease-in to peak (anticipation), snap ease-out to a dim floor
// (the "strobe hit"), brief dim hold, repeat. ~3 pulses / sec for the
// LITTLE_PULSE_ACTIVE_MS active stretch, then a sleep-latched bright
// hold for the rest of the reveal budget -- same handoff shape as
// great-luck so the CPU isn't pinned at 10 MHz.
constexpr uint8_t LITTLE_PULSE_LOW = 15; // dim floor (never dark)
constexpr uint8_t LITTLE_PULSE_HIGH = 100;
constexpr uint16_t LITTLE_PULSE_RISE_MS = 250; // slow ease-in
constexpr uint16_t LITTLE_PULSE_FALL_MS = 50;  // snap ease-out
constexpr uint16_t LITTLE_PULSE_DIM_MS = 50;   // brief hold at floor
constexpr uint16_t LITTLE_PULSE_ACTIVE_MS = 3000;
constexpr uint16_t LITTLE_PULSE_SETTLE_MS = 100;
constexpr uint8_t LITTLE_HOLD_SECONDS = 12;

// -- Reveal: uncertain luck (breathing) -----------------------------------
// Widened range (15 %, was 35 %) for a more dramatic breath; same 1.8 s
// period so the pacing feels the same, just deeper.
constexpr uint16_t BREATHE_RAMP_MS = 1200;
constexpr uint16_t BREATHE_PERIOD_MS = 1800;
constexpr uint8_t BREATHE_LOW_DUTY = 15;
constexpr uint8_t BREATHE_HIGH_DUTY = 100;
// Total wall-clock for uncertain reveal (matches the 15 s budget).
constexpr uint16_t UNCERTAIN_TOTAL_MS = 15000;

// -- Reveal: bad luck (fire) ----------------------------------------------
// Candle-flicker frame rate (commercial flicker LEDs run ~14 Hz).
constexpr uint16_t FLAME_FRAME_MS = 70;
// Brightness range: never goes below this, never rises above this.
// Floor at ~30 % keeps the flame visibly "alive" between flickers.
constexpr uint8_t FLAME_FLOOR_DUTY = 30;
constexpr uint8_t FLAME_CEIL_DUTY = 100;
// Per-millisecond approach toward the current target duty. Higher =
// crisper flicker, lower = more molten-looking. 3 looks like real fire.
constexpr uint8_t FLAME_INTERP_STEP = 3;
// Cross-coupling chance (out of 256). When a new orange target is
// chosen, with this probability the red target is nudged the same way.
constexpr uint8_t FLAME_GUST_CHANCE = 64; // 25 %
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

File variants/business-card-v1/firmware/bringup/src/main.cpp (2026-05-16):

// business-card-v1 bring-up firmware -- entry point.
//
// Selects one of six test behaviors at compile time via BRINGUP_MODE
// (see config.h). Because each test's run() is [[noreturn]], the
// Arduino framework's loop() is never reached.

#include <Arduino.h>

#include "config.h"
#include "leds.h"
#include "pins.h"
#include "unused_pins.h"

#include "tests/test_full_low_pwm.h"
#include "tests/test_i2c_scan.h"
#include "tests/test_mic_brightness.h"
#include "tests/test_mic_envelope.h"
#include "tests/test_mic_raw.h"
#include "tests/test_sleep_wake.h"
#include "tests/test_walking_banks.h"

static void setup_common() {
    bank_init();
    configure_unused_pins();
}

#if BRINGUP_MODE == 0
// Auto-cycle through tests 1, 2, 3 with AUTO_CYCLE_DWELL_MS dwell each.
// 4 and 5 are terminal / measurement modes, intentionally skipped here.
[[noreturn]] static void run_auto_cycle() {
    test_mic_envelope::init();
    for (;;) {
        uint32_t deadline;

        deadline = millis() + AUTO_CYCLE_DWELL_MS;
        while ((int32_t)(millis() - deadline) < 0) {
            test_walking_banks::step_once();
        }
        bank_all_off();

        deadline = millis() + AUTO_CYCLE_DWELL_MS;
        while ((int32_t)(millis() - deadline) < 0) {
            test_full_low_pwm::step_once();
        }
        bank_all_off();

        deadline = millis() + AUTO_CYCLE_DWELL_MS;
        while ((int32_t)(millis() - deadline) < 0) {
            test_mic_envelope::step_once();
        }
        bank_all_off();
    }
}
#endif

void setup() {
    setup_common();

#if BRINGUP_MODE == 0
    run_auto_cycle();
#elif BRINGUP_MODE == 1
    test_walking_banks::run();
#elif BRINGUP_MODE == 2
    test_full_low_pwm::run();
#elif BRINGUP_MODE == 3
    test_mic_envelope::run();
#elif BRINGUP_MODE == 4
    test_i2c_scan::run();
#elif BRINGUP_MODE == 5
    test_sleep_wake::run();
#elif BRINGUP_MODE == 6
    test_mic_brightness::run();
#elif BRINGUP_MODE == 7
    test_mic_raw::run();
#else
#error "BRINGUP_MODE must be 0..7"
#endif
}

void loop() {
    // Unreachable: every run() above is [[noreturn]].
}

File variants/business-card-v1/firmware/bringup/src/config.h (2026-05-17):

// Bring-up firmware configuration.
//
// BRINGUP_MODE selects which test runs:
//   0 = auto-cycle (tests 1, 2, 3 in a loop with 3 s pauses)
//   1 = walking banks
//   2 = full at low PWM duty
//   3 = mic envelope (VU-meter: which banks light depends on loudness)
//   4 = I2C scan (terminal — hangs blinking result pattern)
//   5 = sleep / wake (terminal — measure current with multimeter)
//   6 = mic brightness (all banks lit; PWM duty driven by loudness)
//   7 = raw ADC indicator (banks lit = ADC value / 114; diagnostic for
//       mic bias and signal -- see tests/test_mic_raw.h)

#pragma once

#ifndef BRINGUP_MODE
#define BRINGUP_MODE 7
#endif

// Test 1: walking banks
#define WALK_STEP_MS 200

// Test 2: full at low duty
// With 10k current-limit resistors the absolute LED current ceiling is
// ~120 uA per LED (2.9 mA all-on), which is CR2032-friendly even at
// 100 %. The original 8 % choice predated knowing the resistor value;
// 100 % is fine and looks substantially brighter.
#define FULL_PWM_DUTY_PCT 100
#define FULL_PWM_TICK_HZ 1000

// Test 3: mic envelope
#define MIC_SAMPLE_HZ 8000
#define MIC_FRAME_HZ 60
// Per-bank threshold (10-bit ADC units above DC). Tune after first listen.
#define MIC_BANK_STEP 8

// Test 5: sleep / wake
#define SLEEP_PIT_PERIOD_S 4
#define SLEEP_BLINK_MS 50

// Test 6: mic-driven brightness
// FULL_AT is the envelope value (10-bit ADC units above DC) that maps
// to 100 % duty. Lower = more sensitive (saturates earlier). FLOOR is
// the minimum duty even at silence -- a small value (~3 %) keeps the
// LEDs faintly lit so the test is visibly running.
#define MIC_BRIGHTNESS_FLOOR 3
#define MIC_BRIGHTNESS_FULL_AT 2
#define MIC_BRIGHTNESS_PWM_STEP_US 10 // 10 us/step × 100 steps = 1 kHz PWM
#define MIC_BRIGHTNESS_FRAME_MS 17    // ~60 Hz envelope updates

// Auto-cycle mode: how long to dwell on each sub-test before moving on.
#define AUTO_CYCLE_DWELL_MS 3000

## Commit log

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2026-05-16 Add bringup firmware for business-card-v1
    Five compile-time-selectable test modes (BRINGUP_MODE 0..5) plus an
    auto-cycle default for first-light smoke tests:
    - walking banks across the 9 cathode groups
    - full-brightness software PWM (32-bit duty math)
    - mic-driven VU meter (PC0 = ADC1 AIN6, not ADC0)
    - I2C scan for ST25DV04K at 0x53 with internal pull-ups (no
    external pull-ups on the PCB)
    - sleep / wake via RTC PIT, ADCs and input buffers disabled for
    the < 1 uA target
    Also fix platformio.ini: src_dir is a [platformio]-section-only
    option, replaced per-env with build_src_filter.
    [config.h, leds.cpp, main.cpp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]
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2026-05-16 Add BRINGUP_MODE 7 (raw ADC indicator)
    Diagnostic mode for the microphone analog path. Reads ADC1 AIN6 (PC0)
    continuously and maps the raw 10-bit value directly to bank fill (0..9
    banks). No envelope, no DC tracker, no PWM -- the simplest possible
    "what is the ADC seeing right now" display.
    Interpretation:
    0 banks lit, steady ADC ~0 -> mic outputs 0 V (dead)
    ~4-5 banks lit, steady ADC ~512 -> mic at VCC/2 (healthy bias)
    9 banks lit, steady ADC ~1023 -> mic shorted to VCC
    Wobble between banks on sound ADC swings -> mic produces AC signal
    Useful for catching cold joints on the mic, missing bias resistors, or
    PC0 not actually connected to the mic outp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
    [config.h, main.cpp, test_mic_raw.cpp]
2026-05-16 Fix dc_ema initialization for mics not biased at VCC/2
    Both mic tests (mode 3 envelope, mode 6 brightness) hardcoded
    `dc_ema = 512` on the assumption that the mic AC-couples around
    VCC/2. Real MEMS mics bias anywhere from 0.5*VCC to 0.65*VCC; this
    board's ZTS6156 biases at ~1.8 V (0.62 * 2.9 V VCC) -> ADC reading
    ~635, ~123 units above the hardcoded 512.
    The integer-shift EMA update `dc_ema += (x - dc_ema) >> 7;` only
    converges when `|x - dc_ema| >= 128`. With a 123-unit constant gap,
    the right-shift truncates to zero and dc_ema gets stuck at 512
    forever -- the "AC" envelope is then a constant 123, the duty
    saturates at 100 %, and mode 6 LEDs are stuck fully on regardless
    of sound.
    Fix: se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
    [test_mic_brightness.cpp, test_mic_envelope.cpp]
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2026-05-17 Add software PWM, mic envelope, and hardware-seeded RNG modules
    pwm: 9-bank software PWM at 0-100 % per bank, ~1 kHz refresh. Provides
    pwm_hold/fade/fade2 blocking helpers built on millis() so animation
    durations are honored even as the inner tick loop lengthens. Integer
    easing functions (linear, in/out quad) avoid pulling in float math.
    mic: free-running ADC1 on PC0 with peak-and-decay envelope, lifting the
    DC-EMA-seeded-from-first-sample fix from the bringup tree (the ZTS6156
    biases above mid-rail so a hardcoded center would stall the EMA).
    Adds a blow detector that requires the envelope to stay above threshold
    for BLOW_DWELL_MS continuous, so claps and speech don't extinguish the
    flame.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
    [mic.cpp, pwm.cpp]
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2026-05-17 Wire up production firmware: animations + main entry point
    anim.cpp scripts the full one-shot show:
    - boot_capture: pwm-eased ramp + dip + recover + hold on bank 0
    - ducky_walk: hard-cut stop-motion across banks 0..3 with the eased
    dwell pacing the user described (short, long, medium, hold)
    - lottery: 10 accelerating-then-decelerating cycles across banks
    4 / 5 / 6 / 7+8, then a fresh mic re-seed and an unbiased 4-way pick
    via rng_range() with rejection sampling
    - run_reveal dispatches to the per-fortune scene:
    great -> 3 blinks then 15 s hold
    little -> 2 blinks then 15 s hold
    uncertain-> 1.2 s ease ramp, then eased breathing for the rest of
    the 15 s bud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
    [anim.cpp, main.cpp]
2026-05-17 Address codex review: harden blow detector + plug power leaks
    mic: blow detection now reads raw |sample - dc| against the threshold
    with a BLOW_GAP_MS tolerance for AC zero-crossings, instead of the
    peak-and-decay envelope. The old envelope-based check could be tricked
    by a single loud impulse since the decay can outlast BLOW_DWELL_MS.
    Adds mic_deinit() so non-fire fortunes can switch ADC1 off (~25 uA).
    pwm: new pwm_tick_once_with_hook(PhaseHook) lets the flame loop drain
    the mic ADC at PWM frequency without breaking encapsulation. The old
    flame loop called mic_pump_sample() 16 times back-to-back, but
    pump_sample is non-blocking -- it only ever consumed the single
    pending result and then re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
    [anim.cpp, config.h, flame.cpp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]
2026-05-17 Address /review pass: name fortune indices and refresh production README
    pins.h: add FORTUNE_GREAT/LITTLE/UNCERTAIN/BAD/COUNT alongside the
    BANK_* aliases so the lottery is-this-fortune-the-fire-one check
    stops looking like a magic 3.
    main.cpp + anim.cpp: use the named constants. anim_lottery() now reads
    rng_range(FORTUNE_COUNT) and anim_run_reveal() dispatches by name.
    anim.cpp: static_assert REVEAL_HOLD_MS % 1000 == 0 so a future config
    edit that violates the 1 Hz PIT granularity fails the build with a
    clear message instead of silently rounding the hold.
    production/README.md: replace the outdated "src/ is empty" placeholder
    with an accurate description of the show, the per-fortune revea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
    [anim.cpp, main.cpp, pins.h]
2026-05-18 Add great-luck symmetric outward ripple animation
    Replace the static-hold reveal for great-luck with a water-ripple: three
    blinks, then a wave radiates outward from bank 4 in both directions
    (banks 3+5, then 2+6, 1+7, 0+8) with triangular brightness envelopes.
    Five cycles total, then the bank latches digital-high and the chip
    sleeps through the rest of the 15 s budget.
    The ripple is implemented as a shared helper ripple_outward(origin,
    step_ms, peak, cycles) so the same primitive can be reused if other
    fortunes ever want it. Each bank's brightness at time t in [0, cycle_ms)
    is a triangular envelope centered on distance_from_origin * step_ms.
    Compiles at 4732 / 16384 bytes flash, no warning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
    [anim.cpp, config.h]
2026-05-18 Replace little-luck blinks with bounded-random-walk hiccup
    Bank 5 now does a "neon-sign jitter" instead of 2-blink-then-hold:
    brightness wanders in [75, 100] %, never going dark, with ~40 ms per
    random-walk step. The step delta is drawn from [-5..+10] -- an
    asymmetric range so the running mean is pulled toward HIGH and the
    animation reads as "mostly bright, occasionally dips" rather than
    ping-ponging between the two extremes.
    PWM ticks at ~1.5 ms / one duty-unit move per tick interpolate cleanly
    between targets so the eye reads it as fluid jitter, not stepped.
    Removes the now-unused blink_then_hold helper plus its REVEAL_HOLD_MS
    static_assert (great-luck has its own GREAT_HOLD_SECONDS path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
    [anim.cpp, config.h]
2026-05-18 Bad-luck blow-out: air ripple from fire across the card
    When the blow detector fires, replace the simple flare+fast-fade with a
    flare followed by a directional air-ripple that travels from the fire
    banks (7+8) one bank inward per step toward bank 0. Same triangular
    brightness envelope as the great-luck ripple, just one-directional.
    Reads as the breath physically pushing through the card -- fire flares
    on the intake, then the wave of air rolls past the unused fortune banks
    and the four ducky walk frames, leaving everything dark behind it.
    Implementation: new ripple_blow() local helper. fire_anchor = bank 7 so
    banks 7 and 8 share distance 0 (both peak at t=0). Removes the now-
    unused FLARE_F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
    [anim.cpp, config.h]
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2026-05-18 Address /review: extract shared triangle_envelope helper
    ripple_outward() and ripple_blow() duplicated the same triangular wave
    math: peak when |dt| == 0, linear falloff to zero at |dt| == step_ms.
    Factor it into a small inline helper so both ripples read as variations
    of one primitive and the duty arithmetic only lives in one place.
    Overhead is a non-issue -- the helper runs ~5400 times/sec (9 banks
    times ~600 ticks/sec) which is 0.5 % of the 10 MHz CPU even with no
    inlining. No behavior change; flash stays at 4972 bytes.
    [anim.cpp]
2026-05-18 default to production & Kicad Resistor fix
    [Insert-Coin-Business-Card.kicad_sch]
2026-05-18 Little-luck: asymmetric strobing pulse, not random hiccup
    Replace the bounded random-walk "hiccup" with a deliberately rhythmic
    asymmetric pulse on bank 5: slow ease-in to peak (anticipation builds,
    ease_in_quad over 250 ms), snap ease-out to a 15 % dim floor
    (the strobe hit, ease_out_quad over 50 ms), brief 50 ms hold at the
    floor, repeat. ~3 pulses / sec for 3 s active, then the same
    sleep-latched bright hold as great-luck for the remainder of the 15 s
    budget.
    The pulse reads as a deliberate strobing rhythm rather than noise: the
    slow-up / fast-down asymmetry is reinforced both by the duration ratio
    (5:1 rise:fall) and by the easing shape, so the eye sees the LED wind
    up to a peak then sn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
    [anim.cpp, config.h]
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2026-05-20 NFC ducky: post-reveal URL patch + Cargo.site snippet
    Adds a side-by-side production-nfc firmware variant (sibling to
    production) that writes the fortune result to the ST25DV04K NDEF
    EEPROM over I2C after the reveal animation. A pre-programmed URL
    of the form https://davidyang.work/?d=0 is patched in a single byte
    at offset 0x001D to encode the fortune (1..4), then reset to 0 after
    NDEF_EXPIRY_SECONDS so the next visitor lands on the plain page.
    No external I2C pullups on the board; ndef_init() enables the
    ATtiny1616 internal pullups on PB0/PB1 and clocks SCL at 25 kHz so
    the slow rise time stays well inside the data setup window. Out of
    formal I2C spec but reliable on a 1-2 cm trace; escap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
    [anim.cpp, config.h, flame.cpp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]
2026-05-20 Address codex review: deinit mic before NFC sleep, fix README env
    - main.cpp: unconditionally mic_deinit() after anim_run_reveal() so
    bad-luck activations don't keep ADC1 (~25 uA) enabled through the
    60 s URL-live sleep.
    - production-nfc/README.md: replace "pio run -e production" with
    "-e production-nfc" so following the doc actually builds the NFC
    variant.
    [main.cpp]
2026-05-20 Address /review: refresh stale I2C comments in NFC variant
    unused_pins.h and sleepy.cpp were carrying over the original
    production/ rationale that "the show never touches I2C." That's
    no longer true in production-nfc -- ndef_init() flips PB0/PB1
    between input-disable and pullup+TWI across the run. Code was
    already correct (input-disable still runs at the right moments);
    just rewriting the comments so the next reader doesn't get
    misled.
    [sleepy.cpp, unused_pins.h]
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2026-08-12 Add the pond: firmware variant, schema, Worker API
    The web half of BY-002 — davidyang.work/p — where a visitor decorates the
    duck the card dealt them and leaves it with everyone else's.
    Firmware: new `production-pond` PlatformIO env. `production` and
    `production-nfc` are untouched, so every card already flashed keeps working
    exactly as it does today.
    Three firmware changes, each for a reason:
    * Live-URL window 120s → 300s. The most common real failure is watching the
    lights, chatting, then tapping too late. This required widening both
    NDEF_EXPIRY_SECONDS and sleep_timed_seconds() to 16-bit — at uint8_t, 300
    wraps to 44, making the window SHORTER than the one it replaced and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
    [anim.cpp, config.h, flame.cpp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]
2026-08-12 Add paint codec, strict typecheck, and prove both guards fire
    The paint layer's wire format was the one thing the review called
    underspecified. It is now explicit: 24x24 cells, 4 bits each, two per byte,
    high nibble first, row-major -> 288 bytes -> 384 base64 chars, inside the
    schema's 512-char budget. An untouched layer encodes as "" rather than 384
    zeroes, and a corrupt blob decodes to an empty layer instead of throwing,
    because one bad row must not take the pond down for everyone looking at it.
    Both safety nets are verified to actually fail, not just to pass:
    * Temporarily narrowing sleep_seconds_t back to uint8_t breaks the firmware
    build on the static_assert, as intended.
    * Adding a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
2026-08-12 Add client foundation: sprites, stickers, renderer, API layer
    Sprites and stickers are now typed modules rather than loose JS. Sticker art
    is generated by tools/gen-stickers.py from authored ASCII pixel rows, so the
    art stays diffable and hand-editable and the generator asserts every sprite
    is rectangular, has an in-bounds anchor, and uses only known palette codes.
    render.ts carries the two rules taken from the card: nothing tweens
    (positions snap to whole pixels, frames hard-switch) and the clock is uneven
    (the card's own {180,380,280,180} dwell pattern). Composite order is base ->
    paint -> eye -> stickers, so a duck can never lose its face to someone's
    brushwork and a hat is never buried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
2026-08-12 Fix the issues an external code review found
    A Codex review of the committed code turned up three real problems and a
    handful of smaller ones. All fixed, with tests where a test was possible.
    High — createDuck ordering. It set sessions.spent_duck BEFORE inserting the
    duck. sessions.spent_duck has a foreign key to ducks(id) and the schema
    enables PRAGMA foreign_keys, so the claim referenced a row that did not
    exist yet. Insert first, then claim; if the claim loses the race, delete the
    duck rather than leaving one floating that no session admits to owning.
    Medium — extinguish credited losers. Rescue credit was inserted regardless
    of whether the UPDATE ... WHERE out_at IS NULL actually wo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
    [config.h, main.cpp]
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2026-08-12 Studio and flow rework: 7 screens, release in the pond, Dela Gothic One
    Screens 9 -> 7. Release and "keep the link" were separate stages that handed
    you off twice before you arrived anywhere. Now the duck drops into the REAL
    pond — the arrival you watch is the arrival that happened — and the private
    link rises as a one-time sheet once it lands. The link also lives in Settings
    permanently, which is where you look when you have lost it.
    Studio:
    * Dropped the pond-scale preview strip at David's call. I argued for it (the
    studio renders at 12x, the pond at 2x, so detail vanishes) but he tested on
    his phone and disagreed; the canvas is much bigger without it.
    * Undo / clear / surprise ar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
2026-08-12 pond: readable duck URLs, and make burning ducks actually burn
    Slug system. Three separate things that were previously conflated:
    name the words on the duck. Duplicates fine, may be empty.
    slug the URL at /d/<slug>. Unique, readable, renameable.
    edit_key the credential. Secret, at /e/<key>.
    If the readable URL were also the edit link, /d/sam would be guessable and
    anyone could delete anyone's duck, so the public and private pages now live
    on different paths and duckBySlug never selects edit_key. Slugs are
    auto-assigned from 120 adjectives x 80 pond nouns, because making someone
    invent a unique name puts friction on the most important step in the flow.
    The UNIQUE index is t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
2026-08-12 pond: fix the studio nav, and give the whole UI one corner language
    The studio's top row was the worst thing in the flow to use: 10px labels in
    a soft grey with a 20px-tall hit area and no surface, so "Back" and "Skip"
    neither read as buttons nor could be hit reliably, and the screen title was
    whispering at exactly the same weight as they were. Back and Skip are now
    chips with a 67x44 target, and the title is the largest, darkest thing in
    the row so the hierarchy reads title-first.
    Corners: a 99px pill sitting next to a 24x24 sprite is the only shape in the
    pond that could not have been drawn on the grid. Pixel-cutting the two HUD
    chips and leaving everything else rounded would have read as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
2026-08-12 pond: bump cap, keeper + admin screens, and a UI reference to check them against
    Bump gets the poke rule: you can get ten bumps ahead of someone, then it is
    their turn and the button says so ("Sam's turn") rather than failing quietly.
    Bumping back clears the debt. The cooldown drops to 2s -- just long enough
    for the dart to land -- because the cap is what stops spam, not the wait.
    Two new prototype screens:
    08 Card setup the keeper config reached by blowing four times. Name,
    language (English / 繁體中文), optional link with
    fortune-first vs straight-through, and adopting the ducks
    that came from the card before it was claimed.
    09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
2026-08-12 pond: spacing, type floor, a class collision, and reports that carry a reason
    "Everything looks so crowded" was three separate faults.
    A CLASS COLLISION, and the cause of the worst of it. The admin button style
    I added last commit was called .mini — which already existed as the studio's
    small section label (`<p class="mini">Body</p>`). Mine came later in the
    sheet, so it won: the studio's "Body", "Brush" and "Colour" labels were being
    given all:unset, a background, a clip-path and a 44px min-height, which is
    why the draw tab looked broken and its labels overlapped the tabs. Renamed
    to .a-btn.
    A TYPE FLOOR THAT EXISTED ONLY ON PAPER. Sizes ran down to .55rem (8.8px),
    and six places set sm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
2026-08-12 pond: apply the copy review, and fix the extractor that hid half of it
    Codex's rewrites applied across all nine screens. Roughly a third shorter,
    and the terminology now agrees with itself. The substantive ones:
    · "Straight to my link" contradicted the sentence directly beneath it
    ("Never an automatic redirect"). Now "Link first".
    · "Removing your duck" broke the glossary's own "take my duck out".
    · The contact screen switched to first person ("I like mailing postcards")
    while every other screen says David. It says David now.
    · "Adopt the 12 ducks" fought "claimed"/"Unclaim" everywhere else.
    · An em dash was doing UI work in three labels.
    · Card setup 123 → 83 wo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
2026-08-12 pond: rebuild the plan around Codex's five findings
    The adversarial review landed three things that mattered and I had two of them
    wrong in ways worth naming.
    THE CLAIM COUNTER WAS NOT A CREDENTIAL. I wrote "which kills replay" about
    &g=NN, and it does not — it stops reuse of one already-consumed number, and
    nothing else. Everything in the URL is typed text, so an unseen counter proves
    only that nobody used that number yet; anyone who learned a serial could walk
    a 100-value space by hand.
    The card signs its claim now:
    token = SipHash-2-4(FIRMWARE_SECRET, serial ‖ counter) → 40 bits
    /?d=<digit>&c=<serial>&g=<counter>&t=<token>
    One secret compiled into the binary, so the firm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
    [main.cpp]
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2026-08-12 pond: the card writes its own NDEF record, and the digit offset stops being a magic number
    Until now a phone tag-writer wrote the record and the MCU patched one byte
    of it, which meant the layout lived in two places — a comment in config.h
    and whatever somebody typed into an app — joined by NDEF_DIGIT_OFFSET. Get
    that number wrong and the card patches the wrong byte and serves a broken
    URL for the rest of its life, with nothing to notice it but a tap.
    ndef_record.h now derives every offset from the strings at compile time, so
    the digit offset is `sizeof` the prefix rather than something anyone
    maintains. It comes out at 0x0023 — which is what config.h has been
    asserting all along, so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
    [config.h, ndef_record.h]
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2026-08-13 pond: the making flow, and the six things a review found
    Tap to released duck, end to end on the deployed site: arrival with the
    real fortune, studio (12 tints, 32 stickers, 15 paint colours, brush/erase/
    undo/clear), sign, contact with the scope picker, release, keep the link.
    Walked through in a browser against a real card URL — the duck lands with
    its tint, its sticker at the slot origin, its message, and no serial
    anywhere in the payload.
    Three properties that had to be true and now are, checked rather than
    assumed: the edit key is stored BEFORE the screen that shows it renders,
    because a crash between those points would strand a duck nobody can remove;
    the draft clears only after the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
    [main.cpp, mic.cpp]
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2026-08-14 firmware: never sleep still armed, and do not close the window mid-breath
    Two defects from the Codex review of the claim gesture.
    The serious one: a card could go to terminal sleep with a live claim on its
    tag. The clear loop gives up after NDEF_CLEAR_ROUNDS, which is the right
    call for a stale fortune — the worst case there is somebody seeing luck they
    did not earn. It is the wrong call for a claim. The counter is already spent
    in EEPROM, so the URL stays valid until somebody rewrites those bytes, and
    the next person to tap the card walks into the keeper's setup screen.
    Bumping the counter again does not retire it either: the server has not seen
    the exposed one, so it would still be acc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
    [config.h, main.cpp]
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2026-08-15 The four blows are a gesture during the show, not a window before it
    Reported from the bench: the gesture does not work. It did not, and the
    reason is visible the moment you look at what it asked of a person.
    `claim_listen()` opened for 2.5 s immediately after the boot flash, with
    `show_count(0)` turning every LED off. So the window was INVISIBLE — it
    looks exactly like the card thinking — and it closed before anybody would
    react. In practice you had to already be blowing as you pushed the coin
    in. Blow once the duck started walking and nothing was listening: the mic
    is only re-armed during a 凶 reveal, where a blow means "put the fire
    out" instead.
    So there is no window any more. The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
    [anim.cpp, config.h, main.cpp]
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2026-08-16 A power cycle no longer leaves a claim on the floor
    David asked for it and the hole is real.
    `clear_and_sleep` retires the fortune and the claim at the END of a
    session, and it tries hard — see the note on never sleeping still armed.
    But it only runs if the card gets to the end. Pull the coin while a
    fortune is live, or in the five minutes after four blows, and it never
    runs at all: the tag keeps whatever it was holding, indefinitely, with
    nothing awake to fix it.
    Reinserting the coin did not fix it either. The tag is not touched until
    after the walk and the lottery, so for the whole boot show a stale digit
    — or worse, an unspent claim — sat there readable. Anyone tapping in
    those se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
    [main.cpp]
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2026-08-16 A question is not an answer, and dead code clears nothing
    Three fixes for "the four blows did nothing", which is the hardest
    symptom in this system because every distinct cause produces the same
    silence: the pond, with no question and no explanation.
    ── the latch, client ──────────────────────────────────────────────────
    `claimCard` is explicit that raising the takeover question spends
    nothing: the counter is not advanced and the card stays armed, so that
    declining costs the person nothing. The client recorded EVERY answer
    that reached the server as spent, takeover included.
    So the two h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
    [main.cpp]
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
